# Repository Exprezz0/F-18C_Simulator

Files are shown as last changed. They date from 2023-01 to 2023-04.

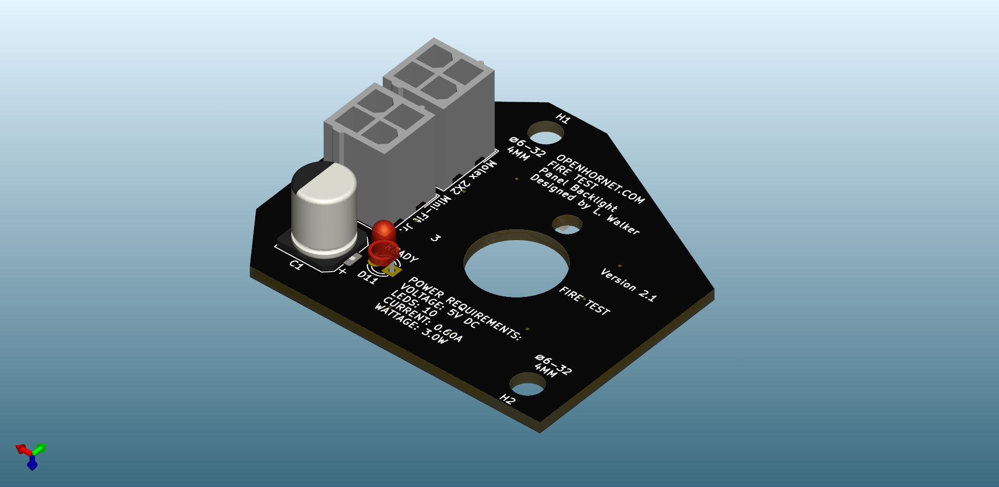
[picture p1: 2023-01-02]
ECAD/PCBs/Backlight PCBs/Backlighting_Type A/FIRE TEST PANEL/Assets/FIRE TEST PANEL_BOT-ISO.png

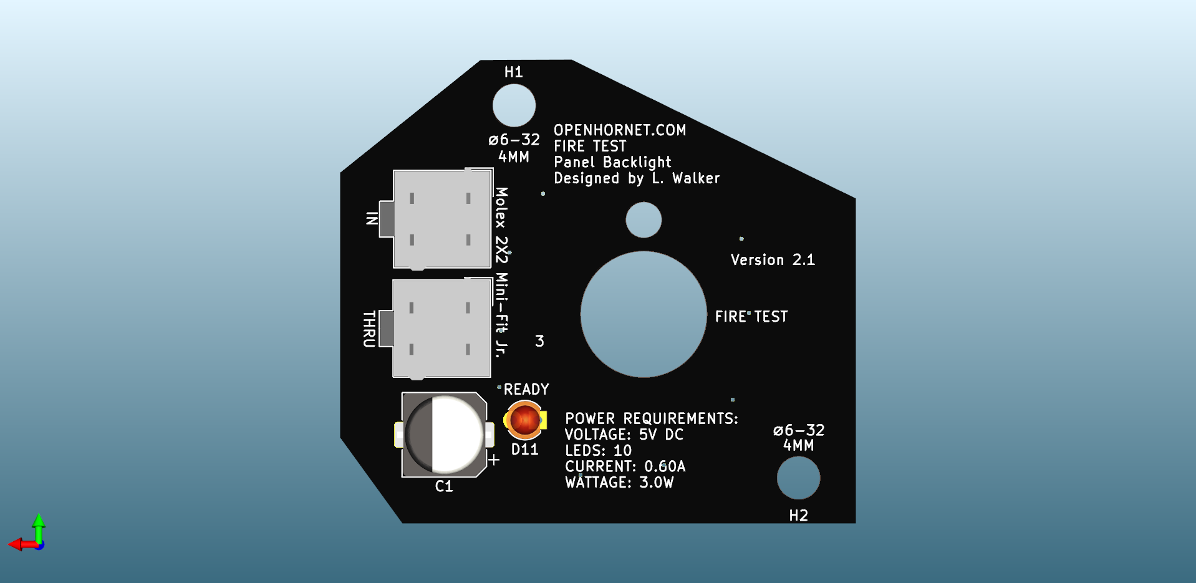
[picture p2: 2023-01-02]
ECAD/PCBs/Backlight PCBs/Backlighting_Type A/FIRE TEST PANEL/Assets/FIRE TEST PANEL_BOT.png

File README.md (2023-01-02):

# F/A-18C Simulator Cockpit
Based on OpenHornet design (https://www.OpenHornet.com) - Modified for Personal Use.  

# Disclaimer
The files located within this repository have been created from scratch or modified from existing OpenHornet files and were adapated to suit my personal needs based on available resources.   There may or may not be easier or more efficient ways to produce some of the systems/designs here, but for the purpose of learning and gaining knowledge and experience designing, engineering, manufacturing, resourcing, etc., I've decided to take the more difficult path.

1:  Any modification, usage, sharing, distribution, etc falls under the same licenses and legal definitions that apply to OpenHornet.

2:  It is not 100% complete.  I will add to it as I continue to progress my own pit.

3:  Use at your own risk.  The files within the repo may or may not be up to date with the current OH design.  I've already cut, printed, and engraved most of the project and have modified various files to fit my own personal needs and resources.

4:  I've done my best to keep it organized.  If you see something out of place (meaning: incorrect directory, not missing.  See #2), please PM me and I'll fix it.

5:  Most importantly, while the files are 94.271% OpenHornet, there are modifications in there.  Please do not reference any files taken from my repository in the OpenHornet Discord.  It's not the developers, contributors, or testers responsibility to answer questions or fix issues associated with 3rd party files.  I'll be more than happy to answer questions offline, and if it relates directly to OpenHornet, we can bring up the issue here.

# File Structure

**This repository has been organized in the following manner:**

The MCAD folder contains all .STL, .SVG, .DXF files types for all mechanical manufacturing.  Within the MCAD folder are the 5 Major Assesmbly Groups: 

```c
* MCAD
     * ASSY, UPPER INSTRUMENT PANEL
     * ASSY, LOWER INSTRUMENT PANEL
     * ASSY, CENTER TUB
     * ASSY, LEFT CONSOLE
     * ASSY, RIGHT CONSOLE
```

 Sub-assemblies for each major group will be broken down into their own individual folders.  Files organic to that sub-assembly will be located in one of several child folders based on the material they are comprised of.  (Resin, PETG, MDF, Acrylic).
    
Additionally, each major assembly will also have:
   1. "**ALL PANEL PLATES**" folder; includes the *Backlight Plate, Light Plate*, and *Legend Plate* folders associated with that major assembly

   2. "**ALL KNOBS**" folder; includes all knobs associated with that major assembly.

   3. "**RANDOM COTS PARTS**" folder; includes any COTS that could be resin printed or manufactured without having to order or purchase.  Examples include gears, bearings, spacers....

   4. "**OBSOLETE**" folder; contains files that are outdated or no longer belong to the OH project.

    * ASSY, RIGHT CONSOLE
        * ALL PANEL PLATES
        * ALL KNOBS
        * OBSOLETE
        * RANDOM COTS PARTS
        * OH5A2A2-1 - ASSY, WING FOLD HANDLE
        * OH5A2A1-1 - ASSY, HOOK LEVER & INDICATOR
        * OH5A1A1-1 - ASSY, RIGHT CONSOLE STRUCTURE
            * ACRYLIC
            * MDF
            * PETG
         
Lastly, each material folder will be broken down into size for reference.  If a part/object is suppose to be printed in PETG or ABS, and you can't find it, try looking in another material folder.  Sometimes I prefered resin printing or using acrylic to the defaulted PETG.

# ECAD Directory

The ECAD folder is set up similar to the MCAD directory (in this repository, and almost as identical to the official OpenHornet repository) and navigating it should be just as easy.  

As of right now, all of the backlit panels have been transitioned to KiCad 6, the libraries associated with the files are consolidated and reorganized, and new manufacturing files that includes TOP and BOTTOM Bill of Materials (BOM) have been created to facilitate easier ordering from JLCPCB.com.

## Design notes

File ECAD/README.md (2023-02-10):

OH logo
* [OpenHornet Website](https://www.openhornet.com)
* [OpenHornet Discord](https://discord.gg/G5PA5ju)
* [Donate to OpenHornet](https://www.openhornet.com/campaigns/donate/)

# **ECAD DIRECTORY INFORMATION**

The purpose of this guide is to help enable the end-user to successfully accomplish the following:  
*   1:  Facilitate navigation of the file structure.
*   2:  Provide clarification regarding the manufacturing process of PCB's related to OpenHornet using JLCPCB.com
*   2:  How to install KiCad 6 and set up libraries associated with OpenHornet. _(optional)__

 _Note:  Manufacturing files have been generated accordinging to JLCPCB.com guidelines.  If choosing a different PCB Manufacturer, make sure to research their formatting standards and modify the necessary manufacturing files accordingly. And if you choose to manufacture them yourself, best of luck!_

## **ECAD File Structure**

The ECAD Directory has been organized to facilitate the end user, regardless of skill or knowledge, in acquiring the necessary files needed to: 
* A: make adjustments to individual PCB's as needed using ECAD software (KiCad)
     * _and/or_
* B: submit an online order to have the PCB manufactured and assembled by a company.

**The structure of the ECAD Directory is summarized below:**
ECADDirectory

Example

1. Within each labeled PCB folder, there will be a folder called "JLCPCB" and inside of that folder will be two additional folders called "gerbers" and "production_files"
2. **_All files you need for manufacturing are located in the "production_files" folder.  The gerbers are already compressed in a .zip file labeled the same way as the PCB folder their located in._** 
3. Additionally, there will be 3 .csv files:  _**BOM_BOTTOM-'NAME OF PANEL'.csv**_,  _**BOM_TOP-'NAME OF PANEL'.csv**_, AND  _**CPL-'NAME OF PANEL'.csv**_ that will contain a Bill of Materials for both components located on both the top and bottom of the PCB, as well as the CPL used for placing the components.

***PLEASE READ:  YOU NEED TO DOWNLOAD ALL 4 FILES WITHIN THE PRODUCTION_FILES FOLDER.  NOT JUST THE .ZIP.***



## **PCB Manufacturing**

At the moment, all manufacturing files have been standardized to allow for fabrication using JLC @ (https://www.jlcpcb.com).  You may use another PCB manufacturer of your choosing; however, you will be responsible for ensuring the required files meet specifications and formatting. 

***For details on the JLCPCB manufacturing process, please see the "MANUFACTURING.MD" located in the ECAD folder or CLICK THE LINK BELOW***

  [JLCPCB MANUFACTURING PROCESS & FAQ](MANUFACTURING.MD)

## **Installation of KiCad and OpenHornet Libraries _(OPTIONAL)_**

*Installation of KiCad and OpenHornet Libraries is only required if you choose to contribute.  See [CONTRIBUTING.MD](https://github.com/jrsteensen/OpenHornet/blob/v1.0.0-beta1/CONTRIBUTING.md) for more details.*

Before we begin, it is assumed that you have:
*  1:  Downloaded the latest version of KiCad _(currently KiCad 6.0.9)_ and installed it on your computer.  
*  2:  Cloned the OpenHornet repository

#### STEP ONE:  Configure Paths & Create Environmental Variables
Open up a new or previous project in KiCad.  For this example, I'll be using the MASTER ARM PANEL.  In the Top Menu: Navigate to Preferences --> Configure Paths



Create 4 new variables with the following Names and paths:
*  1:  KICAD6_USER_OH_3DMODELS
*  2:  KICAD6_USER_OH_FOOTPRINTS
*  3:  KICAD6_USER_OH_SYMBOLS
*  4:  KICAD6_USER_OH_TEMPLATES

The paths can be anywhere so long as it points to your Open Hornet directory.  _Make sure the OH_FOOTPRINTS variable points to the \ECAD\lib folder and **NOT** \ECAD\lib\OH_FOOTPRINTS.PRETTY_.



#### STEP TWO:  Add OpenHornet Symbol and Footprint Libraries

With the project window open, navigate to Preferences --> Manage Symbol Libraries.



When the Symbol Libraries window opens, make sure you are in the **"Global Libraries"** tab and then check the bottom for a section called "Path Substitutions".  Ensure that the environmental variable that you just created is located in there.  _If you're using a previous version of KiCad or have older libraries still installed, click "Migrate Libraries" after selecting them to transition them to KiCad 6.  The library format will say "Legacy" if its outdated, and "KiCad" if it's compatible. If you have a fresh install, you can skip this step._

Next, click on the folder icon near the bottom left and navigate to  _\ECAD\lib\OH_Symbols_ and add the four kicad_sym files located in the folder.  This will automatically populate the fields with the information.  Alternatively, you click on the "+" icon to add a new row and manually enter the information for your libraries.  

Finally, check the Library Path to make sure your environmental variable was adopted.



Do the same thing for the footprint Libraries:



#### STEP THREE:  Add ***KiCAD JLCPCB tools*** Plugin (Optional)
Bouni @ https://github.com/bouni/kicad-jlcpcb-tools has developed a great plugin that allows you to search the JLCPCB parts database, assign LCSC article numbers to your parts, and generate production files for JLCPCB.

*  1: Click **"Plugin and Content Manager"**
*  2: When the dialog box opens, click on **"Manage"**
*  3: When the **"Manage Repositories"** dialog box opens, Click the "+" sign and add the following:
    *  Name:  Bouni's KiCad repository
    *  URL:  https://raw.githubusercontent.com/Bouni/bouni-kicad-repository/main/repository.json
*  4: Once downloaded and installed, hit "Apply Changes"



### Congratulations. That's all you have to do.  The 3D models that are associated with the footprints will automatically be linked as long as the OH_Footprints are used.

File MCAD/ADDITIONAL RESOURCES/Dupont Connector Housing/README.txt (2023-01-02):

Dupont Connector Holder 4 Pins by jonweb on Thingiverse: https://www.thingiverse.com/thing:5659645

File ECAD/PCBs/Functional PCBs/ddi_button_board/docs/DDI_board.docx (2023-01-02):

# DDI and AMPCD boards

This document contains information about the hardware design for DDI and AMPCD panels.

# Modular vs non modular

## Option A: Modular DDI

A modular approach allows for simpler hardware thanks to the reuse of parts, this approach requires a total of 8 DDI/4 PCBs + four AMPCD/4 + three (3) Nano shields made for this purpose.

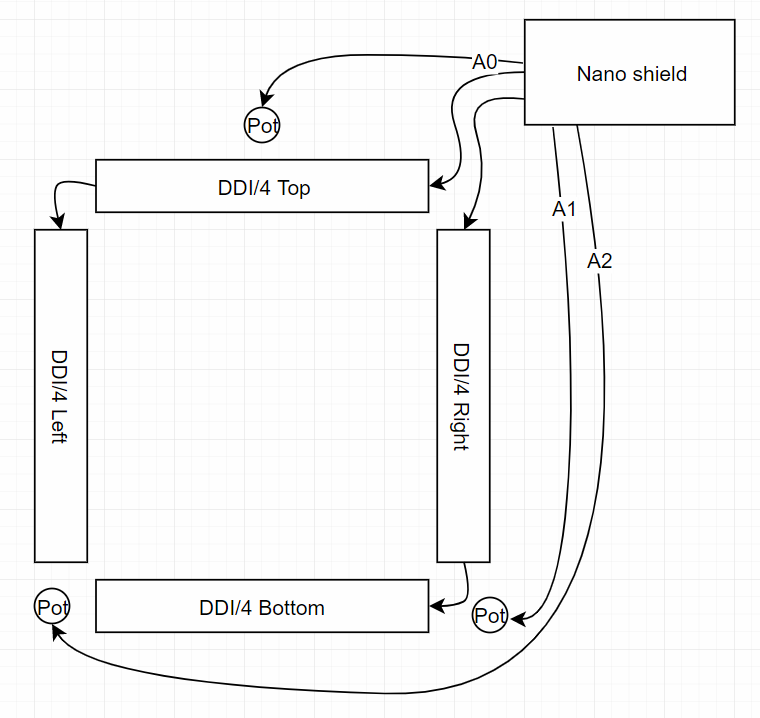
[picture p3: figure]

## Option B: Full board

This approach reuses 100% schematic from modular DDI but two different boards need to be created, one for LEFT/RIGHT DDI panels and one for AMPCD. One thing to consider is that this approach requires three boards of approximately 158mm (6.23in) x 167mm (6.59in) in size.

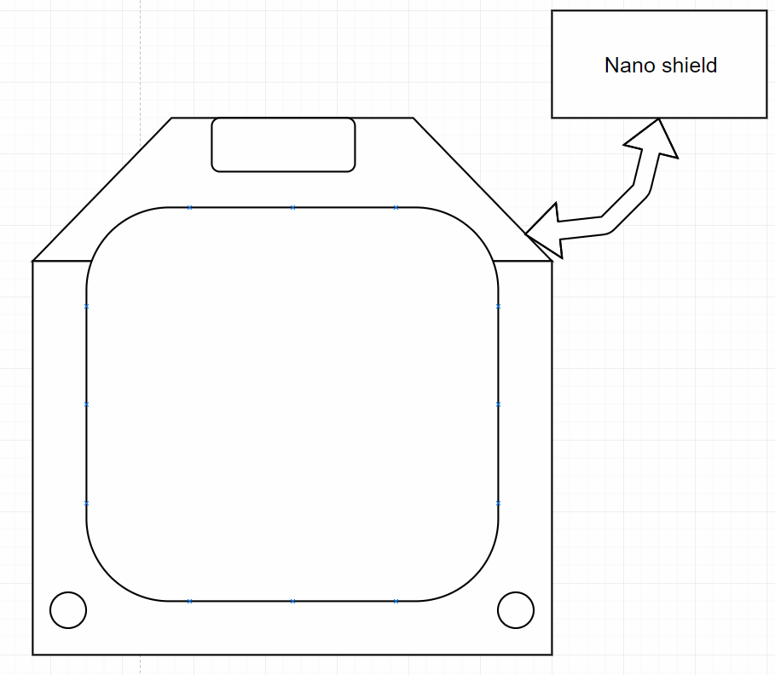
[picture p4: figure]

# Modular detailed

## Left and Right DDI panels

Left and right panels are identical, the only way to differentiate between these two panels is what option is installed on the Nano shield (see Nano shield options for more information)

## AMPCD panel

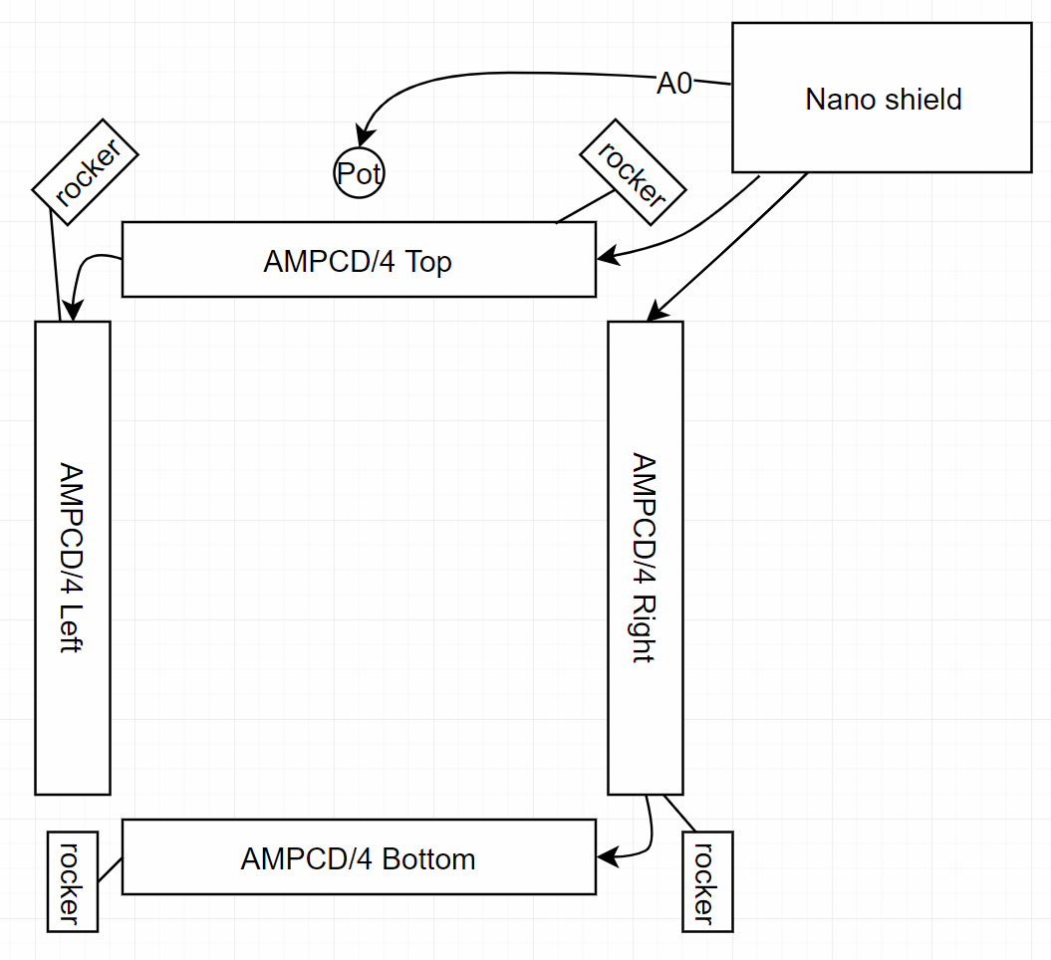
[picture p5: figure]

The AMPCD panel differentiates from the DDI panels thanks to the use of rocker switches, the rocker switches are handled the same way as the OSBs.

## Nano shield options

The Nano shield boards allow for software to recognize the position in the cockpit, this is done by configuring the pull-ups and pull-downs according to the following table.

Option | Requires
Left DDI | d1 Pull down, d0 Pull up
Right DDI | d1 Pull up, d0 Pull down
AMPCD | d1 pull up, d0 pull up

## DDI/4 and AMPCD/4 Addressing

Each one of the boards contains a TCA9534A IO expander, this device can be configured with up to 8 different I2C addresses, upon boot, and Software shall poll all 8 addresses in order to identify what modules are installed. The address assignation is done according to this table.

Location | I2C Address
DDI/4 Top | 0b0111000
DDI/4 Left | 0b0111001
DDI/4 Right | 0b0111010
DDI/4 bottom | 0b0111011

## Button press handling

Each DDI/4 board uses IO expander capable of generating an interrupt when any button is pressed, the PCB provides two button debouncing mechanisms in order to prevent fake interrupts or multiple interrupts in a short period of time.

The debouncing mechanism consists of:

- 6 hysteresis triggered inverted mechanism with <5ms detection delay. These circuits provide full debouncing capabilities and are intended to be used for the five OSBs + an extra button. These inputs filter most of the fake interrupts created by button bouncing by allowing only 0v or 5v outputs. One important distinction is that the values of the switch are inverted and software needs to take this into account.
- 2 non inverted switches with ~5ms detection delay intended for rockers (AMPCD only). These inputs provide medium debouncing capability by smoothing any glitches, fake interrupts may be triggered depending on the receiving IC specific thresholds.

Any change of any of these inputs will cause an interrupt to be fired and software can now read the status of all four DDI/4 blocks in order to determine which button was pushed. If necessary software might add extra debouncing time to compensate for flaky connections and bouncy switches.

The following pictures represent a simulation of the debouncing hardware please notice that the RC constant has been calculated for 10ms leading to a sub 5ms detection delay in most cases.

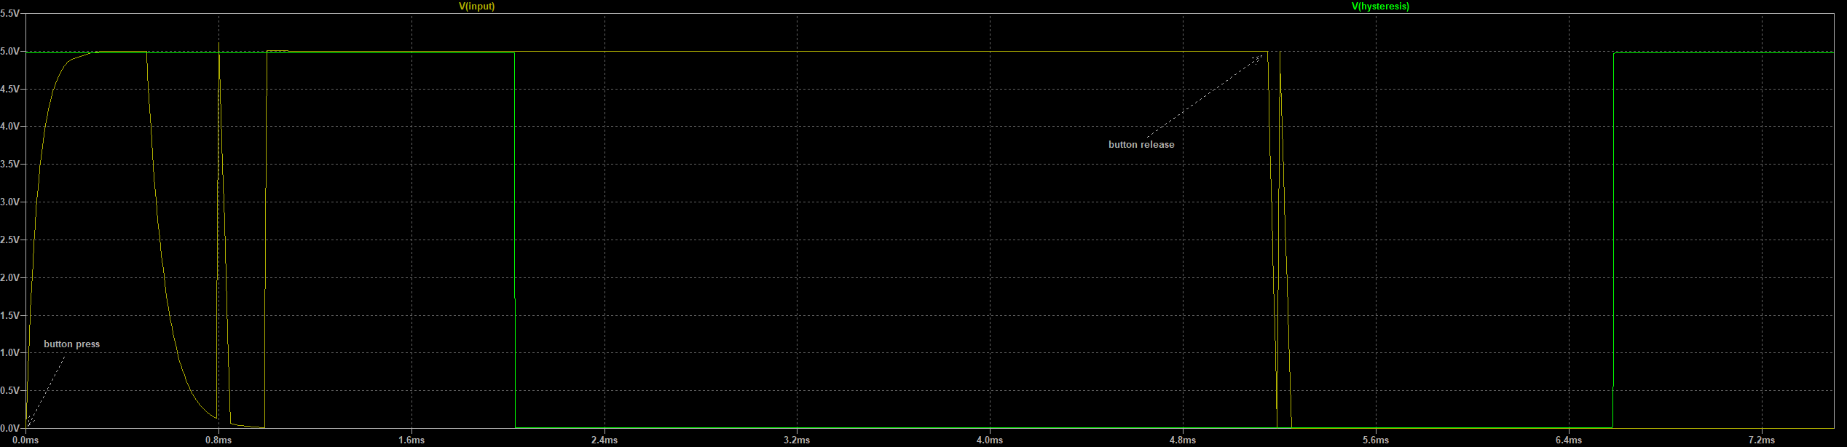
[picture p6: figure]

Figure 1 Button press detection with hysteresis

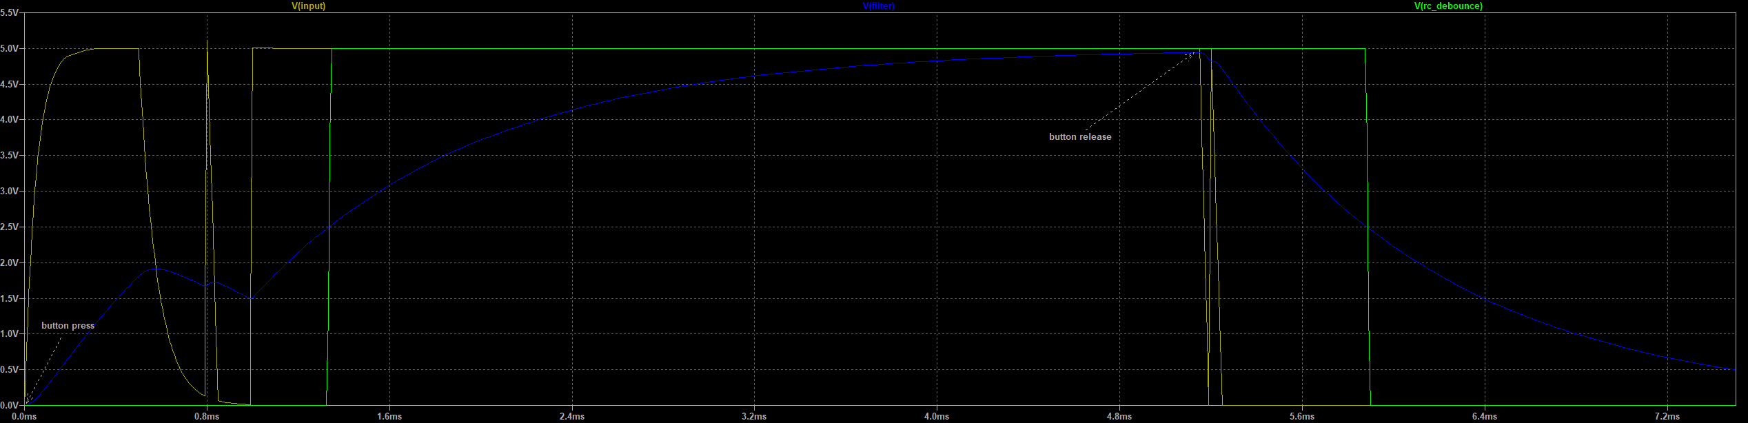
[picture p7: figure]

Figure 2 low pass detection using a 2.5v threshold example

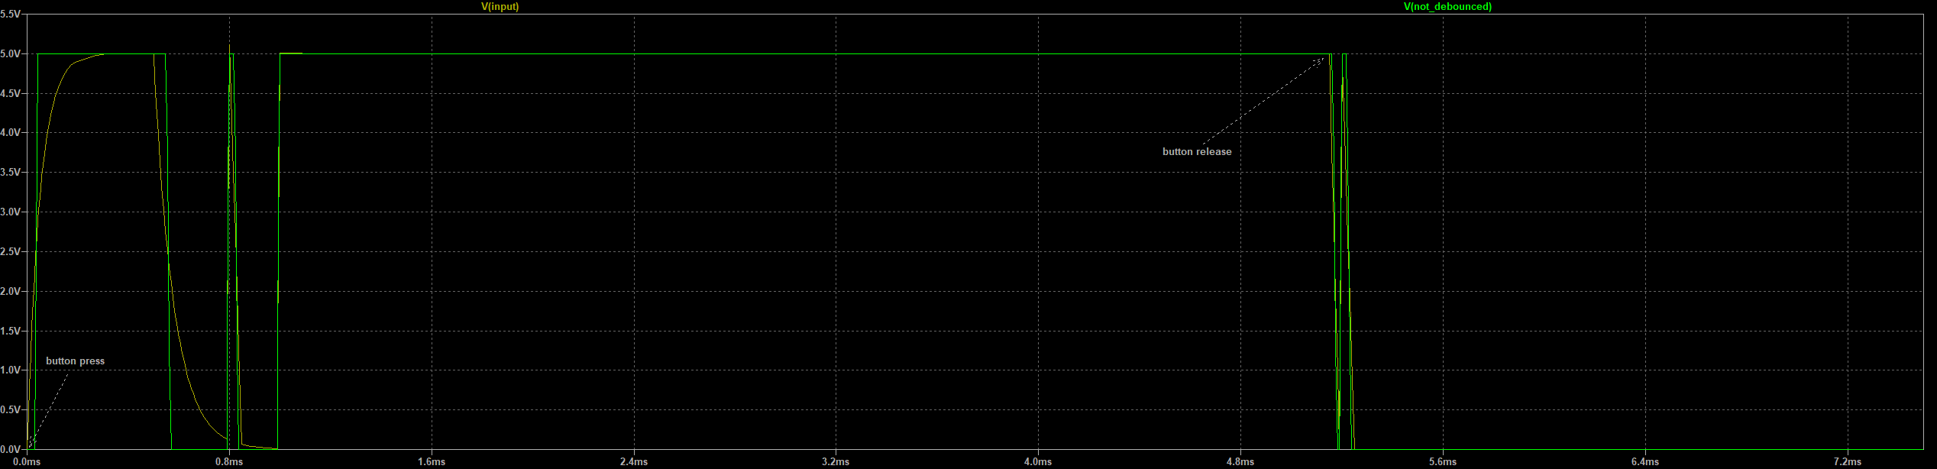
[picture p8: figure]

Figure 3 Raw signal detection (no debouncing)

## Potentiometer handling

The potentiometers installed in each DDI are read from A0-A2 pins from Arduino according to this table:

potentiometer | Pin
<<find names>> | A0
| A1
| A2

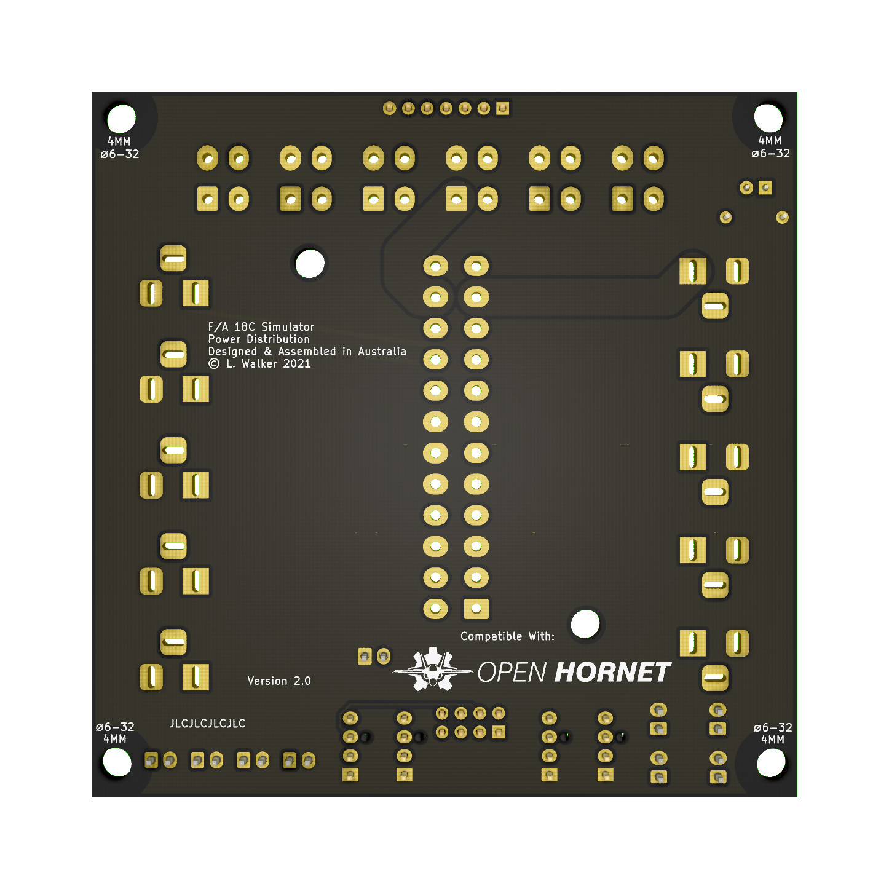
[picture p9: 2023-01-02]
ECAD/PCBs/OH_Specific/Backlighting_Type A/Power_Distro_PCB_V2/Power Distro PCB V2 Bottom.png

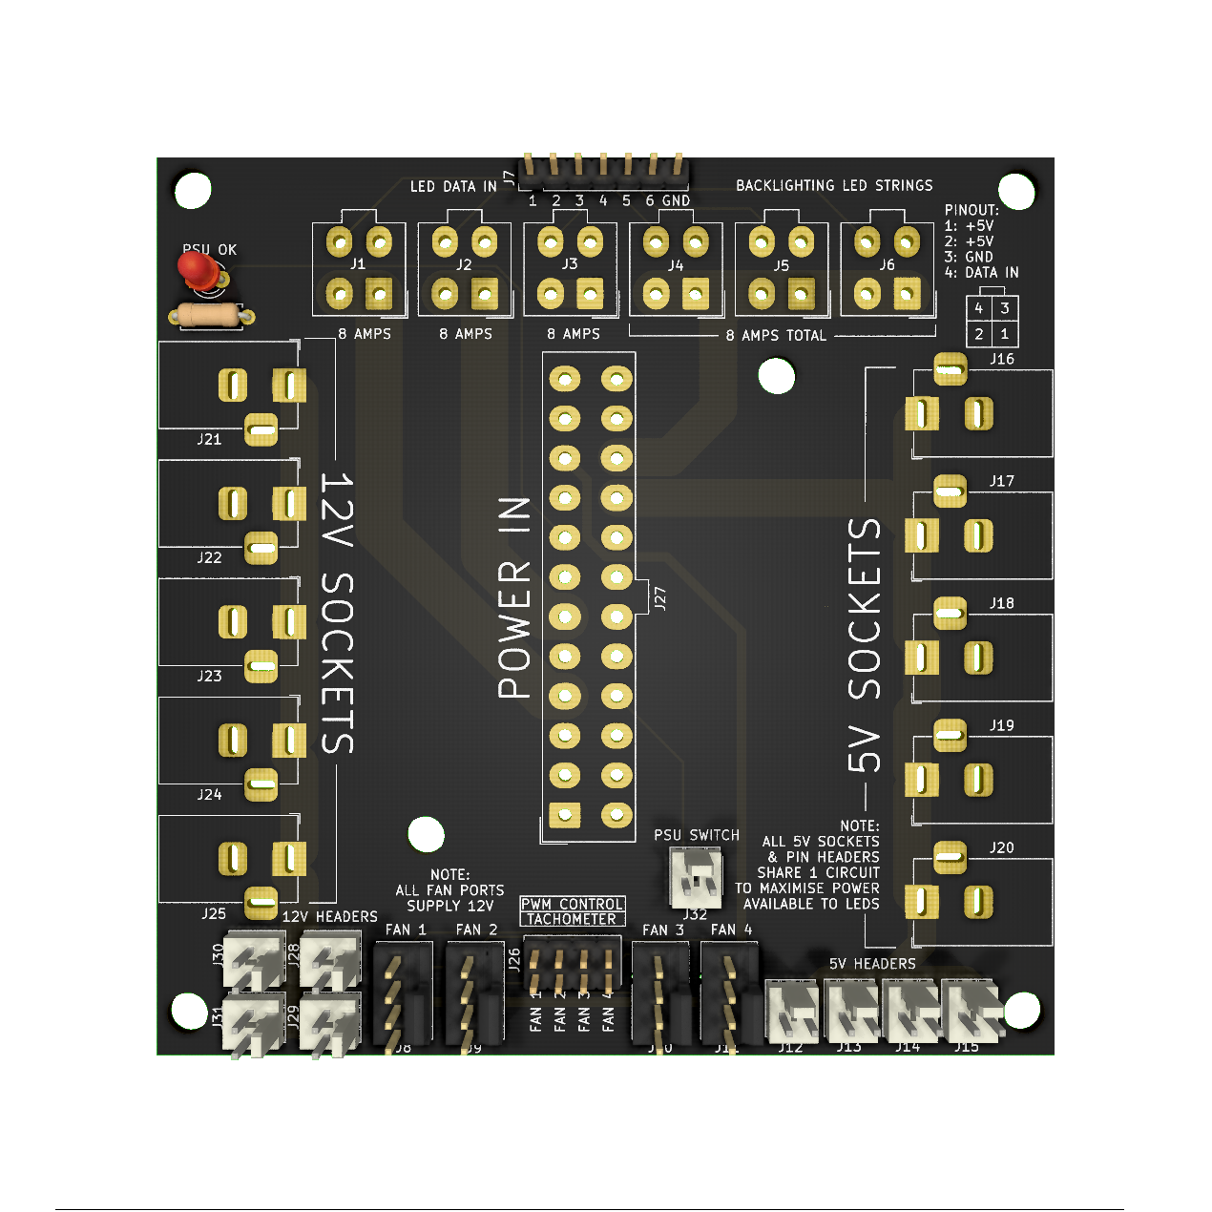
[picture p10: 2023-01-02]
ECAD/PCBs/OH_Specific/Backlighting_Type A/Power_Distro_PCB_V2/Power Distro PCB V2 Front.png

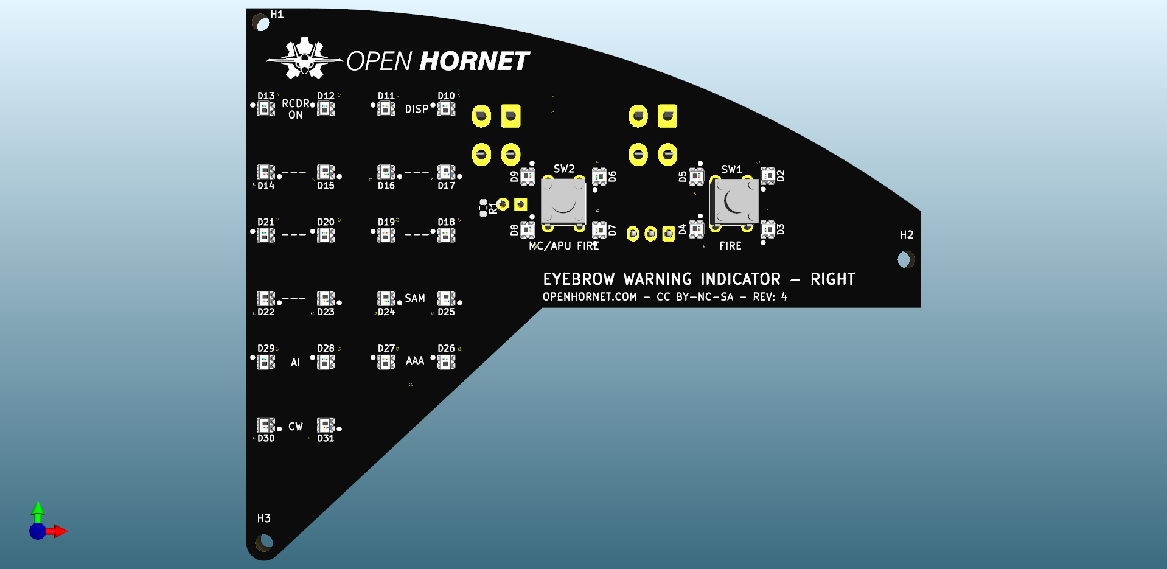
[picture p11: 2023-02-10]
ECAD/PCBs/Functional PCBs/EYEBROW WARNING INDICATOR_RIGHT/Assets/EYEBROW WARNING INDICATOR_RIGHT-TOP.png

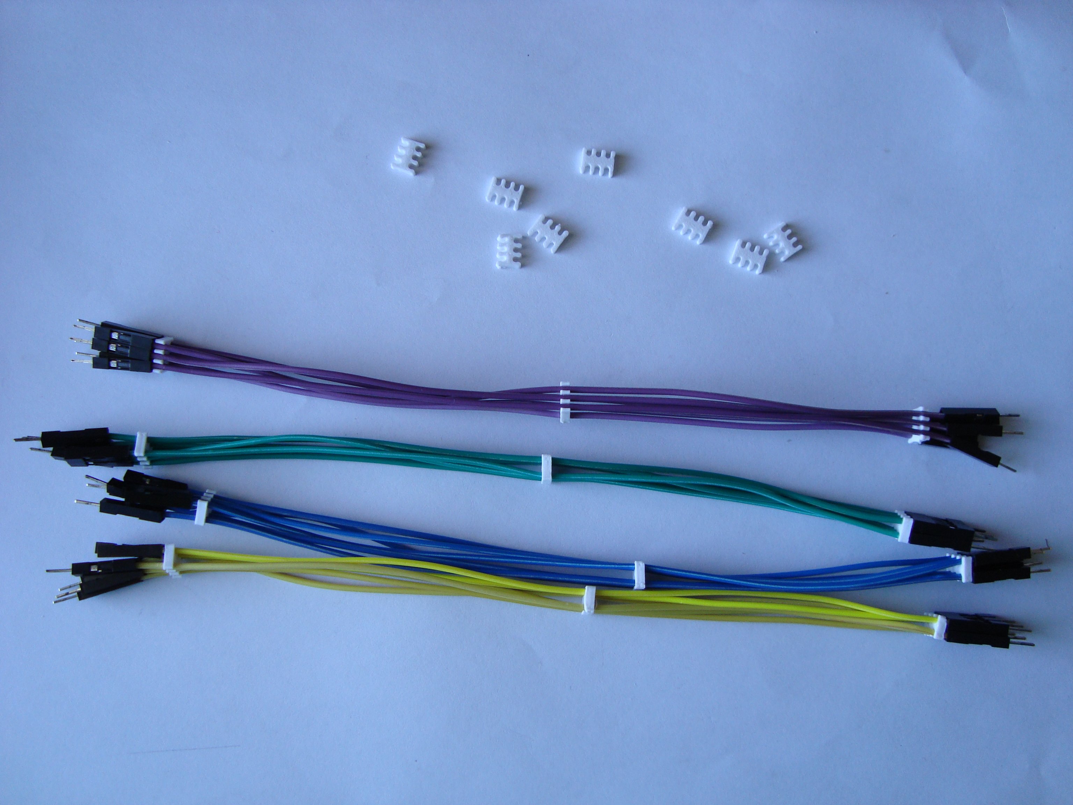
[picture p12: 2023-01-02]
MCAD/ADDITIONAL RESOURCES/images/dupon5.jpg

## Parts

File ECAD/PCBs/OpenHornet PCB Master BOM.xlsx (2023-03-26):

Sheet: MASTER
 | Value | Designator | Footprint | Quantity | Part Number
Arduino_1pin | MH | MK1, MK3, MK4 | Arduino_1pin | 3
Arduino_Mini_Pro_No_Programming_Header | ProMini_NoProgrammingHeader | U1 | Arduino_Mini_Pro_No_Programming_Header | 1
BR10K_Pot_11mm_x_11mm | VOL2 | POT2, POT3, POT1 | BR10K_Pot_11mm_x_11mm | 3
Bourns_3310Y | DMR | RV2, RV1 | Bourns_3310Y | 2
C116539 | MAX487EESA+T | U1, U1, U1, U1, U1, U1 | SOIC-8_3.9x4.9mm_P1.27mm | 6
C130026 | TCA9548APWR | U1 | TSSOP-24_4.4x7.8mm_P0.65mm | 1
C130723 | LED | D1, D10, D11, D12, D13, D14, D15, D16, D17, D18, D19, D2, D20, D21, D22, D23, D24, D3, D4, D5, D6, D7, D8, D9, D1, D10, D11, D12, D13, D14, D17, D18, D19, D2, D20, D21, D22, D23, D24, D25, D26, D27, D28, D29, D3, D30, D31, D32, D4, D5, D6, D7, D8, D9, D1, D10, D11, D12, D13, D14, D15, D16, D17, D18, D19, D2, D20, D21, D22, D23, D24, D25, D26, D27, D28, D29, D3, D30, D31, D32, D33, D34, D35, D36, D4, D5, D6, D7, D8, D9 | LED_0402_1005Metric | 90
C131334 | OUTB GRIP | J5 | JST_PH_B4B-PH-K_1x04_P2.00mm_Vertical | 1
C131337 | MAX DETENT | J10, J8, J9, CAGE1 | JST_PH_B2B-PH-K_1x02_P2.00mm_Vertical | 4
C131339 | IN SERVO | J11, J12, J6, J7, ANT1, CM1, SPDBRK1 | JST_PH_B3B-PH-K_1x03_P2.00mm_Vertical | 7
C131342 | COMS | COM1 | JST_PH_B6B-PH-K_1x06_P2.00mm_Vertical | 1
C13585 | 10uF | C2, C3, C1 | C_1206_3216Metric | 3
C14663 | 0.1uF | C1, C2, C3, C4, C5, C10, C11, C12, C13, C2, C3, C4, C5, C6, C7, C8, C9, C10, C11, C12, C13, C14, C15, C16, C17, C18, C19, C2, C20, C21, C22, C23, C24, C25, C3, C4, C5, C6, C7, C8, C9, C10, C100, C101, C102, C103, C104, C105, C106, C107, C108, C109, C11, C110, C12, C13, C14, C15, C16, C17, C18, C19, C2, C20, C21, C22, C23, C24, C25, C26, C27, C28, C29, C3, C30, C31, C32, C33, C34, C35, C36, C37, C38, C39, C4, C40, C41, C42, C43, C44, C46, C47, C48, C49, C5, C50, C51, C52, C53, C54, C55, C56, C57, C58, C59, C6, C60, C61, C62, C63, C64, C65, C66, C67, C68, C69, C7, C70, C71, C72, C73, C74, C75, C76, C77, C78, C79, C8, C80, C81, C82, C83, C84, C85, C86, C87, C88, C89, C9, C90, C91, C92, C93, C94, C95, C96, C97, C98, C99, C10, C11, C12, C13, C14, C15, C16, C17, C18, C19, C2, C20, C21, C22, C23, C24, C25, C26, C27, C28, C29, C3, C30, C31, C32, C33, C34, C35, C36, C37, C38, C39, C4, C40, C41, C42, C43, C44, C45, C46, C47, C48, C49, C5, C50, C51, C52, C53, C54, C55, C56, C57, C58, C59, C6, C60, C61, C62, C7, C8, C9, C10, C11, C12, C13, C14, C15, C16, C17, C18, C19, C2, C20, C21, C22, C23, C24, C25, C3, C4, C5, C6, C7, C8, C9, C10, C11, C12, C13, C14, C15, C16, C17, C18, C19, C2, C20, C21, C3, C4, C5, C6, C7, C8, C9, C10, C11, C12, C13, C14, C15, C16, C17, C2, C3, C4, C5, C6, C7, C8, C9, C3, C4, C5, C6, C7, C10, C11, C12, C13, C14, C15, C16, C2, C3, C4, C5, C6, C7, C8, C9, C1, C2, C3, C4, C5, C6, C7, C8, C9, C11, C12, C13, C14, C15, C2, C3, C4, C5, C6, C7, C8, C9, C10, C11, C12, C13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 | C_0603_1608Metric | 553
C157923 | TM GRIP | J4 | JST_PH_S5B-PH-K_1x05_P2.00mm_Horizontal | 1
C157993 | INB GRIP | J4, J2/OUTPUT | JST_PH_B5B-PH-K_1x05_P2.00mm_Vertical | 2
C17437 | 120 | R1, R1, R2 | R_0805_2012Metric_Pad1.15x1.40mm_HandSolder | 3
C2286 | Overtemp | D3 | LED_0603_1608Metric_Pad1.05x0.95mm_HandSolder | 1
C23138 | R | R1, R1, R1, R1 | R_0603_1608Metric | 4
C23162 | 4.7K | R2, R11, R12, R13, R14, R15, R19, R20, R21, R22, R23, R24, R25, R26, R27, R28, R29, R30, R31, R32, R33, R34, R35, R4, R42, R5, R6, R7, R8 | R_0603_1608Metric_Pad1.05x0.95mm_HandSolder | 29
C23179 | 2.2K | R1, R3, R1, R1, R1, R1, R1, R1, R1, R1, R1, R1, R1, R1, R1, R1, R1, R1, R1, R1, R1, R1, R1, R1, R1, R1, R1, R1 | R_0603_1608Metric_Pad1.05x0.95mm_HandSolder | 28
C234186 | 5V Accessory 1 | J12, J13, J14, J15, J16, J17, J18, J19, J20, J21, J22, J23, J24 | Molex_Mini-Fit_Jr_5566-02A_2x01_P4.20mm_Vertical | 13
C248788 | ESD5Z5V0 | D1 | D_SOD-523 | 1
C25082 | 150 | R11, R15, R16, R5, R7, R9, R10, R16, R17, R19, R20, R4, R6, R8 | R_0402_1005Metric | 14
C25099 | 270 | R14, R11, R15, R18, R21, R5, R7, R9 | R_0402_1005Metric | 8
C25105 | 33 | R10, R12, R13, R17, R18, R4, R6, R8, R2, R12, R13, R14, R16, R17, R18 | R_0402_1005Metric | 15
C25804 | 10K | R1, R2, R3, R4, R5, R6, R1, R2, R3, R1, R2, R3, R4, R5, R6, R7, R1, R1, R10, R11, R12, R13, R14, R15, R16, R17, R18, R2, R3, R4, R5, R6, R7, R8, R9, R1, R2, R3, R1, R2, R3, R1 | R_0603_1608Metric_Pad0.98x0.95mm_HandSolder | 42
C2593 | IRLML6402TRPBF | Q2, Q3, Q2, Q1, Q2, Q11, Q12, Q2, Q4, Q7, Q8 | SOT-23 | 11
C2642 | IRFB3206PBF | Q1, Q1, Q10, Q3, Q5, Q6, Q9 | TO-220-3_Vertical | 7
C265105 | X/ROLL | J1, J2, J3, J1, J2, J3 | JST_PH_S6B-PH-K_1x06_P2.00mm_Horizontal | 6
C27592 | 68 | R43, R44 | R_0603_1608Metric | 2
C2761795 | WS2812B | D1, D10, D11, D12, D13, D2, D3, D4, D5, D6, D7, D8, D9, D1, D10, D11, D12, D13, D14, D15, D16, D17, D18, D19, D2, D20, D3, D4, D5, D6, D7, D8, D9, D10, D11, D12, D13, D14, D2, D3, D4, D5, D6, D7, D8, D9, D1, D10, D11, D12, D13, D14, D15, D16, D17, D18, D19, D2, D20, D21, D22, D23, D24, D3, D4, D5, D6, D7, D8, D9, D1, D10, D100, D101, D102, D103, D104, D105, D106, D107, D108, D109, D11, D12, D13, D14, D15, D16, D17, D18, D19, D2, D20, D21, D22, D23, D24, D25, D26, D27, D28, D29, D3, D30, D31, D32, D33, D34, D35, D36, D37, D38, D39, D4, D40, D41, D42, D43, D44, D45, D46, D47, D48, D49, D5, D50, D51, D52, D53, D54, D55, D56, D57, D58, D59, D6, D60, D61, D62, D63, D64, D65, D66, D67, D68, D69, D7, D70, D71, D72, D73, D74, D75, D76, D77, D78, D79, D8, D80, D81, D82, D83, D84, D85, D86, D87, D88, D89, D9, D90, D91, D92, D93, D94, D95, D96, D97, D98, D99, D10, D11, D12, D13, D14, D15, D16, D17, D18, D19, D2, D20, D21, D22, D23, D24, D25, D26, D27, D28, D29, D3, D30, D31, D32, D33, D34, D35, D36, D37, D38, D39, D4, D40, D41, D42, D43, D44, D45, D46, D47, D48, D49, D5, D50, D51, D52, D53, D54, D55, D56, D57, D58, D59, D6, D60, D61, D62, D63, D64, D65, D66, D67, D68, D69, D7, D70, D71, D72, D73, D74, D75, D8, D9, D10, D11, D12, D13, D14, D15, D16, D17, D18, D19, D2, D20, D21, D22, D23, D24, D25, D26, D27, D28, D29, D3, D30, D31, D32, D33, D34, D35, D36, D37, D38, D39, D4, D40, D41, D42, D43, D44, D45, D46, D47, D48, D49, D5, D50, D51, D52, D53, D54, D55, D56, D57, D58, D59, D6, D60, 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 | LED_WS2812B_PLCC4_5.0x5.0mm_P3.2mm | 1075
C293502 | BL #9 | J10, J11, J2, J3, J4, J5, J6, J7, J8, J9 | Molex_Mini-Fit_Jr_5566-04A_2x02_P4.20mm_Vertical | 10
C29823 | 4.7uF | C1 | C_1206_3216Metric | 1
C318884 | RESET | SW1, SW1 | SMD-SW-4_5.1x5.1 | 2
C471416 | BRT/CRS | J4, J5, J8 | Molex_KK-254_AE-6410-03A_1x03_P2.54mm_Vertical | 3
C477924 | TCA9554PWR | U1, U2, U3, U4, U2, U1, U2, U3, U4 | TSSOP-16_4.4x5mm_P0.65mm | 9
C49678 | 0.1uF | C1, C1, C1, C1, C1, C1 | C_0805_2012Metric | 6
C504991 | Conn_01x04_Female | J12, J13, J6, J7 | Molex_KK-254_AE-6410-04A_1x04_P2.54mm_Vertical | 4
C504992 | DDI/AMPCD MAIN | J3 | Molex_KK-254_AE-6410-06A_1x06_P2.54mm_Vertical | 1
C505177 | BUS IN | J1, J2, J25, J26, J2, J1, J2, J1, J2 | Molex_Mini-Fit_Jr_5566-06A2_2x03_P4.20mm_Vertical | 9
C527089 | WS2812B-Mini | D1, D10, D11, D12, D13, D14, D15, D16, D17, D18, D19, D2, D20, D21, D22, D3, D4, D5, D6, D7, D8, D9, D25, D29, D30, D32, D33, D34, D35, D36, D37, D39, D40, D44, D45, D49, D51, D53 | LED_WS2812B-MINI_PLCC4_3.5x3.5mm_P1.75mm | 38
C585785 | Conn_01x05_Female | J14 | Molex_KK-254_AE-6410-05A_1x05_P2.54mm_Vertical | 1
C587470 | MEGA BUS 7 | J10, J11, J4, J5, J6, J7, J8, J9, J1 | Molex_Mini-Fit_Jr_5566-08A2_2x04_P4.20mm_Vertical | 9
C587474 | ABSIS BACKLIGHT | J3, J1 | Molex_Mini-Fit_Jr_5566-10A2_2x05_P4.20mm_Vertical | 2
C587483 | ATX-24 | J2 | Molex_Mini-Fit_Jr_5566-24A2_2x12_P4.20mm_Vertical | 1
C66690 | LED/ZERO | J2, J3 | PinHeader_2x02_P2.54mm_Vertical | 2
C72043 | 5V | D1, D2 | LED_0603_1608Metric_Pad1.05x0.95mm_HandSolder | 2
C72120 | ProMicro_5V/16Hz | XU1, U0, XU1, U0, U1, U1 | DIP-24_W15.24mm_Socket | 6
C7963 | LM75C | U1 | SOIC-8_3.9x4.9mm_P1.27mm | 1
C8545 | 2N7002 | Q3 | SOT-23 | 1
C879563 | MT6825GT | U1 | TSSOP-16_4.4x5mm_P0.65mm | 1
C96123 | 47uF | C1, C2, C3, C4, C1, C1, C2, C3, C4, C1 | C_1206_3216Metric | 10
C965555 | LED | D76, D77, D78, D79, D28, D29, D30, D31, D32, D4, D5, D6, D10, D11, D12, D13, D14, D15, D16, D17, D18, D19, D2, D20, D21, D22, D23, D24, D25, D26, D27, D28, D29, D3, D30, D31, D4, D5, D6, D7, D8, D9, D10, D11, D12, D13, D14, D15, D16, D17, D18, D19, D2, D20, D21, D22, D23, D24, D25, D26, D27, D28, D29, D3, D30, D31, D4, D5, D6, D7, D8, D9, D1, D10, D11, D12, D13, D14, D15, D16, D17, D18, D19, D2, D20, D21, D22, D23, D24, D25, D26, D27, D28, D29, D3, D30, D31, D32, D33, D34, D35, D36, D37, D38, D39, D4, D40, D41, D42, D5, D6, D7, D8, D9, D1, D10, D11, D12, D13, D14, D15, D16, D17, D18, D19, D2, D20, D21, D22, D23, D24, D25, D26, D27, D28, D29, D3, D30, D31, D32, D33, D34, D35, D36, D37, D38, D39, D4, D5, D6, D7, D8, D9, D10, D11, D12, D13, D14, D15, D16, D17, D18, D19, D2, D20, D21, D22, D23, D24, D25, D26, D27, D28, D29, D3, D30, D31, D32, D33, D4, D5, D6, D7, D8, D9, D10, D11, D12, D13, D14, D15, D16, D17, D18, D19, D2, D20, D21, D22, D23, D24, D25, D26, D27, D28, D29, D3, D30, D31, D32, D33, D34, D4, D5, D6, D7, D8, D9 | WS2812-2020 | 218
C98733 | EXTERNAL 5V IN | J28, J30 | AMASS_XT60-M_1x02_P7.20mm_Vertical | 2
C98734 | BUTTKICKER AMP | J29 | AMASS_XT60-F_1x02_P7.20mm_Vertical | 1
LED_D3.0mm | Green LED | D5, D2, D1, D3, D4 | LED_D3.0mm | 5
Molex_Mini-Fit_Jr_5569-06A1_2x03_P4.20mm_Horizontal | BUS OUT | J2, J1 | Molex_Mini-Fit_Jr_5569-06A1_2x03_P4.20mm_Horizontal | 2
OPB61x | OPB615 | U1 | OPB61x | 1
PinHeader_1x02_P2.54mm_Vertical | BUS ENABLE | JP1, J16, J14, J13, J10 | PinHeader_1x02_P2.54mm_Vertical | 5
PinHeader_1x03_P2.54mm_Horizontal | Conn_01x03_Male | J1 | PinHeader_1x03_P2.54mm_Horizontal | 1
PinHeader_1x03_P2.54mm_Vertical | Fan voltage selector | J16, J17, J15, J8, J2 | PinHeader_1x03_P2.54mm_Vertical | 5
PinHeader_1x04_P2.54mm_Vertical | I/O | J1 | PinHeader_1x04_P2.54mm_Vertical | 1
PinHeader_1x05_P2.54mm_Vertical | SARI_CAGE | J9 | PinHeader_1x05_P2.54mm_Vertical | 1
PinHeader_2x01_P2.54mm_Vertical | PWR | J1 | PinHeader_2x01_P2.54mm_Vertical | 1
PinHeader_2x02_P2.54mm_Vertical | ACC PWR | J7 | PinHeader_2x02_P2.54mm_Vertical | 1
PinHeader_2x05_P2.54mm_Vertical | STEPPER | J5, J7, J5 | PinHeader_2x05_P2.54mm_Vertical | 3
PinHeader_2x07_P2.54mm_Vertical | ALTIMETER | J6, J5, J1 | PinHeader_2x07_P2.54mm_Vertical | 3
PinHeader_2x10_P2.54mm_Vertical | DIGITAL #2 | J5, J6, J4 | PinHeader_2x10_P2.54mm_Vertical | 3
PinHeader_2x11_P2.54mm_Vertical | DIGITAL #1 | J3 | PinHeader_2x11_P2.54mm_Vertical | 1
PinSocket_1x06_P2.54mm_Vertical | GND | J2 | PinSocket_1x06_P2.54mm_Vertical | 1
PinSocket_2x16_P2.54mm_Vertical | THRU | J1 | PinSocket_2x16_P2.54mm_Vertical | 1
R_Axial_DIN0204_L3.6mm_D1.6mm_P5.08mm_Horizontal | 220 | R1 | R_Axial_DIN0204_L3.6mm_D1.6mm_P5.08mm_Horizontal | 1
R_Axial_DIN0207_L6.3mm_D2.5mm_P7.62mm_Horizontal | 150 | R1, R4, R5, R3, R2 | R_Axial_DIN0207_L6.3mm_D2.5mm_P7.62mm_Horizontal | 5
SCRATCHPADBACKLIGHT | UFCScratchPadBacklight | BL1 | SCRATCHPADBACKLIGHT | 1
SCRATCHPADLCD | UFCScratchpadLCD | DS1 | SCRATCHPADLCD | 1
SW_TH_Tactile_Omron_B3F-10xx | ECM JETT | SW1, SW1, SW2, SW3, SW2, SW1, SW2, SW1, SW6, SW5, SW4, SW3, SW2, SW1, SW5, SW4, SW3, SW2, SW1, SW5, SW4, SW3, SW2, SW1 | SW_TH_Tactile_Omron_B3F-10xx | 24
SolderJumper-2_P1.3mm_Open_RoundedPad1.0x1.5mm | RST | RST1 | SolderJumper-2_P1.3mm_Open_RoundedPad1.0x1.5mm | 1
TL1240GQ | TL1240GQ | SW1, SW2, SW3, SW4, SW5, SW6, SW7, SW8, SW9, SW10, SW11, SW12, SW13, SW14, SW16, SW17, SW18, SW19, SW20, SW21, SW22, SW23, SW24, SW25, SW26, SW27, SW28, SW15, SW1, SW2, SW3, SW4, SW5, SW6, SW7, SW8, SW9, SW10, SW11, SW12, SW13, SW14, SW15, SW16, SW17, SW18, SW19, SW20, SW1, SW2, SW3, SW4, SW5, SW6, SW7, SW1, SW2, SW3, SW4, SW5, SW6, SW7, SW8, SW9, SW10, SW11, SW12, SW13, SW14, SW15, SW16, SW17, SW18, SW19 | TL1240GQ | 74
UFCOptionDigit | UFCOptionDigit | DS6, DS5, DS4, DS3, DS2 | UFCOptionDigit | 5
UFCSingleDigit | UFCSingleDigit | DS8, DS7 | UFCSingleDigit | 2
VID29-02 | VID29-02 | M1, M1 | VID29-02 | 2
x40_8798 | X40_8798 | M1 | x40_8798 | 1
0 | I/O #1 | J3, J4 | PinHeader_2x06_P2.54mm_Vertical | 2 | C124388
1 | CH1 OUT | J3, J4 | JST_PH_B2B-PH-K_1x02_P2.00mm_Vertical | 2 | C131337
2 | C | C2, C3, C4, C5, C1, C10, C11, C12, C7, C8, C9 | C_0603_1608Metric | 11 | C14663
3 | AW9523BTQR | U1, U6, U7 | WQFN-24-1EP_4x4mm_P0.5mm_EP2.6x2.6mm | 3 | C148077
4 | 10uF | C1, C2, C3, C4 | C_0805_2012Metric | 4 | C15850
5 | 4.7K | RN1, RN2 | R_Array_Convex_4x0603 | 2 | C1980
6 | 1k | R1, R36, R38 | R_0603_1608Metric | 3 | C21190
7 | 2K | R3, R37, R39 | R_0603_1608Metric | 3 | C22975
8 | 4.7k | R10, R40, R41, R9 | R_0603_1608Metric | 4 | C23162
9 | R | R1 | R_0603_1608Metric | 1 | C23179
10 | 33 | R1 | R_0402_1005Metric | 1 | C25105
11 | 10K | R2 | R_0603_1608Metric | 1 | C25804
12 | IRFB3206PBF | Q1, Q4 | TO-220-3_Vertical | 2 | C2642
13 | IN | J1 | JST_PH_S6B-PH-K_1x06_P2.00mm_Horizontal | 1 | C265105
14 | ANALOGSTICK_CENTERPUSH | JOY1 | RKJXV12 | 1 | C2687349
15 | GN1640T | U2, U3, U4, U5 | SSOP-28_3.9x9.9mm_P0.635mm | 4 | C2758330
16 | WS2812B | D1, D10, D11, D12, D13, D2, D3, D4, D5, D6, D7, D8, D9 | LED_WS2812B_PLCC4_5.0x5.0mm_P3.2mm | 13 | C2761795
17 | ECM JETT | J3, J3 | Molex_KK-254_AE-6410-02A_1x02_P2.54mm_Vertical | 2 | C293316
18 | Conn_01x04_Female | J1, J2, J1, J2, J1, J2, J1, J2, J1, J2, J1, J2, J1, J2, J1, J2, J1, J2, J1, J2, J1, J2, J1, J2, J1, J2, J1, J2, J1, J2, J1, J2, J1, J2, J1, J1, J2, J1, J2, J1, J2, J1, J2, J1, J2, J1, J2, J1, J2, J1, J2, J1, J2, J1, J2, J1, J2, J3, J4, J3, J4, J1, J2, J1, J2, J1, J3, J1, J2, J1, J2, J1, J2 | Molex_Mini-Fit_Jr_5566-04A_2x02_P4.20mm_Vertical | 73 | C293502
19 | GND | J5 | PinHeader_1x06_P2.54mm_Vertical | 1 | C37208
20 | C_Polarized | C1, C1, C1, C1, C1, C1, C1, C1, C1, C1, C1, C1, C10, C1, C1, C1, C1, C1, C1, C1, C1, C1, C1, C1, C1, C1, C1, C1, C1, C1, C1 | CP_Elec_8x10 | 31 | C445083
21 | MASTER MODE | J4, J3, J3 | Molex_KK-254_AE-6410-03A_1x03_P2.54mm_Vertical | 3 | C471416
22 | Conn_01x06 | J1 | Molex_KK-254_AE-6410-06A_1x06_P2.54mm_Vertical | 1 | C504992
23 | BUS IN | J1, J2 | Molex_Mini-Fit_Jr_5566-06A2_2x03_P4.20mm_Vertical | 2 | C505177
24 | ACC PWR | J6 | PinHeader_2x02_P2.54mm_Vertical | 1 | C66690
25 | HT1621B | U1 | LQFP-48_7x7mm_P0.5mm | 1 | C7532
26 | 8WayHat_CenterPush | S1 | RKJXM10 | 1 | C97432
27 | LED | D21, D1, D25, D110, D30, D1, D1, D1, D45, D24, D11, D33, D10, D17, D25, D1, D1, D24, D1, D17, D82, D1, D36, D1, D1, D1, D1, D1, D1 | LED_D3.0mm | 29 | LED_D3.0mm
28 | 1938 | D2, D1, D2, D1 | LED_D5.0mm-4_RGB | 4 | LED_D5.0mm-4_RGB
29 | +5VIN | J1 | PinHeader_1x02_P2.54mm_Vertical | 1 | PinHeader_1x02_P2.54mm_Vertical
30 | CH1 PWR SEL | JP1, JP2, JP5, JP4, JP2, JP1, JP2, JP1, J4, J3, J9, J8, J4, J3 | PinHeader_1x03_P2.54mm_Vertical | 14 | PinHeader_1x03_P2.54mm_Vertical
31 | TO UFC | J1, J7, J6, J5, J2 | PinHeader_1x04_P2.54mm_Vertical | 5 | PinHeader_1x04_P2.54mm_Vertical
32 | Conn_01x06 | J1 | PinHeader_1x06_P2.54mm_Horizontal | 1 | PinHeader_1x06_P2.54mm_Horizontal
33 | Power | P2, P3, P4, P6, P7, P2, P3, P4, P6, P7, P7, P2, P3, P4 | PinHeader_1x08_P2.54mm_Vertical | 14 | PinHeader_1x08_P2.54mm_Vertical
34 | PWM | P5, P5, P5 | PinHeader_1x10_P2.54mm_Vertical | 3 | PinHeader_1x10_P2.54mm_Vertical
35 | INPUTS | J3 | PinHeader_2x03_P2.54mm_Vertical | 1 | PinHeader_2x03_P2.54mm_Vertical
36 | DATA | J2, J3 | PinHeader_2x04_P2.54mm_Vertical | 2 | PinHeader_2x04_P2.54mm_Vertical
37 | INPUTS | J3 | PinHeader_2x05_P2.54mm_Vertical | 1 | PinHeader_2x05_P2.54mm_Vertical
38 | Digital | P1, P1, P1 | PinHeader_2x18_P2.54mm_Vertical | 3 | PinHeader_2x18_P2.54mm_Vertical
39 | PRESS_DISP | DS2, DS1 | PinSocket_1x04_P2.54mm_Vertical | 2 | PinSocket_1x04_P2.54mm_Vertical
40 | S2_MINI | MC1 | S2_MINI | 1 | S2_MINI
41 | TXS0108EPW | U9, U8 | TSSOP-20_4.4x6.5mm_P0.65mm | 2 | TSSOP-20_4.4x6.5mm_P0.65mm
42 | SDA | TP4, TP3, TP1, TP2 | TestPoint_THTPad_D1.5mm_Drill0.7mm | 4 | TestPoint_THTPad_D1.5mm_Drill0.7mm

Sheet: Top Components
Part Number | Value | Designator | Footprint | Quantity
Arduino_1pin | MH | MK1, MK3, MK4 | Arduino_1pin | 3
Arduino_Mini_Pro_No_Programming_Header | ProMini_NoProgrammingHeader | U1 | Arduino_Mini_Pro_No_Programming_Header | 1
BR10K_Pot_11mm_x_11mm | VOL2 | POT2, POT3, POT1 | BR10K_Pot_11mm_x_11mm | 3
Bourns_3310Y | DMR | RV2, RV1 | Bourns_3310Y | 2
C116539 | MAX487EESA+T | U1, U1, U1, U1, U1, U1 | SOIC-8_3.9x4.9mm_P1.27mm | 6
C130026 | TCA9548APWR | U1 | TSSOP-24_4.4x7.8mm_P0.65mm | 1
C130723 | LED | D1, D10, D11, D12, D13, D14, D15, D16, D17, D18, D19, D2, D20, D21, D22, D23, D24, D3, D4, D5, D6, D7, D8, D9, D1, D10, D11, D12, D13, D14, D17, D18, D19, D2, D20, D21, D22, D23, D24, D25, D26, D27, D28, D29, D3, D30, D31, D32, D4, D5, D6, D7, D8, D9, D1, D10, D11, D12, D13, D14, D15, D16, D17, D18, D19, D2, D20, D21, D22, D23, D24, D25, D26, D27, D28, D29, D3, D30, D31, D32, D33, D34, D35, D36, D4, D5, D6, D7, D8, D9 | LED_0402_1005Metric | 90
C131334 | OUTB GRIP | J5 | JST_PH_B4B-PH-K_1x04_P2.00mm_Vertical | 1
C131337 | MAX DETENT | J10, J8, J9, CAGE1 | JST_PH_B2B-PH-K_1x02_P2.00mm_Vertical | 4
C131339 | IN SERVO | J11, J12, J6, J7, ANT1, CM1, SPDBRK1 | JST_PH_B3B-PH-K_1x03_P2.00mm_Vertical | 7
C131342 | COMS | COM1 | JST_PH_B6B-PH-K_1x06_P2.00mm_Vertical | 1
C13585 | 10uF | C2, C3, C1 | C_1206_3216Metric | 3
C14663 | 0.1uF | C1, C2, C3, C4, C5, C10, C11, C12, C13, C2, C3, C4, C5, C6, C7, C8, C9, C10, C11, C12, C13, C14, C15, C16, C17, C18, C19, C2, C20, C21, C22, C23, C24, C25, C3, C4, C5, C6, C7, C8, C9, C10, C100, C101, C102, C103, C104, C105, C106, C107, C108, C109, C11, C110, C12, C13, C14, C15, C16, C17, C18, C19, C2, C20, C21, C22, C23, C24, C25, C26, C27, C28, C29, C3, C30, C31, C32, C33, C34, C35, C36, C37, C38, C39, C4, C40, C41, C42, C43, C44, C46, C47, C48, C49, C5, C50, C51, C52, C53, C54, C55, C56, C57, C58, C59, C6, C60, C61, C62, C63, C64, C65, C66, C67, C68, C69, C7, C70, C71, C72, C73, C74, C75, C76, C77, C78, C79, C8, C80, C81, C82, C83, C84, C85, C86, C87, C88, C89, C9, C90, C91, C92, C93, C94, C95, C96, C97, C98, C99, C10, C11, C12, C13, C14, C15, C16, C17, C18, C19, C2, C20, C21, C22, C23, C24, C25, C26, C27, C28, C29, C3, C30, C31, C32, C33, C34, C35, C36, C37, C38, C39, C4, C40, C41, C42, C43, C44, C45, C46, C47, C48, C49, C5, C50, C51, C52, C53, C54, C55, C56, C57, C58, C59, C6, C60, C61, C62, C7, C8, C9, C10, C11, C12, C13, C14, C15, C16, C17, C18, C19, C2, C20, C21, C22, C23, C24, C25, C3, C4, C5, C6, C7, C8, C9, C10, C11, C12, C13, C14, C15, C16, C17, C18, C19, C2, C20, C21, C3, C4, C5, C6, C7, C8, C9, C10, C11, C12, C13, C14, C15, C16, C17, C2, C3, C4, C5, C6, C7, C8, C9, C3, C4, C5, C6, C7, C10, C11, C12, C13, C14, C15, C16, C2, C3, C4, C5, C6, C7, C8, C9, C1, C2, C3, C4, C5, C6, C7, C8, C9, C11, C12, C13, C14, C15, C2, C3, C4, C5, C6, C7, C8, C9, C10, C11, C12, C13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 | C_0603_1608Metric | 553
C157923 | TM GRIP | J4 | JST_PH_S5B-PH-K_1x05_P2.00mm_Horizontal | 1
C157993 | INB GRIP | J4, J2/OUTPUT | JST_PH_B5B-PH-K_1x05_P2.00mm_Vertical | 2
C17437 | 120 | R1, R1, R2 | R_0805_2012Metric_Pad1.15x1.40mm_HandSolder | 3
C2286 | Overtemp | D3 | LED_0603_1608Metric_Pad1.05x0.95mm_HandSolder | 1
C23138 | R | R1, R1, R1, R1 | R_0603_1608Metric | 4
C23162 | 4.7K | R2, R11, R12, R13, R14, R15, R19, R20, R21, R22, R23, R24, R25, R26, R27, R28, R29, R30, R31, R32, R33, R34, R35, R4, R42, R5, R6, R7, R8 | R_0603_1608Metric_Pad1.05x0.95mm_HandSolder | 29
C23179 | 2.2K | R1, R3, R1, R1, R1, R1, R1, R1, R1, R1, R1, R1, R1, R1, R1, R1, R1, R1, R1, R1, R1, R1, R1, R1, R1, R1, R1, R1 | R_0603_1608Metric_Pad1.05x0.95mm_HandSolder | 28
C234186 | 5V Accessory 1 | J12, J13, J14, J15, J16, J17, J18, J19, J20, J21, J22, J23, J24 | Molex_Mini-Fit_Jr_5566-02A_2x01_P4.20mm_Vertical | 13
C248788 | ESD5Z5V0 | D1 | D_SOD-523 | 1
C25082 | 150 | R11, R15, R16, R5, R7, R9, R10, R16, R17, R19, R20, R4, R6, R8 | R_0402_1005Metric | 14
C25099 | 270 | R14, R11, R15, R18, R21, R5, R7, R9 | R_0402_1005Metric | 8
C25105 | 33 | R10, R12, R13, R17, R18, R4, R6, R8, R2, R12, R13, R14, R16, R17, R18 | R_0402_1005Metric | 15
C25804 | 10K | R1, R2, R3, R4, R5, R6, R1, R2, R3, R1, R2, R3, R4, R5, R6, R7, R1, R1, R10, R11, R12, R13, R14, R15, R16, R17, R18, R2, R3, R4, R5, R6, R7, R8, R9, R1, R2, R3, R1, R2, R3, R1 | R_0603_1608Metric_Pad0.98x0.95mm_HandSolder | 42
C2593 | IRLML6402TRPBF | Q2, Q3, Q2, Q1, Q2, Q11, Q12, Q2, Q4, Q7, Q8 | SOT-23 | 11
C2642 | IRFB3206PBF | Q1, Q1, Q10, Q3, Q5, Q6, Q9 | TO-220-3_Vertical | 7
C265105 | X/ROLL | J1, J2, J3, J1, J2, J3 | JST_PH_S6B-PH-K_1x06_P2.00mm_Horizontal | 6
C27592 | 68 | R43, R44 | R_0603_1608Metric | 2
C2761795 | WS2812B | D1, D10, D11, D12, D13, D2, D3, D4, D5, D6, D7, D8, D9, D1, D10, D11, D12, D13, D14, D15, D16, D17, D18, D19, D2, D20, D3, D4, D5, D6, D7, D8, D9, D10, D11, D12, D13, D14, D2, D3, D4, D5, D6, D7, D8, D9, D1, D10, D11, D12, D13, D14, D15, D16, D17, D18, D19, D2, D20, D21, D22, D23, D24, D3, D4, D5, D6, D7, D8, D9, D1, D10, D100, D101, D102, D103, D104, D105, D106, D107, D108, D109, D11, D12, D13, D14, D15, D16, D17, D18, D19, D2, D20, D21, D22, D23, D24, D25, D26, D27, D28, D29, D3, D30, D31, D32, D33, D34, D35, D36, D37, D38, D39, D4, D40, D41, D42, D43, D44, D45, D46, D47, D48, D49, D5, D50, D51, D52, D53, D54, D55, D56, D57, D58, D59, D6, D60, D61, D62, D63, D64, D65, D66, D67, D68, D69, D7, D70, D71, D72, D73, D74, D75, D76, D77, D78, D79, D8, D80, D81, D82, D83, D84, D85, D86, D87, D88, D89, D9, D90, D91, D92, D93, D94, D95, D96, D97, D98, D99, D10, D11, D12, D13, D14, D15, D16, D17, D18, D19, D2, D20, D21, D22, D23, D24, D25, D26, D27, D28, D29, D3, D30, D31, D32, D33, D34, D35, D36, D37, D38, D39, D4, D40, D41, D42, D43, D44, D45, D46, D47, D48, D49, D5, D50, D51, D52, D53, D54, D55, D56, D57, D58, D59, D6, D60, D61, D62, D63, D64, D65, D66, D67, D68, D69, D7, D70, D71, D72, D73, D74, D75, D8, D9, D10, D11, D12, D13, D14, D15, D16, D17, D18, D19, D2, D20, D21, D22, D23, D24, D25, D26, D27, D28, D29, D3, D30, D31, D32, D33, D34, D35, D36, D37, D38, D39, D4, D40, D41, D42, D43, D44, D45, D46, D47, D48, D49, D5, D50, D51, D52, D53, D54, D55, D56, D57, D58, D59, D6, D60, 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 | LED_WS2812B_PLCC4_5.0x5.0mm_P3.2mm | 1075
C293502 | BL #9 | J10, J11, J2, J3, J4, J5, J6, J7, J8, J9 | Molex_Mini-Fit_Jr_5566-04A_2x02_P4.20mm_Vertical | 10
C29823 | 4.7uF | C1 | C_1206_3216Metric | 1
C318884 | RESET | SW1, SW1 | SMD-SW-4_5.1x5.1 | 2
C471416 | BRT/CRS | J4, J5, J8 | Molex_KK-254_AE-6410-03A_1x03_P2.54mm_Vertical | 3
C477924 | TCA9554PWR | U1, U2, U3, U4, U2, U1, U2, U3, U4 | TSSOP-16_4.4x5mm_P0.65mm | 9
C49678 | 0.1uF | C1, C1, C1, C1, C1, C1 | C_0805_2012Metric | 6
C504991 | Conn_01x04_Female | J12, J13, J6, J7 | Molex_KK-254_AE-6410-04A_1x04_P2.54mm_Vertical | 4
C504992 | DDI/AMPCD MAIN | J3 | Molex_KK-254_AE-6410-06A_1x06_P2.54mm_Vertical | 1
C505177 | BUS IN | J1, J2, J25, J26, J2, J1, J2, J1, J2 | Molex_Mini-Fit_Jr_5566-06A2_2x03_P4.20mm_Vertical | 9
C527089 | WS2812B-Mini | D1, D10, D11, D12, D13, D14, D15, D16, D17, D18, D19, D2, D20, D21, D22, D3, D4, D5, D6, D7, D8, D9, D25, D29, D30, D32, D33, D34, D35, D36, D37, D39, D40, D44, D45, D49, D51, D53 | LED_WS2812B-MINI_PLCC4_3.5x3.5mm_P1.75mm | 38
C585785 | Conn_01x05_Female | J14 | Molex_KK-254_AE-6410-05A_1x05_P2.54mm_Vertical | 1
C587470 | MEGA BUS 7 | J10, J11, J4, J5, J6, J7, J8, J9, J1 | Molex_Mini-Fit_Jr_5566-08A2_2x04_P4.20mm_Vertical | 9
C587474 | ABSIS BACKLIGHT | J3, J1 | Molex_Mini-Fit_Jr_5566-10A2_2x05_P4.20mm_Vertical | 2
C587483 | ATX-24 | J2 | Molex_Mini-Fit_Jr_5566-24A2_2x12_P4.20mm_Vertical | 1
C66690 | LED/ZERO | J2, J3 | PinHeader_2x02_P2.54mm_Vertical | 2
C72043 | 5V | D1, D2 | LED_0603_1608Metric_Pad1.05x0.95mm_HandSolder | 2
C72120 | ProMicro_5V/16Hz | XU1, U0, XU1, U0, U1, U1 | DIP-24_W15.24mm_Socket | 6
C7963 | LM75C | U1 | SOIC-8_3.9x4.9mm_P1.27mm | 1
C8545 | 2N7002 | Q3 | SOT-23 | 1
C879563 | MT6825GT | U1 | TSSOP-16_4.4x5mm_P0.65mm | 1
C96123 | 47uF | C1, C2, C3, C4, C1, C1, C2, C3, C4, C1 | C_1206_3216Metric | 10
C965555 | LED | D76, D77, D78, D79, D28, D29, D30, D31, D32, D4, D5, D6, D10, D11, D12, D13, D14, D15, D16, D17, D18, D19, D2, D20, D21, D22, D23, D24, D25, D26, D27, D28, D29, D3, D30, D31, D4, D5, D6, D7, D8, D9, D10, D11, D12, D13, D14, D15, D16, D17, D18, D19, D2, D20, D21, D22, D23, D24, D25, D26, D27, D28, D29, D3, D30, D31, D4, D5, D6, D7, D8, D9, D1, D10, D11, D12, D13, D14, D15, D16, D17, D18, D19, D2, D20, D21, D22, D23, D24, D25, D26, D27, D28, D29, D3, D30, D31, D32, D33, D34, D35, D36, D37, D38, D39, D4, D40, D41, D42, D5, D6, D7, D8, D9, D1, D10, D11, D12, D13, D14, D15, D16, D17, D18, D19, D2, D20, D21, D22, D23, D24, D25, D26, D27, D28, D29, D3, D30, D31, D32, D33, D34, D35, D36, D37, D38, D39, D4, D5, D6, D7, D8, D9, D10, D11, D12, D13, D14, D15, D16, D17, D18, D19, D2, D20, D21, D22, D23, D24, D25, D26, D27, D28, D29, D3, D30, D31, D32, D33, D4, D5, D6, D7, D8, D9, D10, D11, D12, D13, D14, D15, D16, D17, D18, D19, D2, D20, D21, D22, D23, D24, D25, D26, D27, D28, D29, D3, D30, D31, D32, D33, D34, D4, D5, D6, D7, D8, D9 | WS2812-2020 | 218
C98733 | EXTERNAL 5V IN | J28, J30 | AMASS_XT60-M_1x02_P7.20mm_Vertical | 2
C98734 | BUTTKICKER AMP | J29 | AMASS_XT60-F_1x02_P7.20mm_Vertical | 1
LED_D3.0mm | Green LED | D5, D2, D1, D3, D4 | LED_D3.0mm | 5
Molex_Mini-Fit_Jr_5569-06A1_2x03_P4.20mm_Horizontal | BUS OUT | J2, J1 | Molex_Mini-Fit_Jr_5569-06A1_2x03_P4.20mm_Horizontal | 2
OPB61x | OPB615 | U1 | OPB61x | 1
PinHeader_1x02_P2.54mm_Vertical | BUS ENABLE | JP1, J16, J14, J13, J10 | PinHeader_1x02_P2.54mm_Vertical | 5
PinHeader_1x03_P2.54mm_Horizontal | Conn_01x03_Male | J1 | PinHeader_1x03_P2.54mm_Horizontal | 1
PinHeader_1x03_P2.54mm_Vertical | Fan voltage selector | J16, J17, J15, J8, J2 | PinHeader_1x03_P2.54mm_Vertical | 5
PinHeader_1x04_P2.54mm_Vertical | I/O | J1 | PinHeader_1x04_P2.54mm_Vertical | 1
PinHeader_1x05_P2.54mm_Vertical | SARI_CAGE | J9 | PinHeader_1x05_P2.54mm_Vertical | 1
PinHeader_2x01_P2.54mm_Vertical | PWR | J1 | PinHeader_2x01_P2.54mm_Vertical | 1
PinHeader_2x02_P2.54mm_Vertical | ACC PWR | J7 | PinHeader_2x02_P2.54mm_Vertical | 1
PinHeader_2x05_P2.54mm_Vertical | STEPPER | J5, J7, J5 | PinHeader_2x05_P2.54mm_Vertical | 3
PinHeader_2x07_P2.54mm_Vertical | ALTIMETER | J6, J5, J1 | PinHeader_2x07_P2.54mm_Vertical | 3
PinHeader_2x10_P2.54mm_Vertical | DIGITAL #2 | J5, J6, J4 | PinHeader_2x10_P2.54mm_Vertical | 3
PinHeader_2x11_P2.54mm_Vertical | DIGITAL #1 | J3 | PinHeader_2x11_P2.54mm_Vertical | 1
PinSocket_1x06_P2.54mm_Vertical | GND | J2 | PinSocket_1x06_P2.54mm_Vertical | 1
PinSocket_2x16_P2.54mm_Vertical | THRU | J1 | PinSocket_2x16_P2.54mm_Vertical | 1
R_Axial_DIN0204_L3.6mm_D1.6mm_P5.08mm_Horizontal | 220 | R1 | R_Axial_DIN0204_L3.6mm_D1.6mm_P5.08mm_Horizontal | 1
R_Axial_DIN0207_L6.3mm_D2.5mm_P7.62mm_Horizontal | 150 | R1, R4, R5, R3, R2 | R_Axial_DIN0207_L6.3mm_D2.5mm_P7.62mm_Horizontal | 5
SCRATCHPADBACKLIGHT | UFCScratchPadBacklight | BL1 | SCRATCHPADBACKLIGHT | 1
SCRATCHPADLCD | UFCScratchpadLCD | DS1 | SCRATCHPADLCD | 1
SW_TH_Tactile_Omron_B3F-10xx | ECM JETT | SW1, SW1, SW2, SW3, SW2, SW1, SW2, SW1, SW6, SW5, SW4, SW3, SW2, SW1, SW5, SW4, SW3, SW2, SW1, SW5, SW4, SW3, SW2, SW1 | SW_TH_Tactile_Omron_B3F-10xx | 24
SolderJumper-2_P1.3mm_Open_RoundedPad1.0x1.5mm | RST | RST1 | SolderJumper-2_P1.3mm_Open_RoundedPad1.0x1.5mm | 1
TL1240GQ | TL1240GQ | SW1, SW2, SW3, SW4, SW5, SW6, SW7, SW8, SW9, SW10, SW11, SW12, SW13, SW14, SW16, SW17, SW18, SW19, SW20, SW21, SW22, SW23, SW24, SW25, SW26, SW27, SW28, SW15, SW1, SW2, SW3, SW4, SW5, SW6, SW7, SW8, SW9, SW10, SW11, SW12, SW13, SW14, SW15, SW16, SW17, SW18, SW19, SW20, SW1, SW2, SW3, SW4, SW5, SW6, SW7, SW1, SW2, SW3, SW4, SW5, SW6, SW7, SW8, SW9, SW10, SW11, SW12, SW13, SW14, SW15, SW16, SW17, SW18, SW19 | TL1240GQ | 74
UFCOptionDigit | UFCOptionDigit | DS6, DS5, DS4, DS3, DS2 | UFCOptionDigit | 5
UFCSingleDigit | UFCSingleDigit | DS8, DS7 | UFCSingleDigit | 2
VID29-02 | VID29-02 | M1, M1 | VID29-02 | 2
x40_8798 | X40_8798 | M1 | x40_8798 | 1
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

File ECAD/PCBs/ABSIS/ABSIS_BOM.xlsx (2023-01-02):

ABSIS ALE
REF | VALUE | Footprint | Datasheet | LCSC/JLCPCB | PN | QTY/PCB | Source | Price/EA | Price/EXT/PCB | # OF PCBS | QTY/Ext | Price/Ext
J1, J2 | BUS IN, BUS OUT | Connector_Molex:Molex_Mini-Fit_Jr_5566-06A2_2x03_P4.20mm_Vertical | https://www.molex.com/pdm_docs/sd/039299067_sd.pdf | N/A | 39299067 | 2 | https://www.digikey.com/en/products/detail/0039299067/900-0039299067-ND/2002683 | 1.27 | 2.54 | 20 | 40 | 50.8
J3, J4 | I/O #1, I/O #2 | Connector_PinHeader_2.54mm:PinHeader_2x06_P2.54mm_Vertical | https://datasheet.lcsc.com/lcsc/1810241611_Ckmtw-Shenzhen-Cankemeng-B-2100S12P-B110_C124388.pdf | C124388 | PH2-224/100-121 | 2 |  |  |  |  | 40 | 0
J5 | GND | Connector_PinHeader_2.54mm:PinHeader_1x06_P2.54mm_Vertical | https://datasheet.lcsc.com/lcsc/1810312320_BOOMELE-Boom-Precision-Elec-C37208_C37208.pdf | C37208 | C37208 | 1 |  |  |  |  | 20 | 0
J6 | ACC PWR | Connector_PinHeader_2.54mm:PinHeader_2x02_P2.54mm_Vertical | https://jlcpcb.com/partdetail/boomele_boom_Precision_elec-C66690/C66690 | C66690 | C66690 | 1 |  |  |  |  | 20 | 0
XU1 | ProMicro_5V/16Hz | Package_DIP:DIP-24_W15.24mm_Socket | https://datasheet.lcsc.com/lcsc/1810271810_CONNFLY-Elec-DS1009-24AT1WX-0A2_C72120.pdf | C72120 | ICS-624-T | 1 | https://www.digikey.com/en/products/detail/adam-tech/ICS-624-T/9832867 | 0.27 | 0.27 |  | 20 | 5.4
ABSIS ALE RELAY MODULE
REF | VALUE | Footprint | Datasheet | LCSC/JLCPCB | PN | QTY | Source | Price/EA | Price/EXT/PCB | # OF PCBS |  | Price/Ext
J1 | THRU | Connector_PinSocket_2.54mm:PinSocket_2x16_P2.54mm_Vertical | https://www.mouser.com/datasheet/2/527/ssq_th-1370157.pdf | N/A | SSQ-116-03-T-D | 1 | https://www.digikey.com/en/products/detail/samtec-inc/SSQ-116-03-T-D/1111844 | 3.16 | 3.16 | 20 | 20 | 63.2
J2 | GND | Connector_PinSocket_2.54mm:PinSocket_1x06_P2.54mm_Vertical | https://www.mouser.com/datasheet/2/527/ssq_th-1370157.pdf | N/A | SSQ-106-03-L-S | 1 |  |  | 0 |  | 20 | 0
J3, J4 | ... | Connector_JST:JST_PH_B2B-PH-K_1x02_P2.00mm_Vertical | https://www.jst-mfg.com/product/pdf/eng/ePH.pdf | N/A | B2B-PH-K-S(LF)(SN) | 2 |  |  | 0 |  | 40 | 0
JP1, JP2, JP4, JP5 | ... | Connector_PinHeader_2.54mm:PinHeader_1x03_P2.54mm_Vertical | https://app.adam-tech.com/products/download/data_sheet/201605/ph1-xx-ua-data-sheet.pdf | N/A | PH1-03-UA | 4 |  |  | 0 |  | 80 | 0
Q1, Q4 | IRFB3206PBF | Package_TO_SOT_THT:TO-220-3_Vertical | https://datasheet.lcsc.com/szlcsc/1806111728_Infineon-Technologies-IRFB3206PBF_C2642.pdf | C2642 | IRFB3206PBF | 2 |  |  | 0 |  | 40 | 0

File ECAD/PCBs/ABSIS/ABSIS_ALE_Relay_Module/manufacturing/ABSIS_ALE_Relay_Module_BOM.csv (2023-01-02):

Comment | Designator | Footprint | LCSC
MH | H1,H2,H3,H4 | MountingHole:MountingHole_3.2mm_M3_DIN965
THRU | J1 | Connector_PinSocket_2.54mm:PinSocket_2x16_P2.54mm_Vertical
GND | J2 | Connector_PinSocket_2.54mm:PinSocket_1x06_P2.54mm_Vertical
CH1 OUT | J3 | Connector_JST:JST_PH_B2B-PH-K_1x02_P2.00mm_Vertical
CH2 OUT | J4 | Connector_JST:JST_PH_B2B-PH-K_1x02_P2.00mm_Vertical
CH1 PWR SEL | JP1 | Connector_PinHeader_2.54mm:PinHeader_1x03_P2.54mm_Vertical
CH1 SEL A | JP2 | Connector_PinHeader_2.54mm:PinHeader_1x03_P2.54mm_Vertical
CH2 PWR SEL | JP4 | Connector_PinHeader_2.54mm:PinHeader_1x03_P2.54mm_Vertical
CH2 SEL A | JP5 | Connector_PinHeader_2.54mm:PinHeader_1x03_P2.54mm_Vertical
OpenHornetLogoSmall | LOGO1 | KiCAD Libraries:OH_LOGO_ONLY_11x6mm
IRLML6402TRPBF | Q2,Q3 | Package_TO_SOT_SMD:SOT-23 | C2593
IRFB3206PBF | Q1,Q4 | Package_TO_SOT_THT:TO-220-3_Vertical | C2642
10K | R1,R2,R3,R4,R5,R6 | Resistor_SMD:R_0603_1608Metric_Pad0.98x0.95mm_HandSolder | C25804

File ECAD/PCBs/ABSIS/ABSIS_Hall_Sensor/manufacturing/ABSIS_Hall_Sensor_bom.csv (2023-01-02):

Comment | Designator | Footprint | LCSC
0.1uF | C1 | Capacitor_SMD:C_0603_1608Metric | C14663
ESD5Z5V0 | D1 | Diode_SMD:D_SOD-523 | C248788
MountingHole | H1,H2,H3,H4 | MountingHole:MountingHole_2.5mm
IN | J1 | Connector_JST:JST_PH_S6B-PH-K_1x06_P2.00mm_Horizontal | C265105
MT6825GT | U1 | Package_SO:TSSOP-16_4.4x5mm_P0.65mm | C879563

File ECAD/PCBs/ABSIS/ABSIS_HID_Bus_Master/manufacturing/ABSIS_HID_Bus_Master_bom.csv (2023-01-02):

Comment | Designator | Footprint | LCSC
0.1uF | C1 | Capacitor_SMD:C_0805_2012Metric_Pad1.15x1.40mm_HandSolder | C49678
PWR IN | J1 | Connector_Molex:Molex_Mini-Fit_Jr_5566-08A2_2x04_P4.20mm_Vertical
BUS #1 | J2 | Connector_Molex:Molex_Mini-Fit_Jr_5566-06A2_2x03_P4.20mm_Vertical
OpenHornetLogoSmall | LOGO1 | KiCAD Libraries:OH_LOGO_37.7mm_5.9mm
OpenHornetLogoSmall | LOGO3 | KiCAD Libraries:CC-BY-NC-SA-Small
OpenHornetLogoSmall | LOGO4 | KiCAD Libraries:OH_LOGO_LARGE
MH | MK1,MK3,MK4,MK6 | Socket_Arduino_Mega:Arduino_1pin
120 | R1 | Resistor_SMD:R_0805_2012Metric_Pad1.15x1.40mm_HandSolder | C17437
TP-12 | TP1 | TestPoint:TestPoint_THTPad_D1.5mm_Drill0.7mm
TP-5V | TP2 | TestPoint:TestPoint_THTPad_D1.5mm_Drill0.7mm
TP-3.3V | TP3 | TestPoint:TestPoint_THTPad_D1.5mm_Drill0.7mm
TP-GND | TP4 | TestPoint:TestPoint_THTPad_D1.5mm_Drill0.7mm
TP-B1B | TP5 | TestPoint:TestPoint_THTPad_D1.5mm_Drill0.7mm
TP-B1A | TP6 | TestPoint:TestPoint_THTPad_D1.5mm_Drill0.7mm
ProMicro | U0 | Package_DIP:DIP-24_W15.24mm_Socket | C72120
MAX487EESA+T | U1 | Package_SO:SOIC-8_3.9x4.9mm_P1.27mm | C116539

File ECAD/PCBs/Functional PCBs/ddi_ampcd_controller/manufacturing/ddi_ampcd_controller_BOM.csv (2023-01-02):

Comment | Designator | Footprint | LCSC
0.1uF | C1 | Capacitor_SMD:C_0805_2012Metric | C49678
MountingHole | H1,H2,H3,H4 | MountingHole:MountingHole_3.2mm_M3
BUS IN | J1 | Connector_Molex:Molex_Mini-Fit_Jr_5566-06A2_2x03_P4.20mm_Vertical | N/A
BUS OUT | J2 | Connector_Molex:Molex_Mini-Fit_Jr_5566-06A2_2x03_P4.20mm_Vertical | N/A
Conn_01x06 | J3 | Connector_Molex:Molex_KK-254_AE-6410-06A_1x06_P2.54mm_Vertical
BRT/CRS | J4 | Connector_Molex:Molex_KK-254_AE-6410-03A_1x03_P2.54mm_Vertical
CONT/HDG | J5 | Connector_Molex:Molex_KK-254_AE-6410-03A_1x03_P2.54mm_Vertical
DDI ROT | J6 | Connector_Molex:Molex_KK-254_AE-6410-04A_1x04_P2.54mm_Vertical
AMPCD ROT | J7 | Connector_Molex:Molex_KK-254_AE-6410-04A_1x04_P2.54mm_Vertical
EWI SW | J8 | Connector_Molex:Molex_KK-254_AE-6410-03A_1x03_P2.54mm_Vertical
OpenHornetLogoSmall | LOGO1,LOGO2 | KiCAD Libraries:OH_LOGO_ONLY_11x6mm | N/A
IRFB3206PBF | Q1 | Package_TO_SOT_THT:TO-220-3_Vertical | C2642
IRLML6402TRPBF | Q2 | Package_TO_SOT_SMD:SOT-23 | C2593
10K | R1,R2,R3,R4,R5,R6,R7 | Resistor_SMD:R_0603_1608Metric_Pad0.98x0.95mm_HandSolder | C25804
RST | RST1 | Jumper:SolderJumper-2_P1.3mm_Open_RoundedPad1.0x1.5mm
MAX487EESA+T | U1 | Package_SO:SOIC-8_3.9x4.9mm_P1.27mm | C116539
ProMicro_5V/16Hz | XU1 | Package_DIP:DIP-24_W15.24mm_Socket | C72120

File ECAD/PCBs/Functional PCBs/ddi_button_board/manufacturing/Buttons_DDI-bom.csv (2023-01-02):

Comment | Designator | Footprint | LCSC
47uF | C1,C2,C3,C4 | Capacitor_SMD:C_1206_3216Metric | C96123
LED | D1,D2,D3,D4,D5,D6,D7,D8,D9,D10,D11,D12,D13,D14,D17,D18,D19,D20,D21,D22,D23,D24,D25,D26,D27,D28,D29,D30,D31,D32 | LED_SMD:LED_0402_1005Metric | C130723
Conn_01x06 | J1 | Connector_Molex:Molex_KK-254_AE-6410-06A_1x06_P2.54mm_Vertical
MH | MK1,MK2,MK3,MK4 | MountingHole:MountingHole_4.3mm_M4
10K | R1,R2,R3 | Resistor_SMD:R_0603_1608Metric | C25804
33 | R12,R13,R14 | Resistor_SMD:R_0402_1005Metric | C25105
150 | R4,R6,R8,R10,R16,R17,R19,R20 | Resistor_SMD:R_0402_1005Metric | C25082
270 | R5,R7,R9,R11,R15,R18,R21 | Resistor_SMD:R_0402_1005Metric | C25099
TL1240GQ | SW1,SW2,SW3,SW4,SW5,SW6,SW7,SW8,SW9,SW10,SW11,SW12,SW13,SW14,SW15,SW16,SW17,SW18,SW19,SW20 | KiCAD Libraries:TL1240GQ
TCA9554PWR | U1,U2,U3,U4 | Package_SO:TSSOP-16_4.4x5mm_P0.65mm | C477924

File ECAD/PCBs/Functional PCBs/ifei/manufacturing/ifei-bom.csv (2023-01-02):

Comment | Designator | Footprint | LCSC
LED | D1,D2,D3,D4,D5,D6,D7,D8,D9,D10,D11,D12,D13,D14,D15,D16,D17,D18,D19,D20,D21,D22,D23,D24,D25,D26,D27,D28,D29,D30,D31,D32,D33,D34,D35,D36,D37,D38,D39 | KiCAD Libraries:WS2812-2020 | C965555
MountingHole | H1,H2,H3,H4 | MountingHole:MountingHole_4.5mm
MountingHole | H5,H6,H7,H8 | MountingHole:MountingHole_2.2mm_M2_DIN965
BL IN | J1 | Connector_Molex:Molex_Mini-Fit_Jr_5566-04A_2x02_P4.20mm_Vertical
BL OUT | J2 | Connector_Molex:Molex_Mini-Fit_Jr_5566-04A_2x02_P4.20mm_Vertical
INPUTS | J3 | Connector_PinHeader_2.54mm:PinHeader_2x04_P2.54mm_Vertical
OpenHornetLogoSmall | LOGO1 | KiCAD Libraries:OH_LOGO_ONLY_11x6mm
MODE | SW1 | Button_Switch_THT:SW_TH_Tactile_Omron_B3F-10xx
QTY | SW2 | Button_Switch_THT:SW_TH_Tactile_Omron_B3F-10xx
UP | SW3 | Button_Switch_THT:SW_TH_Tactile_Omron_B3F-10xx
DOWN | SW4 | Button_Switch_THT:SW_TH_Tactile_Omron_B3F-10xx
ZONE | SW5 | Button_Switch_THT:SW_TH_Tactile_Omron_B3F-10xx
ET | SW6 | Button_Switch_THT:SW_TH_Tactile_Omron_B3F-10xx

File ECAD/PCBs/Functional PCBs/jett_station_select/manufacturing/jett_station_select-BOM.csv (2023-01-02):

Comment | Designator | Footprint | LCSC
1000 nF | C1 | Capacitor_SMD:CP_Elec_8x10
READY | D1 | LED_THT:LED_D3.0mm
LED | D2,D3,D4,D5,D6,D7,D8,D9,D10,D11,D12,D13,D14,D15,D16,D17,D18,D19,D20,D21,D22,D23,D24,D25,D26,D27,D28,D29,D30,D31,D32,D33 | KiCAD Libraries:WS2812-2020 | C965555
MountingHole | H1,H2,H3 | MountingHole:MountingHole_2.5mm
BL IN | J1 | Connector_Molex:Molex_Mini-Fit_Jr_5566-04A_2x02_P4.20mm_Vertical
BL OUT | J2 | Connector_Molex:Molex_Mini-Fit_Jr_5566-04A_2x02_P4.20mm_Vertical
INPUTS | J3 | Connector_PinHeader_2.54mm:PinHeader_2x03_P2.54mm_Vertical
OpenHornetLogoSmall | LOGO1 | KiCAD Libraries:OH_LOGO_ONLY_11x6mm
R | R1 | Resistor_SMD:R_0603_1608Metric | C23138
CTR | SW1 | Button_Switch_THT:SW_TH_Tactile_Omron_B3F-10xx
LI | SW2 | Button_Switch_THT:SW_TH_Tactile_Omron_B3F-10xx
RI | SW3 | Button_Switch_THT:SW_TH_Tactile_Omron_B3F-10xx
LO | SW4 | Button_Switch_THT:SW_TH_Tactile_Omron_B3F-10xx
RO | SW5 | Button_Switch_THT:SW_TH_Tactile_Omron_B3F-10xx

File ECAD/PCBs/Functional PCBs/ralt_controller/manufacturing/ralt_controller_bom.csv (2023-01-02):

Comment | Designator | Footprint | LCSC
0.1uF | C1 | Capacitor_SMD:C_0805_2012Metric | C49678
BUS IN | J1 | Connector_Molex:Molex_Mini-Fit_Jr_5566-06A2_2x03_P4.20mm_Vertical
GRN_LED | J13 | Connector_PinHeader_2.54mm:PinHeader_1x02_P2.54mm_Vertical
RED_LED | J14 | Connector_PinHeader_2.54mm:PinHeader_1x02_P2.54mm_Vertical
OFF_SERVO | J15 | Connector_PinHeader_2.54mm:PinHeader_1x03_P2.54mm_Vertical
PUSH | J16 | Connector_PinHeader_2.54mm:PinHeader_1x02_P2.54mm_Vertical
POT | J17 | Connector_PinHeader_2.54mm:PinHeader_1x03_P2.54mm_Vertical
BUS OUT | J2 | Connector_Molex:Molex_Mini-Fit_Jr_5566-06A2_2x03_P4.20mm_Vertical
BL IN | J3 | Connector_Molex:Molex_Mini-Fit_Jr_5566-04A_2x02_P4.20mm_Vertical
BL OUT | J4 | Connector_Molex:Molex_Mini-Fit_Jr_5566-04A_2x02_P4.20mm_Vertical
STEPPER | J5 | Connector_PinHeader_2.54mm:PinHeader_2x05_P2.54mm_Vertical
BL_DIN_SEL | JP1 | Connector_PinHeader_2.54mm:PinHeader_1x03_P2.54mm_Vertical
BL_DOUT_SEL | JP2 | Connector_PinHeader_2.54mm:PinHeader_1x03_P2.54mm_Vertical
MH | MK1,MK2,MK3 | MountingHole:MountingHole_2.5mm
120 | R1,R2 | Resistor_SMD:R_0805_2012Metric | C17437
ProMicro | U0 | Package_DIP:DIP-24_W15.24mm_Socket | C72120
MAX487EESA+T | U1 | Package_SO:SOIC-8_3.9x4.9mm_P1.27mm | C116539

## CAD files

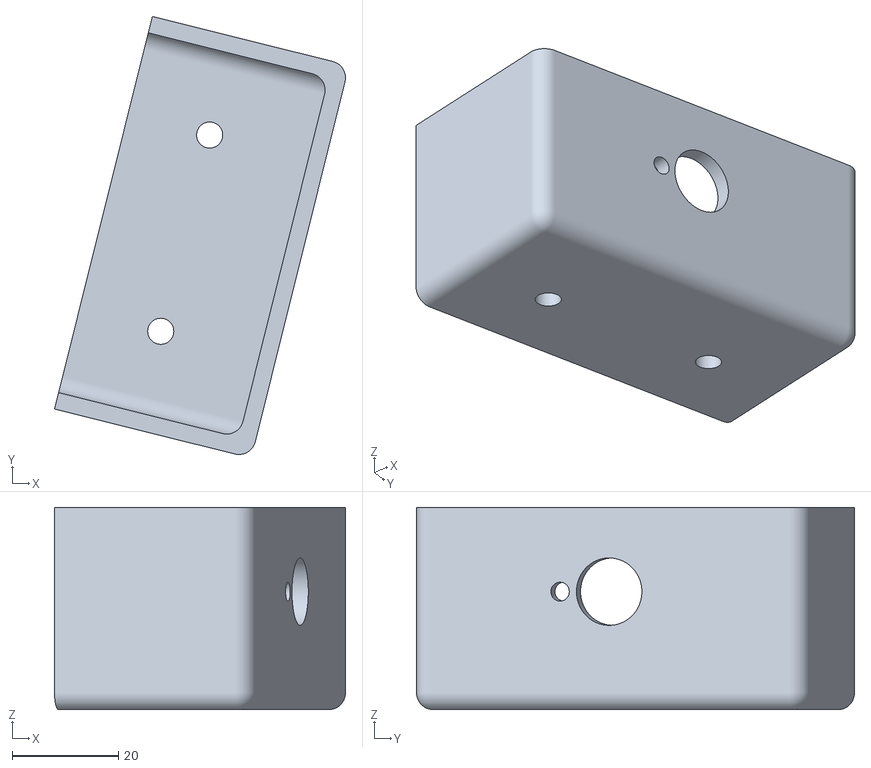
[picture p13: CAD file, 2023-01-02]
MCAD/ASSY, LEFT CONSOLE/OH4A8A3-1 - ASSY, NUC WEAP SWITCH/PETG/OH4A8A3-1 - ASSY, NUC WEAP SWITCH.stl
54.8 x 82.5 x 38.1

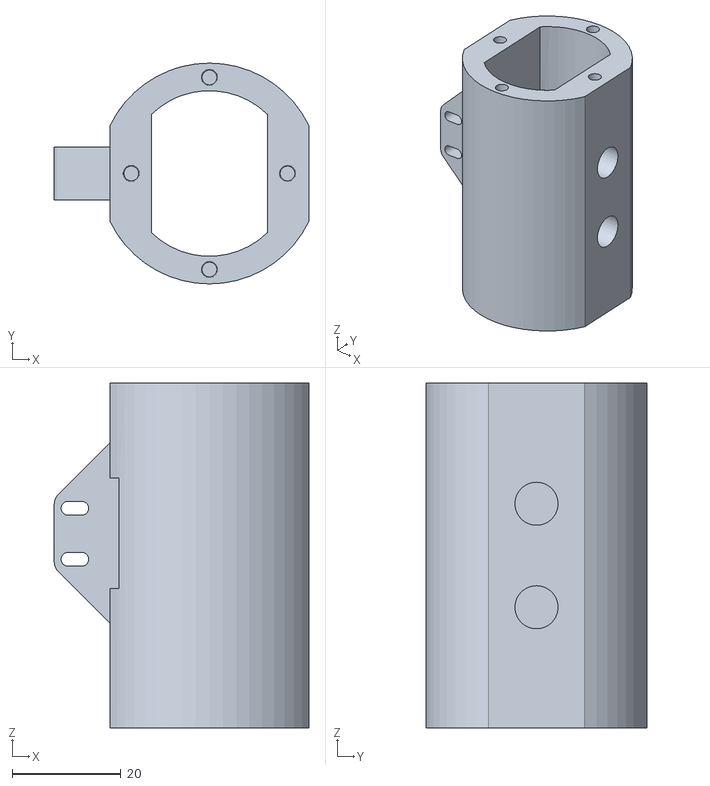
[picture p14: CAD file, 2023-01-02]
MCAD/ASSY, RIGHT CONSOLE/OH5A2A2-1 - ASSY, WING FOLD HANDLE/Wing Fold Mechanism Main Body.STL
46.9 x 40.6 x 63.5

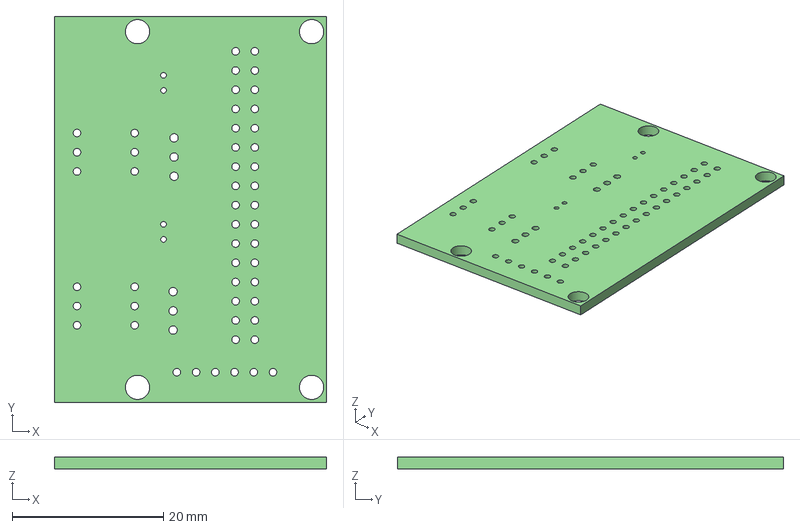
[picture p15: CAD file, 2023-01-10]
ECAD/PCBs/ABSIS/ABSIS_ALE Relay Module/MCAD/ABSIS_ALE Relay Module.step
36.0 x 51.0 x 1.60 mm

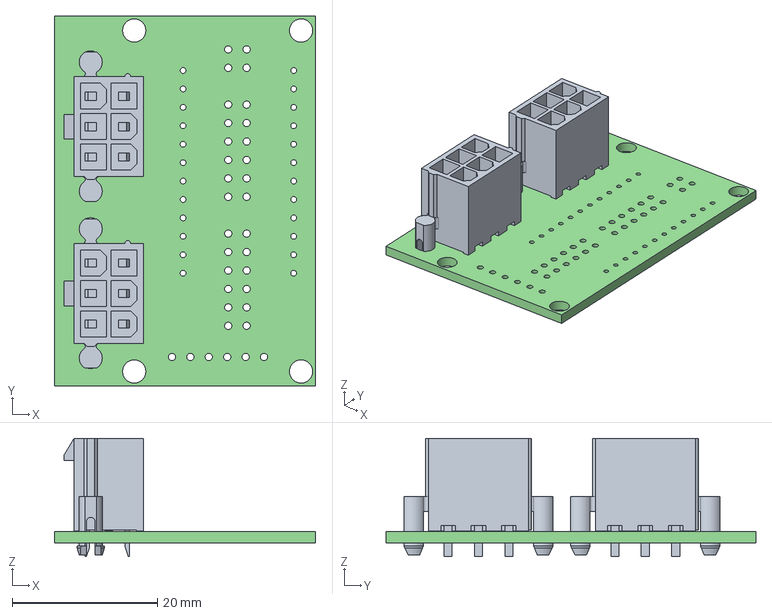
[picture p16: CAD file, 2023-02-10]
ECAD/PCBs/ABSIS/ABSIS_ALE/MCAD/ABSIS_ALE.step
36.0 x 51.0 x 16.3 mm
ABSIS_ALE PCB

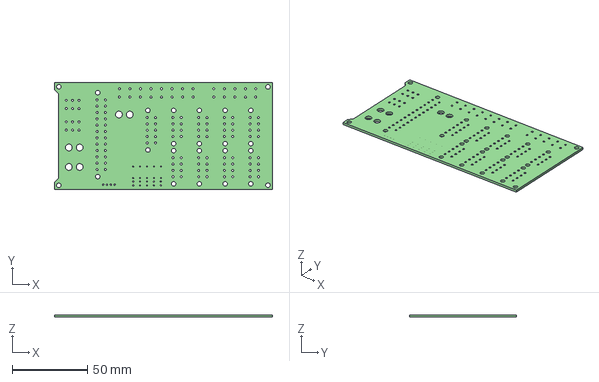
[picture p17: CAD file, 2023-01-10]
ECAD/PCBs/ABSIS/ABSIS_ATX Power Supply Unit/MCAD/ABSIS_ATX Power Supply Unit.step
144.4 x 71.1 x 1.60 mm

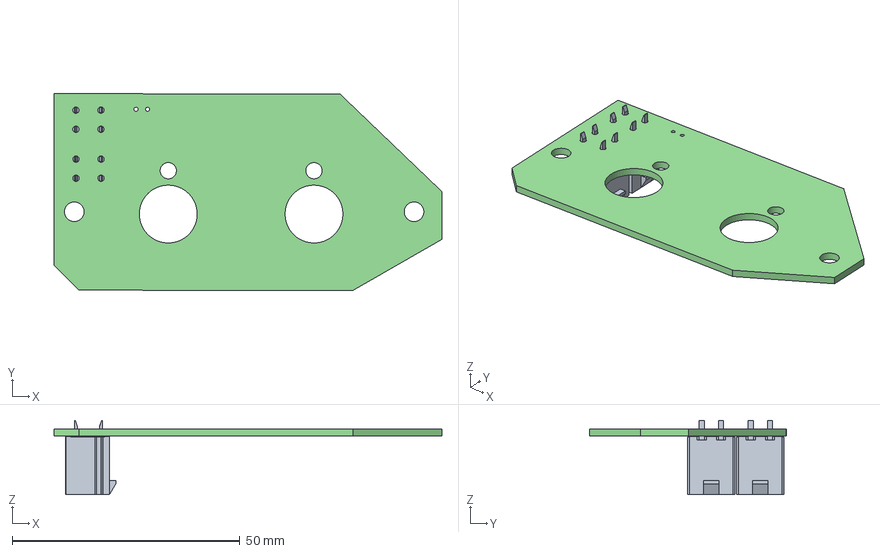
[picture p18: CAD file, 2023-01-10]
ECAD/PCBs/Backlight PCBs/Backlighting_Type A/ANT SEL PANEL/MCAD/ANT SEL PANEL.step
85.2 x 43.2 x 16.3 mm
ANT SEL PANEL PCB

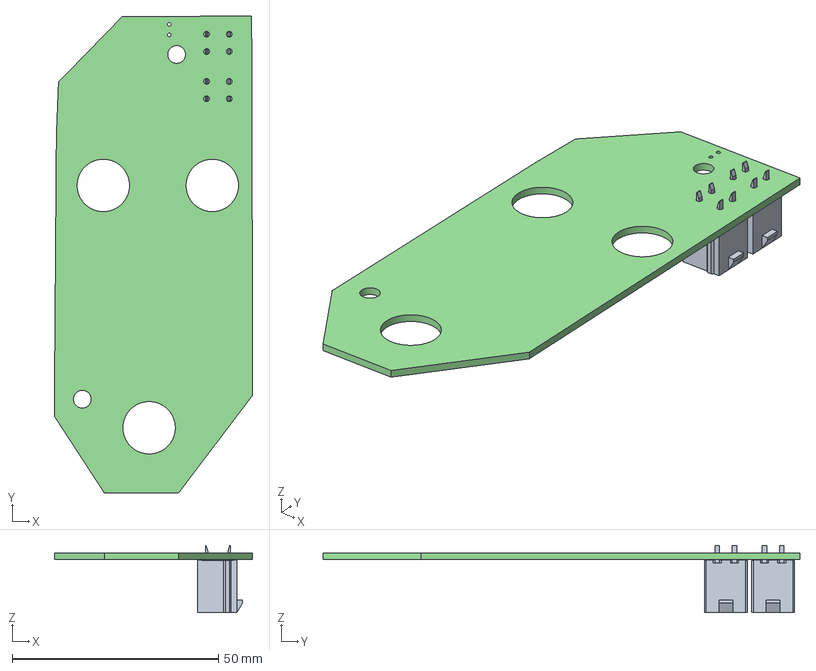
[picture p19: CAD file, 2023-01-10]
ECAD/PCBs/Backlight PCBs/Backlighting_Type A/APU PANEL/MCAD/APU PANEL.step
48.1 x 115.6 x 16.3 mm
APU PANEL PCB

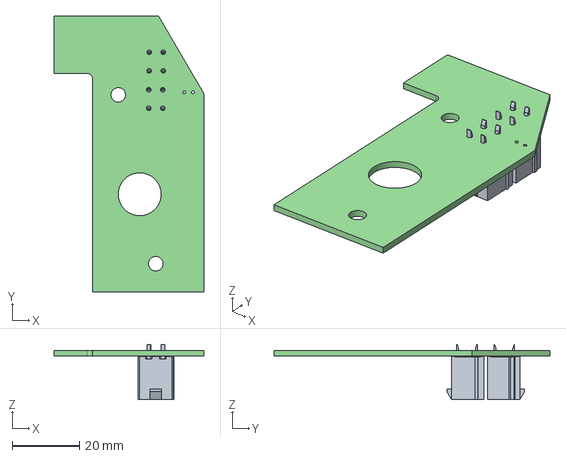
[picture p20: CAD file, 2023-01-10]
ECAD/PCBs/Backlight PCBs/Backlighting_Type A/AV COOL PANEL/MCAD/AV COOL PANEL.step
44.5 x 81.8 x 16.3 mm
AV COOL PANEL PCB

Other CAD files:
MCAD/ADDITIONAL RESOURCES/DuPont_Shell_Full_Custom.scad
ECAD/PCBs/ABSIS/ABSIS_Hall Sensor/MCAD/ABSIS_Hall Sensor.step
ECAD/PCBs/ABSIS/ABSIS_Pit Management System/MCAD/ABSIS_Pit Management System.step
ECAD/PCBs/Backlight PCBs/Backlighting_Type A/APU PANEL/Legacy/APU PANEL.SLDPRT
ECAD/PCBs/Backlight PCBs/Backlighting_Type A/CAUTION LIGHTS PANEL/Legacy/CAUTION_LIGHTS_PANEL_PCB_DEFINITION.SLDDRW
ECAD/PCBs/Backlight PCBs/Backlighting_Type A/CAUTION LIGHTS PANEL/MCAD/CAUTION LIGHTS PANEL.step
ECAD/PCBs/Backlight PCBs/Backlighting_Type A/COMM PANEL/MCAD/COMM PANEL.step
ECAD/PCBs/Backlight PCBs/Backlighting_Type A/DEFOG PANEL/MCAD/DEFOG PANEL.step
ECAD/PCBs/Backlight PCBs/Backlighting_Type A/ECM DISP PANEL/MCAD/ECM DISP PANEL.step
ECAD/PCBs/Backlight PCBs/Backlighting_Type A/ECS PANEL/MCAD/ECS PANEL.step
ECAD/PCBs/Backlight PCBs/Backlighting_Type A/ELEC PANEL/MCAD/ELEC PANEL.step
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

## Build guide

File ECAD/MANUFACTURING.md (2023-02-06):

OH logo
* [OpenHornet Website](https://www.openhornet.com)
* [OpenHornet Discord](https://discord.gg/G5PA5ju)
* [Donate to OpenHornet](https://www.openhornet.com/campaigns/donate/)

# Ordering PCBs from JLCPCB
JLCPCB is a popular online platform for ordering printed circuit boards (PCBs) and has been chosen as the recommended supplier of OpenHornet PCBs. This guide will walk you through the steps to order your own PCBs from JLCPCB.

## Step 1: Sign Up
Before you can start ordering PCBs, you need to create an account on JLCPCB. To do so, go to jlcpcb.com and click on the "Sign Up" button. Fill in your email address and password to create your account.

## Step 2: Upload the PCB Design
On the main page, click on the icon that says "Add gerber file."  OpenHornet has already generated the files you need to upload in order to create your PCBs.  When the browser window opens, navigate to the _\PCB_You_Want\JLCPCB\production_files\_ folder, and look for _**"GERBER - PCB_NAME.zip"**__   For this example, I will be assembling the **COMM PANEL.**



## Step 3: Select PCB Parameters
After uploading your design, you'll be taken to the order page where you can select the parameters for your PCBs. You'll need to select the following parameters:

#### JLCPCB should detect how many layers it needs based on the gerber files you've uploaded.  However, the safest course of action is to double check the "production_files" folder and look for a text document called "IMPORTANT MANUFACTURING INSTRUCTIONS.TXT" which will provide any specific adjustments you need to make to the parameters.  If there isn't one located in the folder, then the standard settings will apply.

### PCB Layer: 
The majority of Openhornet PCB's require only 2 Layers. Reference the note above if there are any questions.

### PCB Dimensions: 
Automatically detected.  If the PCB size doesn't meet the minimum 100x100mm dimensions, you will be asked to allow JLC to make modifications to continue processing.  Click yes.

### PCB Quantity: 
The number of PCBs you want to order.  The minimum is 5.  Most PCBs only require 1, so it's best to find a group buy to split the costs.  However, there are a few PCBs where more than 1 are required.  Make sure you confirm the quantity you need!

### PCB Thickness:
1.6mm

### PCB Color:
Choose whatever color you prefer.  Note: Depending on other PCB attributes (2oz Copper, 4 Layers, etc.) you'll be limited on the color you can choose.

### Confirm Production File:
YES!  It's a few cents more and having the extra check is absolutely worth it.  JLC currently has errors with the way their website analyzes files, so it's highly possible for pieces to be rotated incorrectly.

### The rest of the settings can be default.  See the example before if you have any questions.



## Step 4: Choose Components and Assembly Services (Optional)
If you want JLCPCB to assemble the components onto your PCBs, you can choose from their component and assembly services. You'll need to upload a BOM (Bill of Materials) file and CPL positioning file that tells JLC the exact location that the components need to be placed.  Again, Openhornet provides these documents in the same production_files folder for you to use.

#### It is possible that JLC doesn't have an item in stock.  You have a few options: choose a similar piece that meets the specifications, provide your own components by using the Parts Manager located on their website, or ignore the missing parts and continue production with what they have available.  The majority of OpenHornet PCBs require only TOP level SMD (surface mounted device) Assembly.  The Bottom Level is typically THT (Thru-hole technology) which can be soldered at home.  Due to cost effectiveness and feasibility, it is recommended to assemble layers that have SMD components.

### PCBA Type:
The “Economic” option is the cheapest, but if you assemble both sides, you'll have to choose the “Standard” option.  Some components require Standard to be selected and JLC will prompt you to change if needed.

### Assembly Side: 
Top Side.  9/10 PCBs require Top Level assembly.  If the parts are available and cost is of no concern, you can opt to have both sides assembled.

### Confirm Parts Placement: 
YES!!!!!!! 



## Step 5: Upload BOM and CPL files.
*  1:  Click on the "Add BOM File" and "Add CPL File" icons and upload the required files accordingly.
*  2:  In the drop down box below, select **"Research\Education\DIY\Entertainment ==> Video\TV Game Player HS Code 950450"**



## Step 6:  Selecting Parts
By default, JLC will load the parts selected based on the BOM provided as long as the LCSC Part Numbers are correct.  If for any reason, it doesn't recognize a part number, please contact us.  We've worked diligently to ensure everything is correct, but mistakes happen.  If there is an inventory shortage, you can change the part by clicking on it and searching for similar components.



#### Referencing Step 4:  If this happens, just hit accept if you wish to continue with assembly or choose "Do not place this part." 



## Step 7:  Review and Submit Order

Review your order and if everything looks correct, fill out your financial and shipping information as required.  After making payment, you'll receive an order confirmation email. You can track the status of your order by logging into your JLCPCB account. That's it! You've successfully ordered PCBs from JLCPCB. The process is straightforward and simple, making it easy to get the PCBs you need for your project.

_Note: The details mentioned in this guide are subject to change, kindly check the JLCPCB website for the latest information._

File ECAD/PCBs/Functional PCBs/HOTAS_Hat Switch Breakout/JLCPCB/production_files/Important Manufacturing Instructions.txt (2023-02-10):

1:  This PCB only has one Bottom Layer thru-hole component and will only have a "BOM_BOTTOM-HOTAS_Hat Switch Breakout.csv"

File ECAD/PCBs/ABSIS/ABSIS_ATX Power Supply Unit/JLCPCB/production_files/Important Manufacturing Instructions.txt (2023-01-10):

1:  This is a 4 layer PCB.  Make sure you check and select the approriate settings when having this board manufactured by a 3rd party.
2:  Each layer requires a 2oz Copper Pour.
3:  This PCB only has Top Layer components and will only have a "BOM_TOP-ABSIS_ATX Power Supply Unit.csv"

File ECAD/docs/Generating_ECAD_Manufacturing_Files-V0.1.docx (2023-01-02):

# Generating ECAD Manufacturing Files

# Requirements:

KiCAD 5.1.0 or above

# Prerequisite:

Make sure that the PCB you intend to create manufacturing files for is finished and reviewed. Every time there are changes on the PCB, the manufacturing files have to be re-generated.

# Manufacturing Files:

## Gerber Files

Gerber File | Purpose | Description
xyz.F_CU.grb | Front side copper | Copper pads
xyz.B_CU.grb | Back side copper | Copper pads
xyz.F_Mask.grb | Front side mask | Solder mask. A thin lacquer layer.
xyz.B_Mask.grb | Back side mask | Solder mask. A thin lacquer layer.
xyz.F_Paste.grb | Front side soldering paste | The solder paste for the components (only needed for machine PCB manufacturing)
xyz.B_Paste.grb | Back side soldering paste | The solder paste for the components (only needed for automated SMD production)
xyz.F_SilkS.grb | Front side Silk Screen | All the markings, including text.
xyz.B_SilkS.grb | Back side Silk Screen | All the markings, including text.
xyz.Edge_Cuts.grb | Edge Cuts | The outline of the PCB. For CNC cutting.
xyz.PTH.grb | Plated through holes | Holes in the PCB who are plated. Like vias or THT component holes for example.
xyz.NPTH.grb | Non plated through holes | Holes without plating. Like mounting holes for screws.

Table 1

## Pick and Place data.

Normally *.csv files. One for the front and one for the back. Those files include all the SMD components and their exact location and rotation. Only needed for automated SMD production.

## Bill of Material (BOM)

Bill of Material with all the needed components.

# Process:

## Gerber Files:

- Open the PCB you want to create the Manufacturing Files for, in KiCAD’s Pcbnew.
- Select “Plot” from the “File” menu.
- In the included Layers you need: F.Cu, B.Cu, F.Paste, B.Paste, F.SilkS, B.SilkS, F.Mask, B.Mask and Edge.Cuts.
- Set the Output directory to where you want the files to be created.
- Set the rest of the options as followed:

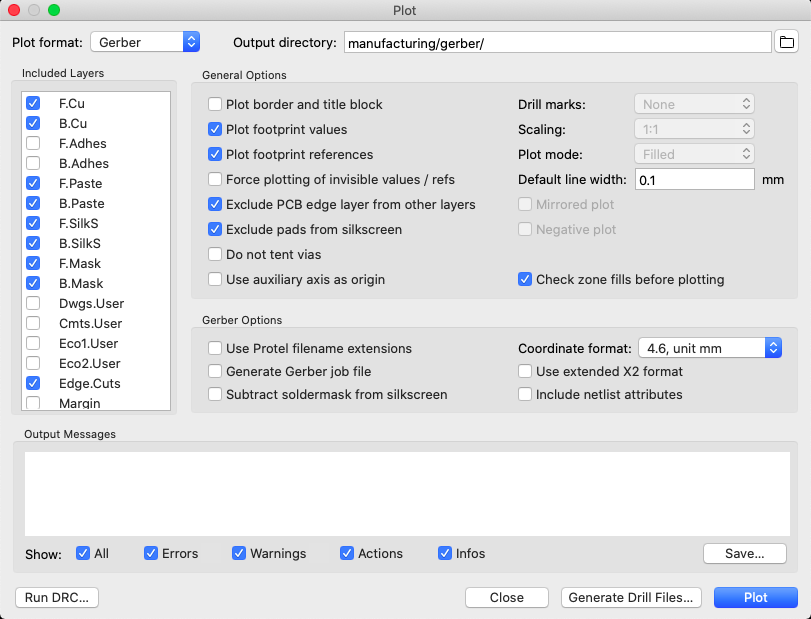
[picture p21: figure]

Figure 1

- Press “Plot”
- If you get asked to refill the zone-fills, because they are out of date, do so.
- KiCAD now generates all the gerber files and stores them in the above specified path.
- Now press “Generate Drill Files”
- Set the Output directory to where you want the files to be created.
- Set the rest of the options as followed:
- (Change Drill unit to Inches, if you need imperial measurements).

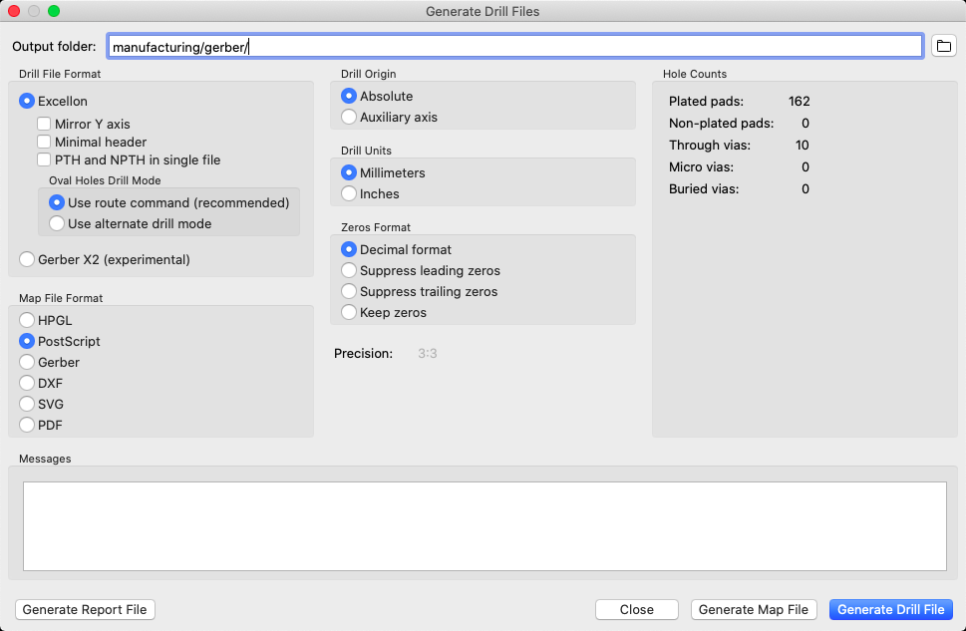
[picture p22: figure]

Figure 2

- KiCAD now generates the PTH and NPTH files and stores them in the above specified path.
- You should now have a full set of Gerber files, ready to send to a PCB manufacturer.

## Pick and Place Files

- To generate the pick and place data, select “File” -> “Fabrication Outputs” -> “Footprint Position (.pos) File”
- Set the Output directory to where you want the files to be created.
- Set the options as follows:
- (Change Units to Inches if you need imperial measurements).

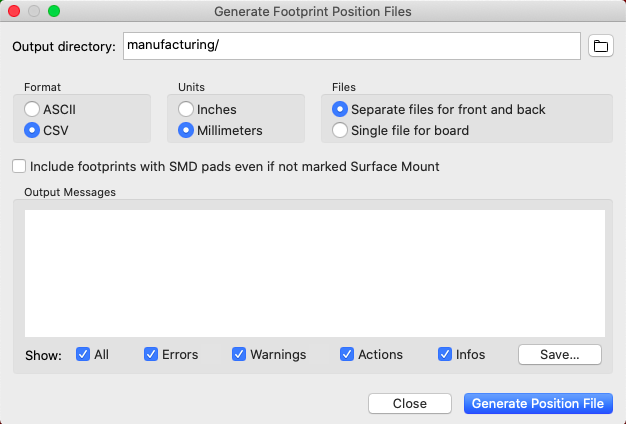
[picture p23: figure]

Figure 3

- Press “Generate Position Files”
- KiCAD now generates the Pick and Place files and stores them in the above specified path.

## BOM File

- Finally, to generate the BOM, select “File” -> “Fabrication Output” -> “BOM File”
- Select a location to save your BOM file and hit “Save”

# Addendum

- Depending on the manufacturer, you may have to change some titles in the Pick and Place files. For example, jlcpcb.com requires the titles to be “Designator”, “Mid X”, “Mid Y”, “Layer” and “Rotation”. You can open the *.csv files in every text editor. Or even better, in MS Excel. There you can change the tiles and save the file. The same may apply to the BOM.

- 2 of 4 – Document: Generating ECAD Manufacturing Files Version: 0.1 Author: Balz Reber Last Update: 06.11.2019

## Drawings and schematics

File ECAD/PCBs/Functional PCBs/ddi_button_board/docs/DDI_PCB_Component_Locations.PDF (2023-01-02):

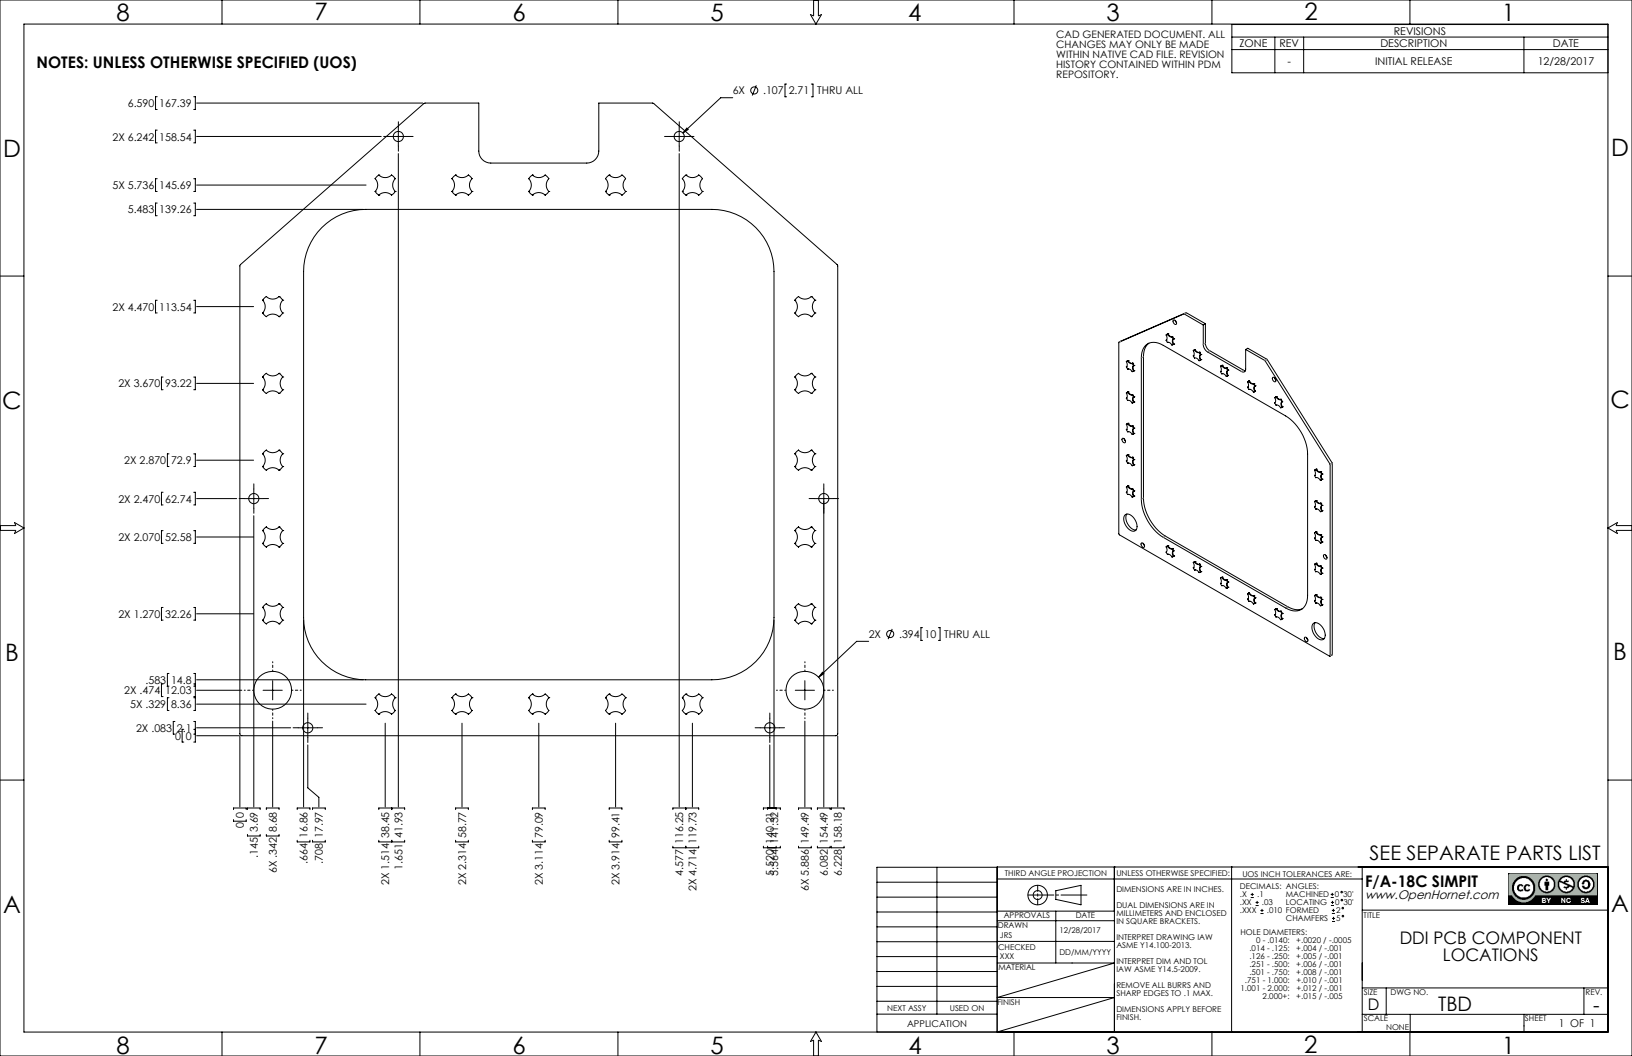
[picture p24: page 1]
.107 2.71 THRU ALL; .394 10 THRU ALL; NEXT ASSY; USED ON; DWG NO.; MACHINED; LOCATING; HOLE DIAMETERS: 0 - .0140: +.0020 / -.0005 .014 - .125: +.004 / -.001 .126 - .250: +.005 / -.001 .251 - .500: +.006 / -.001 .501 - .750: +.008 / -.001 .751 - 1.000: +.010 / -.001 1.001 - 2.000: +.012 / -.001 2.000+: +.015 / -.005 FINISH

CAD GENERATED DOCUMENT. ALL
CHANGES MAY ONLY BE MADE
WITHIN NATIVE CAD FILE. REVISION
HISTORY CONTAINED WITHIN PDM
REPOSITORY.

ZONE | REV | DESCRIPTION | DATE

NOTES: UNLESS OTHERWISE SPECIFIED (UOS)

- | INITIAL RELEASE | 12/28/2017

SEE SEPARATE PARTS LIST
F/A-18C SIMPIT
www.OpenHornet.com
DDI PCB COMPONENT
LOCATIONS
TBD

THIRD ANGLE PROJECTION

UNLESS OTHERWISE SPECIFIED:
DIMENSIONS ARE IN INCHES.
DUAL DIMENSIONS ARE IN
MILLIMETERS AND ENCLOSED
IN SQUARE BRACKETS.
INTERPRET DRAWING IAW
ASME Y14.100-2013.
INTERPRET DIM AND TOL
IAW ASME Y14.5-2009.
REMOVE ALL BURRS AND
SHARP EDGES TO .1 MAX.
DIMENSIONS APPLY BEFORE
FINISH.

UOS INCH TOLERANCES ARE:
DECIMALS:

DD/MM/YYYY

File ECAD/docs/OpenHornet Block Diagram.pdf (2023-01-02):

## LEFT CONSOLE BLOCK DIAGRAM RIGHT CONSOLE BLOCK DIAGRAM

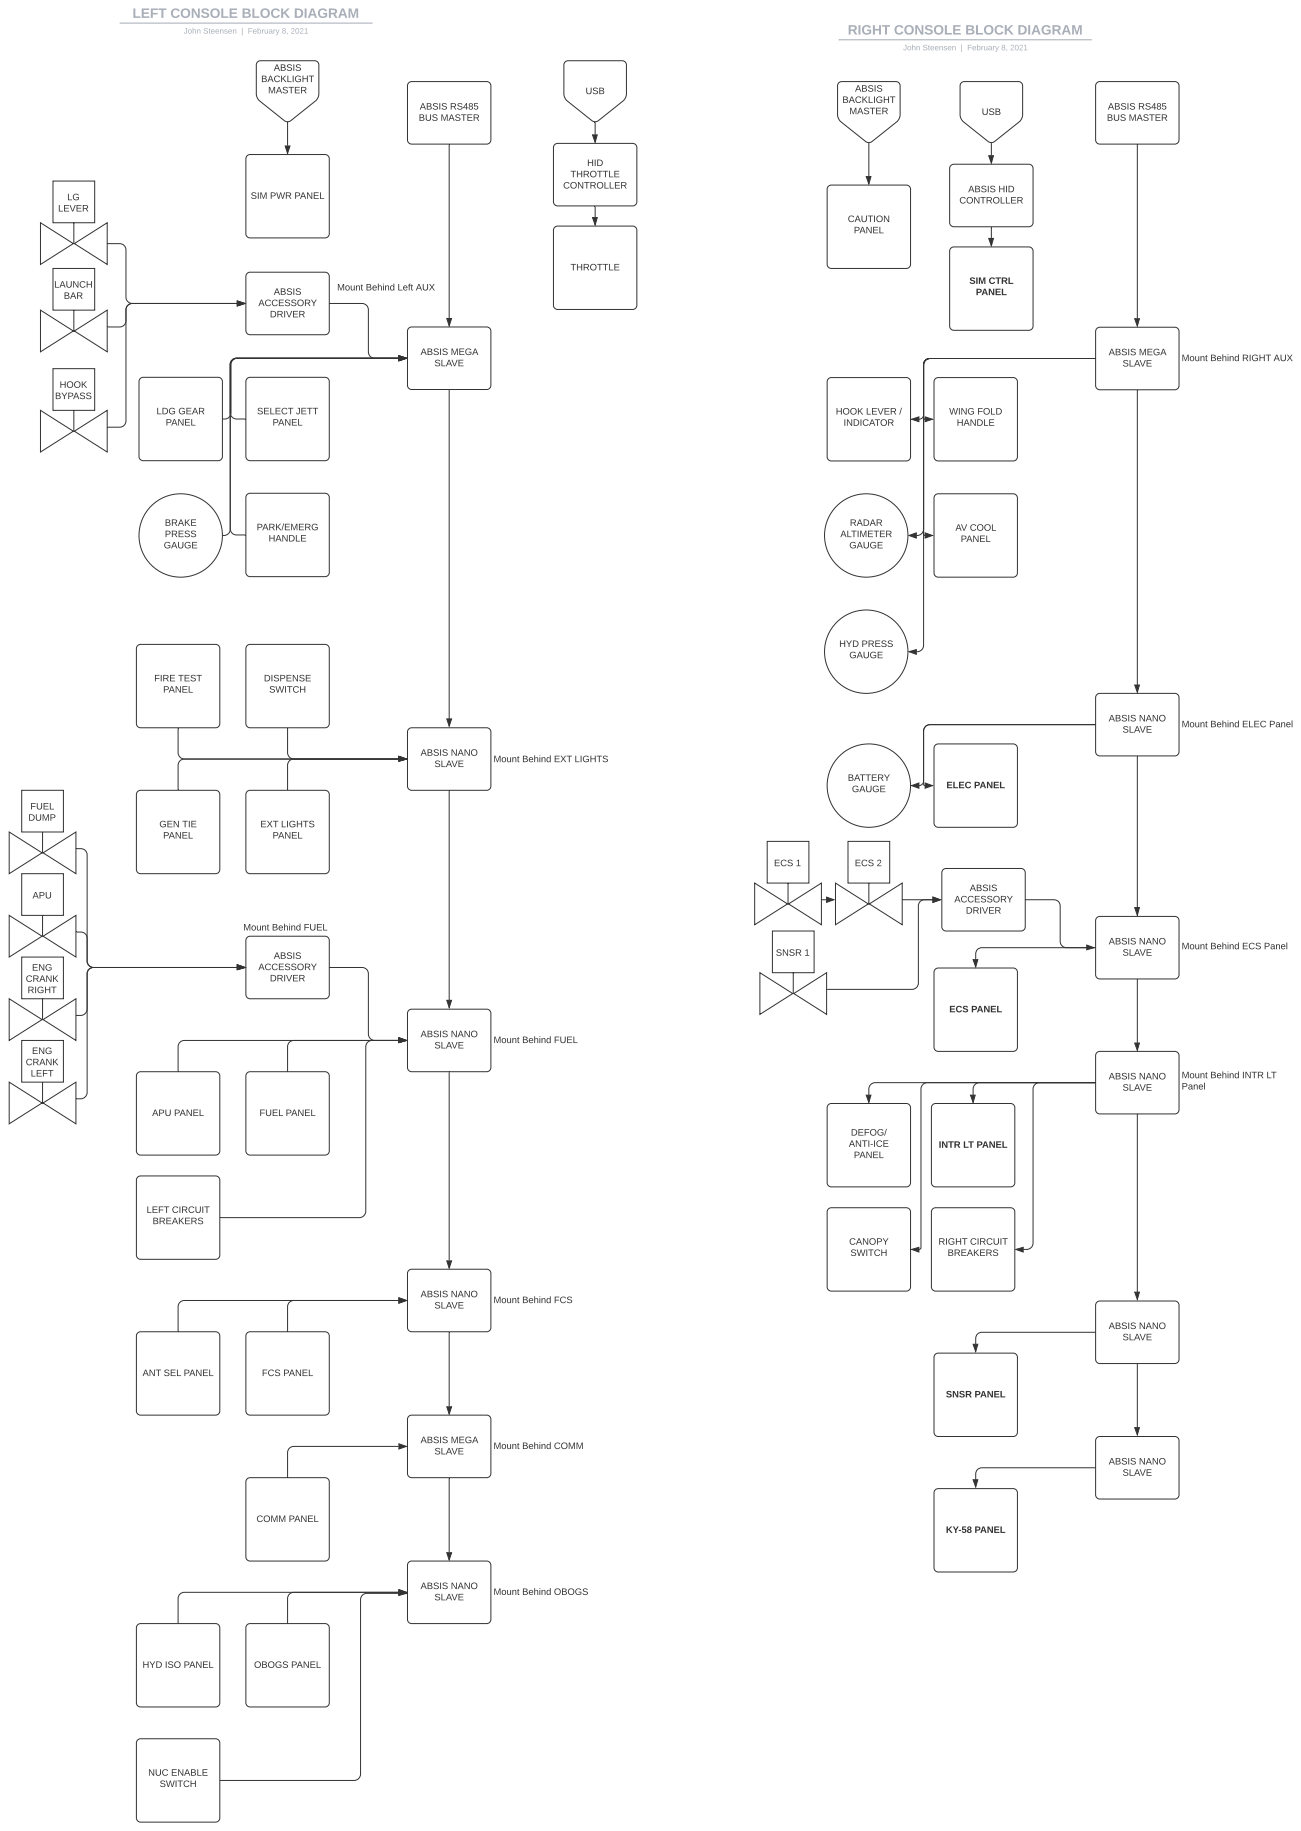
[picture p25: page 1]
ABSIS RS485 BUS MASTER; ABSIS MEGA SLAVE; ABSIS ACCESSORY DRIVER; LG LEVER; LAUNCH BAR; HOOK BYPASS; LDG GEAR PANEL; SELECT JETT PANEL; PARK/EMERG HANDLE; BRAKE PRESS GAUGE; ABSIS NANO SLAVE; EXT LIGHTS PANEL; GEN TIE PANEL; APU PANEL; FUEL PANEL; ANT SEL PANEL; FCS PANEL; COMM PANEL; ENG CRANK RIGHT; APU; ENG CRANK LEFT; FUEL DUMP; NUC ENABLE SWITCH; LEFT CIRCUIT BREAKERS; DISPENSE SWITCH; HYD ISO PANEL; OBOGS PANEL; ABSIS BACKLIGHT MASTER; HOOK LEVER / INDICATOR; WING FOLD HANDLE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

John Steensen | February 8, 2021

SIM PWR PANEL

Mount Behind Left AUX

Mount Behind RIGHT AUX

Mount Behind ELEC Panel

Mount Behind EXT LIGHTS

Mount Behind FUEL

Mount Behind ECS Panel

Mount Behind INTR LT
Panel

INTR LT PANEL

Mount Behind FCS

Mount Behind COMM

Mount Behind OBOGS

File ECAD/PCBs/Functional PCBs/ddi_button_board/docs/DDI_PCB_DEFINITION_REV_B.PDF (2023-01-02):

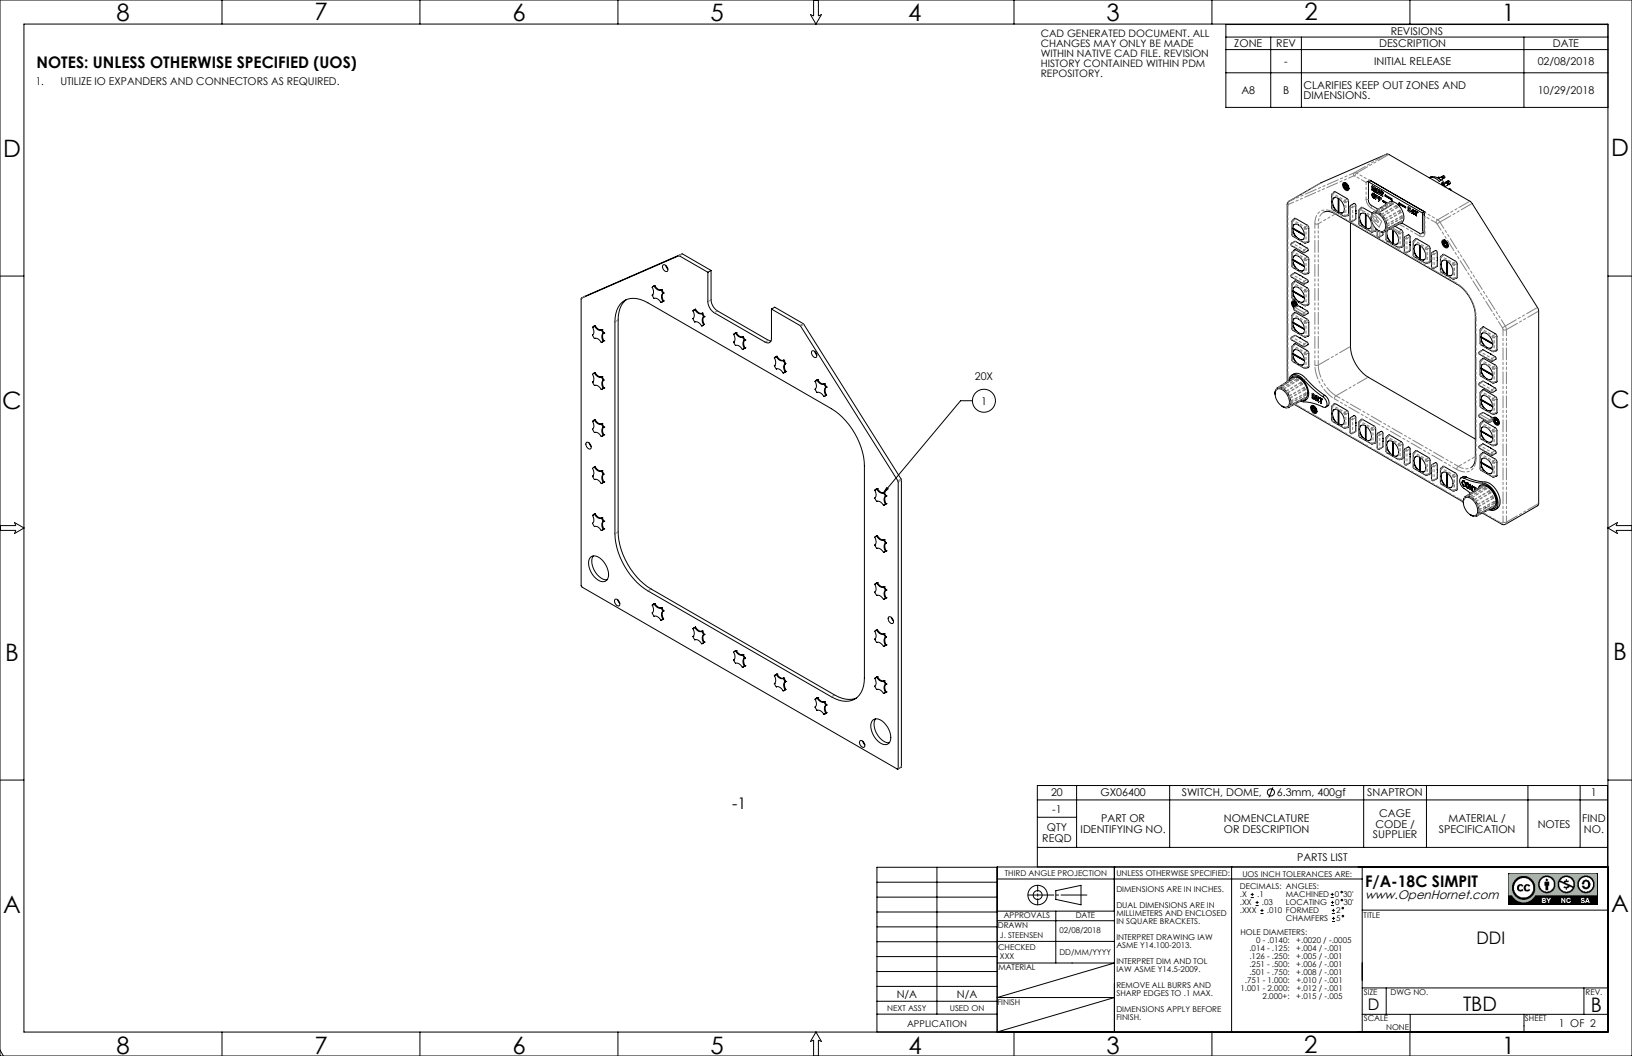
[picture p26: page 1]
SWITCH, DOME, 6.3mm, 400gf; SNAPTRON; PART OR IDENTIFYING NO.; OR DESCRIPTION; CODE /; MATERIAL /; PARTS LIST; F/A-18C SIMPIT; DWG NO.; J. STEENSEN; MACHINED; LOCATING; HOLE DIAMETERS: 0 - .0140: +.0020 / -.0005 .014 - .125: +.004 / -.001 .126 - .250: +.005 / -.001 .251 - .500: +.006 / -.001 .501 - .750: +.008 / -.001 .751 - 1.000: +.010 / -.001 1.001 - 2.000: +.012 / -.001 2.000+: +.015 / -.005 FINISH

CAD GENERATED DOCUMENT. ALL
CHANGES MAY ONLY BE MADE
WITHIN NATIVE CAD FILE. REVISION
HISTORY CONTAINED WITHIN PDM
REPOSITORY.

ZONE | REV | DESCRIPTION | DATE

NOTES: UNLESS OTHERWISE SPECIFIED (UOS)
1. UTILIZE IO EXPANDERS AND CONNECTORS AS REQUIRED.

- | INITIAL RELEASE | 02/08/2018
A8 | B | CLARIFIES KEEP OUT ZONES AND DIMENSIONS. | 10/29/2018

THIRD ANGLE PROJECTION

UNLESS OTHERWISE SPECIFIED:
DIMENSIONS ARE IN INCHES.
DUAL DIMENSIONS ARE IN
MILLIMETERS AND ENCLOSED
IN SQUARE BRACKETS.
INTERPRET DRAWING IAW
ASME Y14.100-2013.
INTERPRET DIM AND TOL
IAW ASME Y14.5-2009.
REMOVE ALL BURRS AND
SHARP EDGES TO .1 MAX.
DIMENSIONS APPLY BEFORE
FINISH.

UOS INCH TOLERANCES ARE:
DECIMALS:

DD/MM/YYYY

N/A | N/A
NEXT ASSY | USED ON

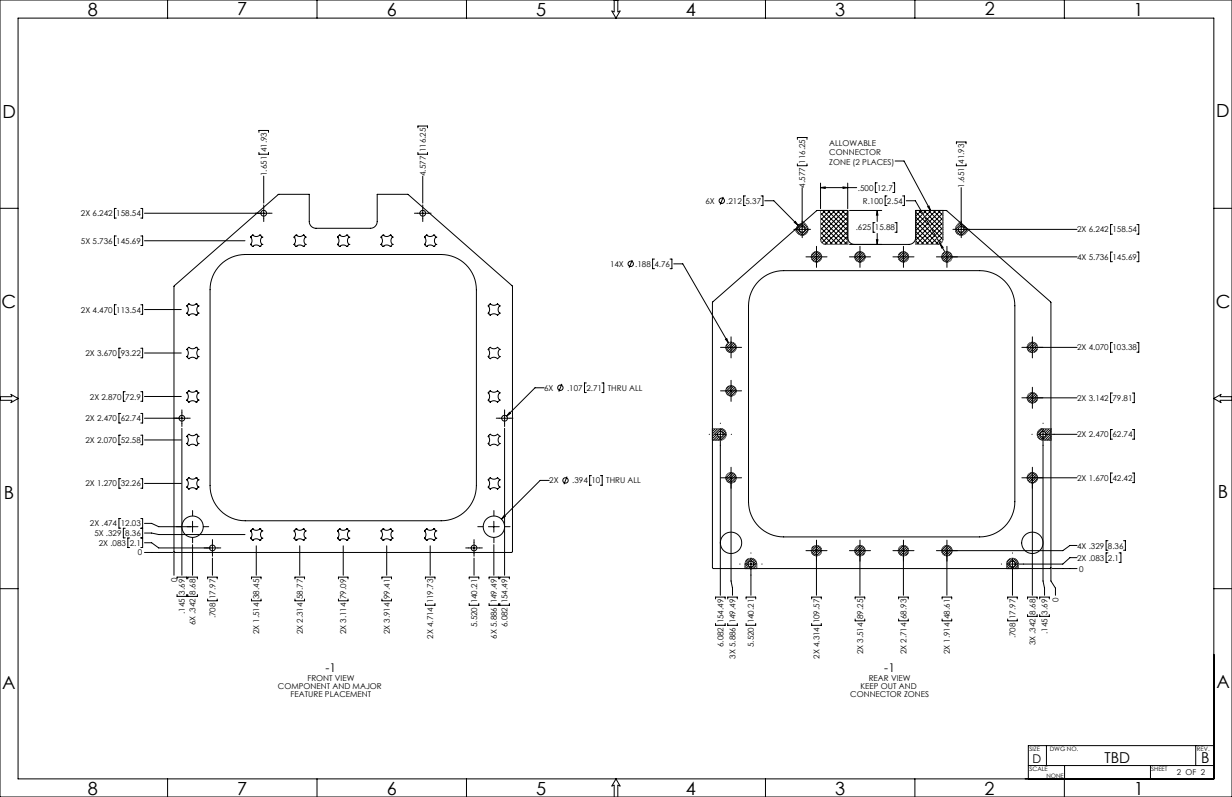
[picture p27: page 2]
.107 2.71 THRU ALL; .394 10 THRU ALL; ZONE (2 PLACES); SIZE DWG NO.; REV.

FRONT VIEW
COMPONENT AND MAJOR
FEATURE PLACEMENT

REAR VIEW
KEEP OUT AND
CONNECTOR ZONES

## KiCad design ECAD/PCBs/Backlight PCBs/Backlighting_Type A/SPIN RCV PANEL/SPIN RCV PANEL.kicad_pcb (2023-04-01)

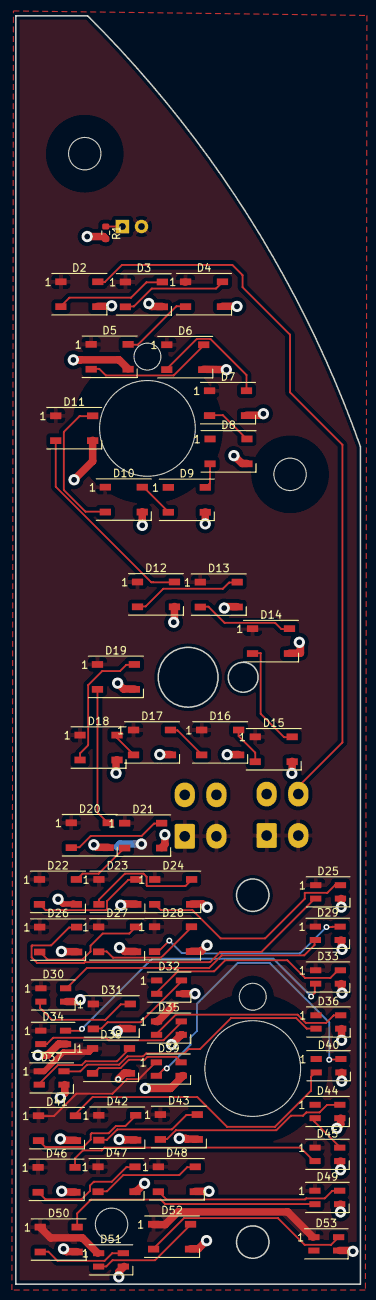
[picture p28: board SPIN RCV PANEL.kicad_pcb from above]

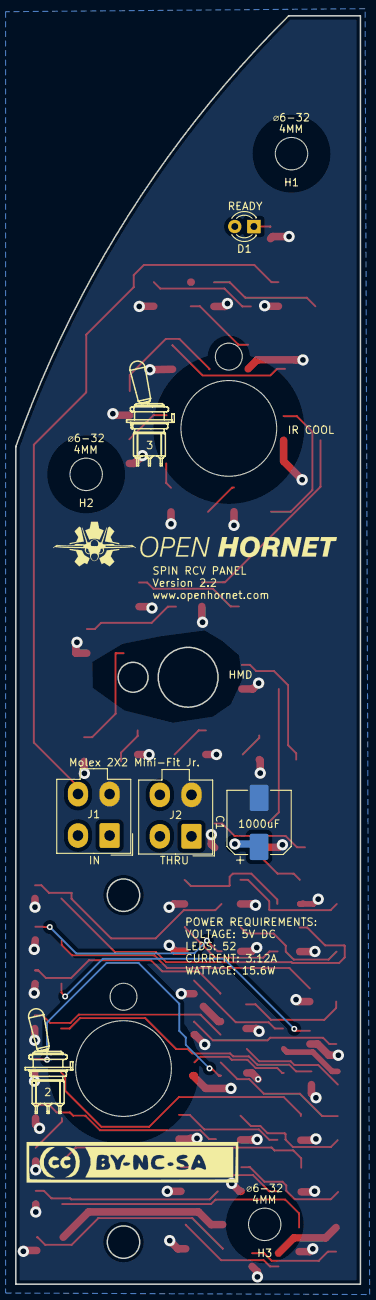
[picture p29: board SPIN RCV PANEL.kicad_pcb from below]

Board: 2 copper layers, 45.7 x 168.3 mm, 58 parts (4 on the bottom side), 55 nets.

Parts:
C1: C_Polarized; CP_Elec_8x10
D1: LED; LED_D3.0mm
D2, D3, D4, D5, D6, D7, D8, D9, D10, D11, D12, D13, D14, D15, D16, D17, D18, D19, D20, D21, D22, D23, D24, D26, D27, D28, D31, D38, D41, D42, D43, D46, D47, D48, D50, D52: WS2812B; LED_WS2812B_PLCC4_5.0x5.0mm_P3.2mm
D25, D29, D30, D32, D33, D34, D35, D36, D37, D39, D40, D44, D45, D49, D51, D53: WS2812B; LED_WS2812B-MINI_PLCC4_3.5x3.5mm_P1.75mm
G1: LOGO; 100SpxToggle
J1, J2: Conn_01x04_Female; Molex_Mini-Fit_Jr_5566-04A_2x02_P4.20mm_Vertical
R1: R; R_0603_1608Metric

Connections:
/DATAIN: D2.4, J1.4
/LED+5V: C1.1, D1.2, D2.1, D3.1, D4.1, D5.1, D6.1, D7.1, D8.1, D9.1, D10.1, D11.1, D12.1, D13.1, D14.1, D15.1, D16.1, D17.1, D18.1, D19.1, D20.1, D21.1, D22.1, D23.1, D24.1, D25.1, D26.1, D27.1, D28.1, D29.1, D30.1, D31.1, D32.1, D33.1, D34.1, D35.1, D36.1, D37.1, D38.1, D39.1, D40.1, D41.1, D42.1, D43.1, D44.1, D45.1, D46.1, D47.1, D48.1, D49.1, D50.1, D51.1, D52.1, D53.1, J1.1, J1.2, J2.1, J2.2
/LEDGND: C1.2, D2.3, D3.3, D4.3, D5.3, D6.3, D7.3, D8.3, D9.3, D10.3, D11.3, D12.3, D13.3, D14.3, D15.3, D16.3, D17.3, D18.3, D19.3, D20.3, D21.3, D22.3, D23.3, D24.3, D25.3, D26.3, D27.3, D28.3, D29.3, D30.3, D31.3, D32.3, D33.3, D34.3, D35.3, D36.3, D37.3, D38.3, D39.3, D40.3, D41.3, D42.3, D43.3, D44.3, D45.3, D46.3, D47.3, D48.3, D49.3, D50.3, D51.3, D52.3, D53.3, J1.3, J2.3, R1.2
unnamed: D1.1, R1.1
unnamed: D2.2, D3.4
unnamed: D3.2, D4.4
unnamed: D4.2, D5.4
unnamed: D5.2, D6.4
unnamed: D6.2, D7.4
unnamed: D7.2, D8.4
unnamed: D8.2, D9.4
unnamed: D10.2, D11.4
unnamed: D9.2, D10.4
unnamed: D11.2, D12.4
unnamed: D12.2, D13.4
unnamed: D13.2, D14.4
unnamed: D14.2, D15.4
unnamed: D15.2, D16.4
unnamed: D16.2, D17.4
unnamed: D17.2, D18.4
unnamed: D18.2, D19.4
unnamed: D19.2, D20.4
unnamed: D20.2, D21.4
unnamed: D21.2, D22.4
unnamed: D22.2, D23.4
unnamed: D23.2, D24.4
unnamed: D24.2, D25.4
unnamed: D25.2, D26.4
unnamed: D26.2, D27.4
unnamed: D27.2, D28.4
unnamed: D28.2, D29.4
unnamed: D29.2, D30.4
unnamed: D30.2, D31.4
unnamed: D31.2, D32.4
unnamed: D32.2, D33.4
unnamed: D33.2, D34.4
unnamed: D34.2, D35.4
unnamed: D35.2, D36.4
unnamed: D36.2, D37.4
unnamed: D37.2, D38.4
unnamed: D38.2, D39.4
unnamed: D39.2, D40.4
unnamed: D40.2, D41.4
unnamed: D41.2, D42.4
unnamed: D42.2, D43.4
unnamed: D43.2, D44.4
unnamed: D44.2, D45.4
unnamed: D45.2, D46.4
unnamed: D46.2, D47.4
unnamed: D47.2, D48.4
unnamed: D48.2, D49.4
unnamed: D49.2, D50.4
unnamed: D50.2, D51.4
unnamed: D51.2, D52.4
unnamed: D52.2, D53.4

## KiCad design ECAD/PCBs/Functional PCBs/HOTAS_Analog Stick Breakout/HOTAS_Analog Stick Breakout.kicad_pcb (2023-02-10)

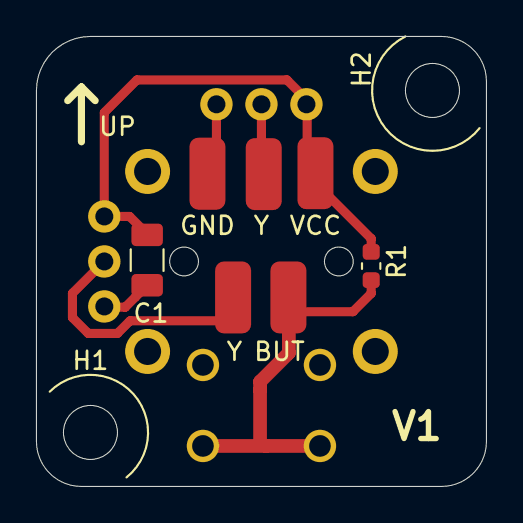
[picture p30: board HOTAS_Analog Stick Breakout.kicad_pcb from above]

Board: 2 copper layers, 25.0 x 25.0 mm, 10 parts (1 on the bottom side), 5 nets.

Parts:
C1: 4.7uF; C_1206_3216Metric
H1, H2: MountingHole; MountingHole_3mm
J2, J3, J4, J5, J6: Conn_01x01; SolderWirePad_1x01_SMD_2x4mm
JOY1: ANALOGSTICK_CENTERPUSH; RKJXV12
R1: 10k; R_0603_1608Metric

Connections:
GND: C1.2, J6.1, JOY1.1, JOY1.4, JOY1.a, JOY1.c
unnamed: J3.1, JOY1.5
unnamed: J4.1, JOY1.2
unnamed: J5.1, JOY1.b, JOY1.d, R1.2
VCC: C1.1, J2.1, JOY1.3, JOY1.6, R1.1

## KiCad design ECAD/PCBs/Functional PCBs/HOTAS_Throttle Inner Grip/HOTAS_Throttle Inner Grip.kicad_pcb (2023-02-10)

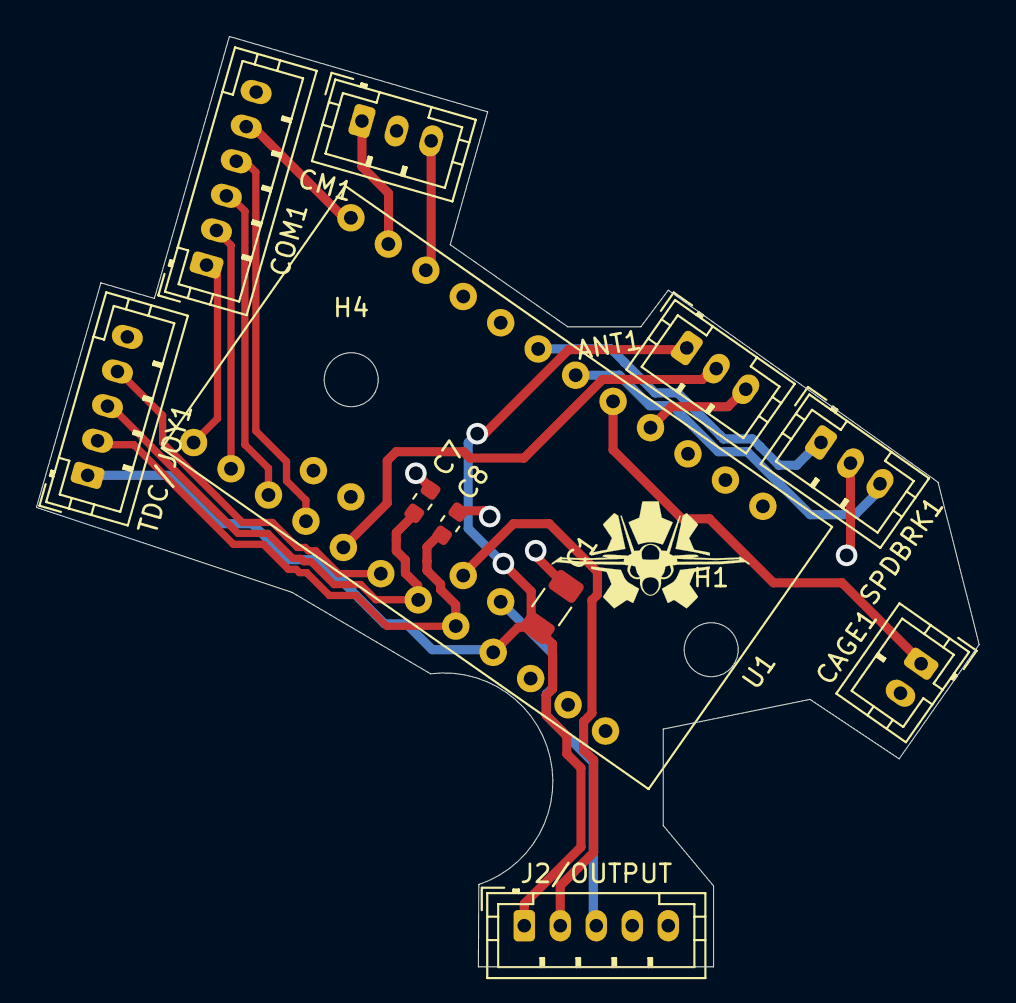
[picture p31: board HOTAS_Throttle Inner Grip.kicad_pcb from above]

Board: 2 copper layers, 52.4 x 51.7 mm, 13 parts (0 on the bottom side), 18 nets.

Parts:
ANT1: Conn_01x03; JST_PH_B3B-PH-K_1x03_P2.00mm_Vertical
C1: 10uF; C_1206_3216Metric
C7, C8: 0.1uF; C_0603_1608Metric
CAGE1: Conn_01x02; JST_PH_B2B-PH-K_1x02_P2.00mm_Vertical
CM1: Conn_01x03; JST_PH_B3B-PH-K_1x03_P2.00mm_Vertical
COM1: COMS; JST_PH_B6B-PH-K_1x06_P2.00mm_Vertical
H1, H4: MountingHole; MountingHole_3mm
J2/OUTPUT: BASE; JST_PH_B5B-PH-K_1x05_P2.00mm_Vertical
SPDBRK1: Conn_01x03; JST_PH_B3B-PH-K_1x03_P2.00mm_Vertical
TDC/JOY1: JOYSTICK; JST_PH_B5B-PH-K_1x05_P2.00mm_Vertical
U1: ProMini_NoProgrammingHeader; Arduino_Mini_Pro_No_Programming_Header

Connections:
/A: COM1.1, U1.13
/ANTENNA_ELEVATION: ANT1.2, U1.17
/B: COM1.2, U1.14
/C: COM1.3, U1.15
/CAGE-UNCAGE: CAGE1.1, U1.5
/COUNTERMEASURES_AFT: CM1.3, U1.10
/COUNTERMEASURES_FWD: CM1.1, U1.11
/D: COM1.4, U1.16
/I2C_DATA: J2/OUTPUT.2, U1.33
/I2C_SCK: J2/OUTPUT.3, U1.34
/JOY_SW: TDC/JOY1.4, U1.18
/JOY_X: C8.1, TDC/JOY1.2, U1.20
/JOY_Y: C7.1, TDC/JOY1.3, U1.19
/PUSH: COM1.5, U1.12
/SPEEDBREAK_EXTEND: SPDBRK1.1, U1.7
/SPEEDBREAK_RETRACT: SPDBRK1.3, U1.6
GND: ANT1.3, C1.2, C7.2, C8.2, CAGE1.2, CM1.2, COM1.6, J2/OUTPUT.5, SPDBRK1.2, TDC/JOY1.5, U1.4, U1.23
VCC: ANT1.1, C1.1, J2/OUTPUT.1, TDC/JOY1.1, U1.21

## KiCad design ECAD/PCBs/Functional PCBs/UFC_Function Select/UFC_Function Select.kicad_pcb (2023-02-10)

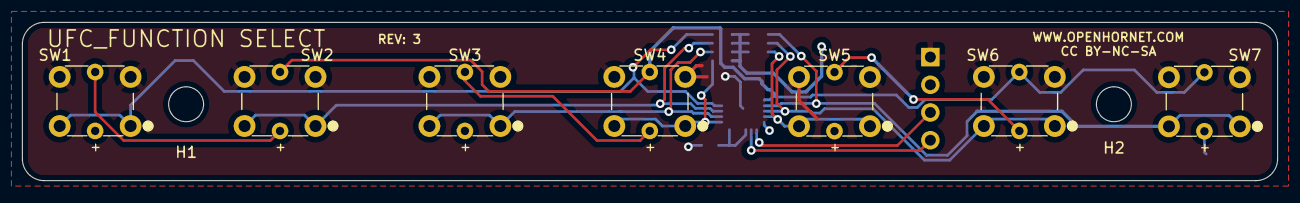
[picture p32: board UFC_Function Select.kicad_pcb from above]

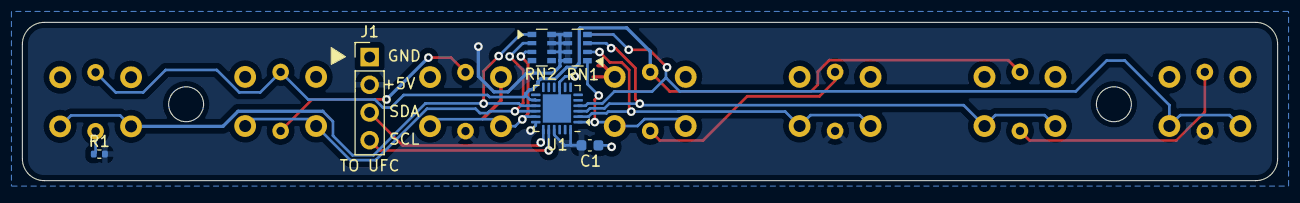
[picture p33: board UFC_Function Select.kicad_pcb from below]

Board: 2 copper layers, 115.0 x 14.5 mm, 15 parts (6 on the bottom side), 16 nets.

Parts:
C1: .1uF; C_0603_1608Metric
H1, H2: MountingHole_3.2mm_M3_DIN965
J1: TO UFC; PinHeader_1x04_P2.54mm_Vertical
R1: 33; R_0402_1005Metric
RN1, RN2: 4.7K; R_Array_Convex_4x0603
SW1, SW2, SW3, SW4, SW5, SW6, SW7: TL1240GQ
U1: AW9523BTQR; WQFN-24-1EP_4x4mm_P0.5mm_EP2.6x2.6mm

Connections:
+5V: C1.1, J1.2, R1.2, RN1.5, RN1.6, RN1.7, RN1.8, RN2.6, RN2.7, RN2.8, SW1.5, SW3.5, SW5.5, U1.18, U1.21, U1.24
/AP-: SW1.6, SW2.5
/AP_SW: RN1.4, SW1.1, U1.4
/BCN+: SW5.6, SW6.5
/BCN-: SW2.6, SW4.6, SW6.6, SW7.6, U1.14
/BCN_SW: RN2.2, SW6.1, U1.16
/DL_SW: RN2.3, SW5.1, U1.17
/IFF_SW: RN1.3, SW2.1, U1.3
/ILS+: SW3.6, SW4.5
/ILS_SW: RN1.1, SW4.1, U1.1
/ON+: R1.1, SW7.5
/ON_SW: RN2.1, SW7.1, U1.15
/TCN_SW: RN1.2, SW3.1, U1.2
GND: C1.2, J1.1, SW1.2, SW2.2, SW3.2, SW4.2, SW5.2, SW6.2, SW7.2, U1.9, U1.25
SCL: J1.4, U1.20
SDA: J1.3, U1.19

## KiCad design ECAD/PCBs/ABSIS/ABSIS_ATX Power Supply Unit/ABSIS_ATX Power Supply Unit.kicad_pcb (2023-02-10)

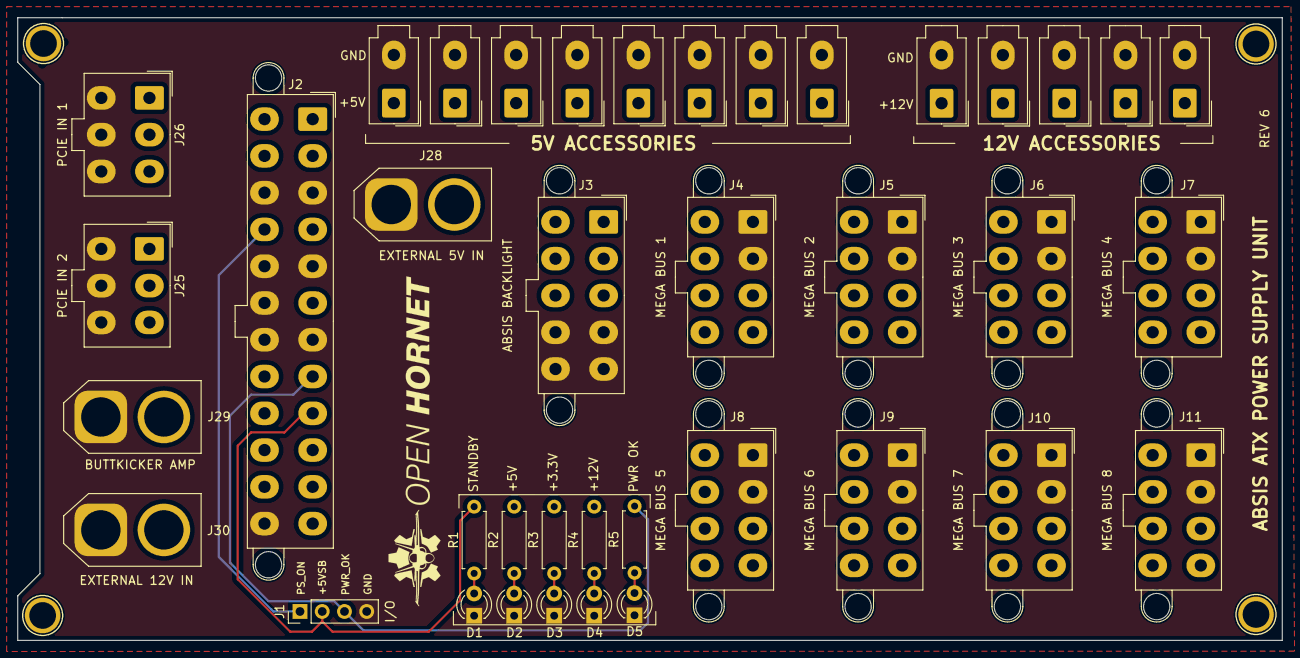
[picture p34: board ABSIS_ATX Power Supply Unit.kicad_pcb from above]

Board: 4 copper layers, 144.4 x 71.1 mm, 43 parts (0 on the bottom side), 12 nets.

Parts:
D1: Blue LED; LED_D3.0mm
D2, D3, D4, D5: Green LED; LED_D3.0mm
H1, H2, H3, H4: MountingHole; Arduino_1pin
J1: I/O; PinHeader_1x04_P2.54mm_Vertical
J2: ATX-24; Molex_Mini-Fit_Jr_5566-24A2_2x12_P4.20mm_Vertical
J3: ABSIS BACKLIGHT; Molex_Mini-Fit_Jr_5566-10A2_2x05_P4.20mm_Vertical
J4: MEGA BUS 1; Molex_Mini-Fit_Jr_5566-08A2_2x04_P4.20mm_Vertical
J5: MEGA BUS 2; Molex_Mini-Fit_Jr_5566-08A2_2x04_P4.20mm_Vertical
J6: MEGA BUS 3; Molex_Mini-Fit_Jr_5566-08A2_2x04_P4.20mm_Vertical
J7: MEGA BUS 4; Molex_Mini-Fit_Jr_5566-08A2_2x04_P4.20mm_Vertical
J8: MEGA BUS 5; Molex_Mini-Fit_Jr_5566-08A2_2x04_P4.20mm_Vertical
J9: MEGA BUS 6; Molex_Mini-Fit_Jr_5566-08A2_2x04_P4.20mm_Vertical
J10: MEGA BUS 7; Molex_Mini-Fit_Jr_5566-08A2_2x04_P4.20mm_Vertical
J11: MEGA BUS 8; Molex_Mini-Fit_Jr_5566-08A2_2x04_P4.20mm_Vertical
J12: 5V Accessory 1; Molex_Mini-Fit_Jr_5566-02A_2x01_P4.20mm_Vertical
J13: 5V Accessory 2; Molex_Mini-Fit_Jr_5566-02A_2x01_P4.20mm_Vertical
J14: 5V Accessory 3; Molex_Mini-Fit_Jr_5566-02A_2x01_P4.20mm_Vertical
J15: 5V Accessory 4; Molex_Mini-Fit_Jr_5566-02A_2x01_P4.20mm_Vertical
J16: 5V Accessory 5; Molex_Mini-Fit_Jr_5566-02A_2x01_P4.20mm_Vertical
J17: 5V Accessory 6; Molex_Mini-Fit_Jr_5566-02A_2x01_P4.20mm_Vertical
J18: 5V Accessory 7; Molex_Mini-Fit_Jr_5566-02A_2x01_P4.20mm_Vertical
J19: 5V Accessory 8; Molex_Mini-Fit_Jr_5566-02A_2x01_P4.20mm_Vertical
J20: 12V Accessory 1; Molex_Mini-Fit_Jr_5566-02A_2x01_P4.20mm_Vertical
J21: 12V Accessory 2; Molex_Mini-Fit_Jr_5566-02A_2x01_P4.20mm_Vertical
J22: 12V Accessory 3; Molex_Mini-Fit_Jr_5566-02A_2x01_P4.20mm_Vertical
J23: 12V Accessory 4; Molex_Mini-Fit_Jr_5566-02A_2x01_P4.20mm_Vertical
J24: 12V Accessory 5; Molex_Mini-Fit_Jr_5566-02A_2x01_P4.20mm_Vertical
J25: PCIE IN 2; Molex_Mini-Fit_Jr_5566-06A_2x03_P4.20mm_Vertical
J26: PCIE IN 1; Molex_Mini-Fit_Jr_5566-06A_2x03_P4.20mm_Vertical
J28: EXTERNAL 5V IN; AMASS_XT60-M_1x02_P7.20mm_Vertical
J29: BUTTKICKER AMP; AMASS_XT60-F_1x02_P7.20mm_Vertical
J30: EXTERNAL 12V IN; AMASS_XT60-M_1x02_P7.20mm_Vertical
R1, R2, R5: 150; R_Axial_DIN0207_L6.3mm_D2.5mm_P7.62mm_Horizontal
R3: 56; R_Axial_DIN0207_L6.3mm_D2.5mm_P7.62mm_Horizontal
R4: 560; R_Axial_DIN0207_L6.3mm_D2.5mm_P7.62mm_Horizontal

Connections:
/+3.3V_SUPPLY: J2.1, J2.2, J2.12, J2.13, J4.5, J5.5, J6.5, J7.5, J8.5, J9.5, J10.5, J11.5, R3.2
/+5VSB_SUPPLY: J1.2, J2.9, R1.2
/+5V_SUPPLY: J2.4, J2.6, J2.21, J2.22, J2.23, J3.1, J3.2, J3.3, J3.6, J3.7, J4.6, J4.7, J5.6, J5.7, J6.6, J6.7, J7.6, J7.7, J8.6, J8.7, J9.6, J9.7, J10.6, J10.7, J11.6, J11.7, J12.1, J13.1, J14.1, J15.1, J16.1, J17.1, J18.1, J19.1, J28.2, R2.2
/+12V_SUPPLY: J2.10, J2.11, J3.8, J4.3, J4.4, J4.8, J5.3, J5.4, J5.8, J6.3, J6.4, J6.8, J7.3, J7.4, J7.8, J8.3, J8.4, J8.8, J9.3, J9.4, J9.8, J10.3, J10.4, J10.8, J11.3, J11.4, J11.8, J20.1, J21.1, J22.1, J23.1, J24.1, J25.1, J25.2, J25.3, J26.1, J26.2, J26.3, J29.2, J30.2, R4.2
/PS_ON: J1.1, J2.16
/PWR_OK: J1.3, J2.8, R5.2
GND: D1.1, D2.1, D3.1, D4.1, D5.1, J1.4, J2.3, J2.5, J2.7, J2.15, J2.17, J2.18, J2.19, J2.24, J3.4, J3.5, J3.9, J3.10, J4.1, J4.2, J5.1, J5.2, J6.1, J6.2, J7.1, J7.2, J8.1, J8.2, J9.1, J9.2, J10.1, J10.2, J11.1, J11.2, J12.2, J13.2, J14.2, J15.2, J16.2, J17.2, J18.2, J19.2, J20.2, J21.2, J22.2, J23.2, J24.2, J25.4, J25.5, J25.6, J26.4, J26.5, J26.6, J28.1, J29.1, J30.1
unnamed: D1.2, R1.1
unnamed: D2.2, R2.1
unnamed: D3.2, R3.1
unnamed: D4.2, R4.1
unnamed: D5.2, R5.1

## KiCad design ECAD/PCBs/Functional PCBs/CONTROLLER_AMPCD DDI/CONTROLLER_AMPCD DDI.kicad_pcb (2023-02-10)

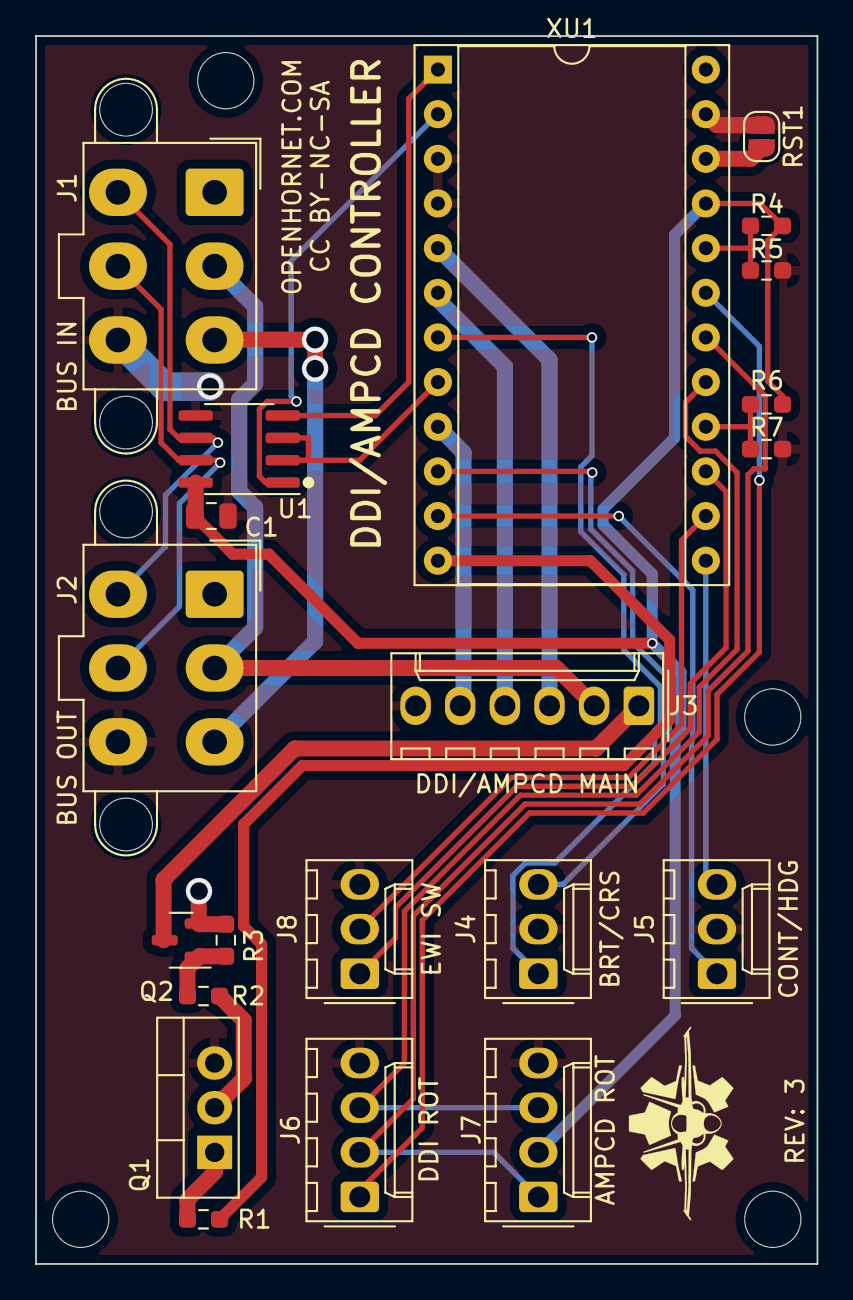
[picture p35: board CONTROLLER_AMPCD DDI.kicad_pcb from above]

Board: 2 copper layers, 44.5 x 69.8 mm, 25 parts (0 on the bottom side), 30 nets.

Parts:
C1: 0.1uF; C_0805_2012Metric
H1, H2, H3, H4: MountingHole; MountingHole_3.2mm_M3
J1: BUS IN; Molex_Mini-Fit_Jr_5566-06A2_2x03_P4.20mm_Vertical
J2: BUS OUT; Molex_Mini-Fit_Jr_5566-06A2_2x03_P4.20mm_Vertical
J3: DDI/AMPCD MAIN; Molex_KK-254_AE-6410-06A_1x06_P2.54mm_Vertical
J4: BRT/CRS; Molex_KK-254_AE-6410-03A_1x03_P2.54mm_Vertical
J5: CONT/HDG; Molex_KK-254_AE-6410-03A_1x03_P2.54mm_Vertical
J6: DDI ROT; Molex_KK-254_AE-6410-04A_1x04_P2.54mm_Vertical
J7: AMPCD ROT; Molex_KK-254_AE-6410-04A_1x04_P2.54mm_Vertical
J8: EWI SW; Molex_KK-254_AE-6410-03A_1x03_P2.54mm_Vertical
Q1: IRFB3206PBF; TO-220-3_Vertical
Q2: IRLML6402TRPBF; SOT-23
R1, R2, R3, R4, R5, R6, R7: 10K; R_0603_1608Metric_Pad0.98x0.95mm_HandSolder
RST1: RST; SolderJumper-2_P1.3mm_Open_RoundedPad1.0x1.5mm
U1: MAX487EESA+T; SOIC-8_3.9x4.9mm_P1.27mm
XU1: ProMicro_5V/16Hz; DIP-24_W15.24mm_Socket

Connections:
+5V: C1.1, J7.2, R4.2, R6.2, U1.8, XU1.21
/+3.3V_SUPPLY: J1.3, J2.3
/+5V_SUPPLY: J1.2, J2.2, J3.2
/+12V_PWM: J3.1, Q2.3
/+12V_SUPPLY: J1.1, J2.1, Q2.2, R3.2, XU1.24
/A0: J6.3, J7.3, XU1.17
/A1: J6.2, J7.1, XU1.18
/A2: J6.1, XU1.19
/A3: R4.1, R5.2, XU1.20
/BUS-A: J1.4, J2.4, U1.6
/BUS-B: J1.5, J2.5, U1.7
/D4_A6: J4.1, XU1.7
/D7: J4.3, XU1.10
/D8_A8: J5.1, XU1.11
/D14_MISO: J8.1, XU1.15
/D15_SCK: R6.1, R7.2, XU1.16
/D16_MOSI: J8.2, XU1.14
/RST: RST1.2, XU1.22
/RX1_D0: U1.1, XU1.2
/SDA_D2: J3.3, XU1.5
/TX0_D1: U1.4, XU1.1
/~D5: U1.2, U1.3, XU1.8
/~D6_A7: J3.5, XU1.9
/~D9_A9: R1.1, XU1.12
/~D10_A10: J5.3, XU1.13
/~SCL_D3: J3.4, XU1.6
GND: C1.2, J1.6, J2.6, J3.6, J4.2, J5.2, J6.4, J7.4, J8.3, Q1.3, R5.1, R7.1, RST1.1, U1.5, XU1.3, XU1.4, XU1.23
unnamed: Q1.1, R1.2
unnamed: Q1.2, R2.2
unnamed: Q2.1, R2.1, R3.1

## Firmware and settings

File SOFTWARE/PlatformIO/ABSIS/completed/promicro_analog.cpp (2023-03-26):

#include <Joystick.h>

Joystick_ Joystick(JOYSTICK_DEFAULT_REPORT_ID, JOYSTICK_TYPE_GAMEPAD,
                   11, 4,
                   false, false, false,
                   false, false, false,
                   false, false,
                   false, false, false);

/*----PIN OUT GUIDE----15 DIGITAL PINS AVAILABLE--------|
|--------ARDUINO--------|---IN GAME--|-----ABSIS_ALE----|
|-PIN NAME--|---PIN #---|---JOYBTN---|-ID ON SILKSCREEN-|
|-------------------------------------------------------|
|----RX-----|-----0-----|------------|------------------| *USED BY RS485 BUS CONTROLLER
|----TX-----|-----1-----|------------|------------------| *USED BY RS485 BUS CONTROLLER
|----GND----|-----------|------------|--------GND-------| CONNECTED TO GROUND PLANE
|----GND----|-----------|------------|--------GND-------| CONNECTED TO GROUND PLANE
|----SDA----|-----2-----|--JOYBTN 0--|--------D2--------| DIGITAL PIN 2
|----SCL----|-----3-----|--JOYBTN 1--|--------D3--------| DIGITAL PIN 3
|----A6-----|-----4-----|--JOYBTN 2--|--------D4/A6-----| DIGITAL PIN 4 or ANALOG PIN 6
|-----------|-----5-----|------------|------------------| *USED BY RS485 BUS CONTROLLER
|----A7-----|-----6-----|--JOYBTN 3--|--------D6/A7-----| DIGITAL PIN 6
|-----------|-----7-----|--JOYBTN 4--|--------D7--------| DIGITAL PIN 7
|----A8-----|-----8-----|--JOYBTN 5--|--------D8/A8-----| DIGITAL PIN 8 or ANALOG PIN 8
|----A9-----|-----9-----|--JOYBTN 6--|--------D9/A9-----| DIGITAL PIN 9 or ANALOG PIN 9
|----A10----|-----10----|--JOYBTN 7--|--------D10/A10---| DIGITAL PIN 10 or ANALOG PIN 10
|----MOSI---|-----16----|--JOYBTN 8--|--------D16-------| DIGITAL PIN 16
|----MISO---|-----14----|--JOYBTN 9--|--------D14-------| DIGITAL PIN 14
|----SCLK---|-----15----|--JOYBTN 10-|--------D15-------| DIGITAL PIN 15
|----A0-----|-----18----|--JOYBTN 11-|--------A0--------| DIGITAL PIN 18 or ANALOG PIN 0
|----A1-----|-----19----|--JOYBTN 12-|--------A1--------| DIGITAL PIN 19 or ANALOG PIN 1
|----A2-----|-----20----|--JOYBTN 13-|--------A2--------| DIGITAL PIN 20 or ANALOG PIN 2
|----A3-----|-----21----|--JOYBTN 14-|--------A3--------| DIGITAL PIN 21 or ANALOG PIN 3
|----VCC----|-----------|------------|--------+5v-------| +5V POWER
|----RST----|-----------|------------|--------RST-------| RESET
|----GND----|-----------|------------|--------GND-------| CONNECTED TO GROUND PLANE
|----RAW----|-----------|------------|--------+12v------| +12V POWER

*/

const int buttonPins[] = {2, 3, 4, 6, 7, 8, 9, 10, 16, 14, 15};  // Button pins
const int numButtons = sizeof(buttonPins) / sizeof(buttonPins[0]);  // Number of buttons

const int analogPins[] = {A0, A1, A2, A3};
const int numAnalogPins = sizeof(analogPins) / sizeof(analogPins[0]);

void setup() {
  Joystick.begin();
  Serial.begin(115200);
  for (int i = 0; i < numButtons; i++) {
    pinMode(buttonPins[i], INPUT_PULLUP);
  }
  for (int i = 0; i < numAnalogPins; i++) {
    pinMode(analogPins[i], INPUT);
  }

}


void loop() {
  for (int i = 0; i < numButtons; i++) {
    int buttonState = !digitalRead(buttonPins[i]);
    Joystick.setButton(i, buttonState);
    Serial.print("Button ");
    Serial.print(i);
    Serial.print(": ");
    Serial.println(buttonState);
  }

  int x = analogRead(analogPins[0]);
  x = map(x, 0, 1023, -127, 127);
  Joystick.setXAxis(x);

  int y = analogRead(analogPins[1]);
  y = map(y, 0, 1023, -127, 127);
  Joystick.setYAxis(y);

  int rx = analogRead(analogPins[2]);
  rx = map(rx, 0, 1023, -127, 127);
  Joystick.setRxAxis(rx);

  int ry = analogRead(analogPins[3]);
  ry = map(ry, 0, 1023, -127, 127);
  Joystick.setRyAxis(ry);

  Joystick.sendState();
  delay(20);
}

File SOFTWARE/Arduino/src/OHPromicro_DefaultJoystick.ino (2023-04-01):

/*----PIN OUT GUIDE----15 DIGITAL PINS AVAILABLE--------|
|--------ARDUINO--------|---IN GAME--|-----ABSIS_ALE----|
|-PIN NAME--|---PIN #---|---JOYBTN---|-ID ON SILKSCREEN-|
|-------------------------------------------------------|
|----RX-----|-----0-----|------------|------------------| *USED BY RS485 BUS CONTROLLER
|----TX-----|-----1-----|------------|------------------| *USED BY RS485 BUS CONTROLLER
|----GND----|-----------|------------|--------GND-------| CONNECTED TO GROUND PLANE
|----GND----|-----------|------------|--------GND-------| CONNECTED TO GROUND PLANE
|----SDA----|-----2-----|--JOYBTN 0--|--------D2--------| DIGITAL PIN 2
|----SCL----|-----3-----|--JOYBTN 1--|--------D3--------| DIGITAL PIN 3
|----A6-----|-----4-----|--JOYBTN 2--|--------D4/A6-----| DIGITAL PIN 4 or ANALOG PIN 6
|-----------|-----5-----|------------|------------------| *USED BY RS485 BUS CONTROLLER
|----A7-----|-----6-----|--JOYBTN 3--|--------D6/A7-----| DIGITAL PIN 6
|-----------|-----7-----|--JOYBTN 4--|--------D7--------| DIGITAL PIN 7
|----A8-----|-----8-----|--JOYBTN 5--|--------D8/A8-----| DIGITAL PIN 8 or ANALOG PIN 8
|----A9-----|-----9-----|--JOYBTN 6--|--------D9/A9-----| DIGITAL PIN 9 or ANALOG PIN 9
|----A10----|-----10----|--JOYBTN 7--|--------D10/A10---| DIGITAL PIN 10 or ANALOG PIN 10
|----MOSI---|-----16----|--JOYBTN 8--|--------D16-------| DIGITAL PIN 16
|----MISO---|-----14----|--JOYBTN 9--|--------D14-------| DIGITAL PIN 14
|----SCLK---|-----15----|--JOYBTN 10-|--------D15-------| DIGITAL PIN 15
|----A0-----|-----18----|--JOYBTN 11-|--------A0--------| DIGITAL PIN 18 or ANALOG PIN 0
|----A1-----|-----19----|--JOYBTN 12-|--------A1--------| DIGITAL PIN 19 or ANALOG PIN 1
|----A2-----|-----20----|--JOYBTN 13-|--------A2--------| DIGITAL PIN 20 or ANALOG PIN 2
|----A3-----|-----21----|--JOYBTN 14-|--------A3--------| DIGITAL PIN 21 or ANALOG PIN 3
|----VCC----|-----------|------------|--------+5v-------| +5V POWER
|----RST----|-----------|------------|--------RST-------| RESET
|----GND----|-----------|------------|--------GND-------| CONNECTED TO GROUND PLANE
|----RAW----|-----------|------------|--------12v-------| 12V POWER


READ ME FIRST!  The guide above is just a reference to show you what Pro Micro pins are digital, analog, etc and how 
they're attached to the ABSIS_ALE.  

1:  Change the constant integers below as required:
  a.  Set "const int numButtons = ##" to the number of digital pins you want (max 15)
  b.  Comment "const int RxAxisPin = A0;" if you would rather use that pin as Digital Pin 18 instead of Analog Pin A0.
  c.  Comment "const int RyAxisPin = A1;" if you would rather use that pin as Digital Pin 19 instead of Analog Pin A1.  
  d.  Comment "const int RzAxisPin = A2;" if you would rather use that pin as Digital Pin 20 instead of Analog Pin A2.
  e.  Comment "const int ThrottlePin = A3;" if you would rather use that pin as Digital Pin 21 instead of Analog Pin A3.  
  f.  Add the pins you wish to have to --> "const int buttonPins[] = {2, 3, 4, 6, 7, 8, 9, 10, 16, 14, 15};"  Remember to delete 18/19/20/21 from the list if you're using them as Analog Pins

2:  Change Joystick Constructor
  a.  Set the HIDreportID (the first value after Joystick_ Joystick, e.g ""0x13"") to a different number for each Pro Micro you wish to flash.  This helps the computer differentiate which arduino is talking.
  b.  Leave "Joystick_Type_Joystick" alone.
  c.  If using Rx, Ry, Rz, or Throttle Axis, make sure you change "false" to "true" for each axis as required.  See comments below for details
*/


#include <Joystick.h>

const int numButtons = 15;    
//const int RxAxisPin = A0;
//const int RyAxisPin = A1;
//const int RzAxisPin = A2;
//const int ThrottlePin = A3;
const int buttonPins[] = {2, 3, 4, 6, 7, 8, 9, 10, 16, 14, 15, 18, 19, 20, 21};  // Digital pins

// Initialize the Joystick library
Joystick_ Joystick(0x12, JOYSTICK_TYPE_JOYSTICK, 
          numButtons, 0,                  //Number of Digital Buttons, Number of HatSwitch Buttons
          false, false, false,            //No X, Y, Z Axis
          false, false, false,            //Rx, Ry, activated, but no Rz Axis
          false, false,                   //No Rudder or Throttle
          false, false, false);           //No Accelerator, Break, or Steering


//------------------------DONT EDIT BELOW THIS LINE----------------------//

void setup() {
  Joystick.begin();
  // Initialize the digital button pins as inputs
  for (int i = 0; i < numButtons; i++) {
    pinMode(buttonPins[i], INPUT_PULLUP);
  }
}

void loop() {
/*-----------REMOVE THIS COMMENT IF USING THE ANALOG PINS AS AXIS----------------------

    // Read the Rx, Ry, Rz, and Throttle axis values and send them to the joystick
  int RxAxisValue = analogRead(RxAxisPin);
  Joystick.setRxAxis(RxAxisValue);

  int RyAxisValue = analogRead(RyAxisPin);
  Joystick.setRyAxis(RyAxisValue);

  int RzAxisValue = analogRead(RzAxisPin);
  Joystick.setRzAxis(RzAxisValue);

  int ThrottleValue = analogRead(ThrottlePin);
  Joystick.setThrottle(RyAxisValue);

-----------REMOVE THIS COMMENT IF USING THE ANALOG PINS AS AXIS----------------------*/  

  // Read the state of each button and set the corresponding
  // joystick button state
  for (int i = 0; i < numButtons; i++) {
    Joystick.setButton(i, !digitalRead(buttonPins[i]));
  }

  // Send the joystick state to the computer
  Joystick.sendState();

  // Wait a short delay to avoid sending too many joystick states per second
  delay(20);
}

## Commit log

2023-01-02 Initial Commit - Left Console
    First commit of the Left Console Assembly: It is not complete in terms of everything needed for OpenHornet. It contains the files that I've modified and/or exported to be cut, printed, lased, etc.
    1: The majority of the left console is there, however, there may be parts missing from the OH repository.
    2: Some of the parts may be outdated or from previous versions of assemblies with OpenHornet that I've already printed out and am currently using.
    [615250 - GEAR, PINION, .250 BORE, 32 PITCH, .75 PD, 24 TOOTH, .813 OD, BRASS, SERVOCITY v1.stl, 615250_Gear Blank.STL, 90176A122 - SPACER, #4 X .1875 OD X .812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]
2023-01-02 Initial Upload - Remaining OH Simplit files
    Remaining files not including the Left Console Assembly.
    +ECAD
    +Additional Resources
    [.55 SQ Indicator Actuator.STL, .55 SQ Indicator Bezel.STL, 01x1_Pin_Header_2.54mm.STEP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]
2023-01-02 LC Knobs Update
    Added 3 Knobs:
    1: Transducer Gain Knob
    2: SIM PWR PANEL, BKLT Mode Knob
    3: EXT LIGHT PANEL, Formation & Position Lights Knob.
    Fixed naming convention of knobs to keep it organized.
    [EXT LIGHTS, Pos_Form Arrow.stl, EXT LIGHTS, Pos_Form Knob.stl, FCS PANEL, Rudder Trim Knob v2.STL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]
2023-01-02 Final LC Knobs Added
    Added 2x Pushbutton Caps for switches on the Landing Gear Panel. This should complete the required knobs for the Left Console for the moment.
    [LDG GEAR PANEL, Down Lock Oride Pushbutton Cap.stl, LDG GEAR PANEL, Warn Tone Silence Switch Cap.stl]
2023-01-02 ECS PANEL Knobs Added
    [ECS PANEL, (Version 1) - TEMP & BLEED AIR_Base Arrow.stl, ECS PANEL, (Version 1) - TEMP & BLEED AIR_Base BLackground.stl, ECS PANEL, (Version 1) - TEMP & BLEED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]
2023-01-03 WinWing Throttle Modifcation
    Added "WINWING Throttle Mod" folder under "Left Console Structure". Any modifications to the structure, regardless of material type, will be placed here as it pertains to the Winwing throttle.
    [OH4A1A1-48 - LEFT AUX SUPPORT BRACKET, LOWER, OUTBOARD.stl]
2023-01-03 RC Knobs and Panels update
    1:) Added - Dual concentric Pot assembly (used in 2 panels on the right side. Parts for assembly are split between the COTS folder and Assembly folder titled ASSY, DUAL CONCENTRIC SHAF POTENTIOMETER.
    2:) Added - Defog lever and a few more knobs needed on the right console.
    3:) Added - Inboard Wall support for Left Console. Used in the front right corner of the Left Console on the floor to help attach left inboard wall.
    [615242_A - GEAR, SERVOCITY, .250 SHAFT, 8x32_Tapped.stl, 615258_A - GEAR, PINION, 32P, 6MM BORE, 8-32_Tapped, SERVOCITY.stl, 6338K411 - SLEEVE BEARING FOR .250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]
2023-01-04 Added: L/R Console Legend Panels for engraving
    Added .stl and .svg's for various panels
    [OH5A2A4-13 - RALT DIAL FACE.stl, OH5A2A5-10 - HYD PRESS FACE.stl, OH5A4A1-104 - BATT VOLT BEZEL FACE.stl]
2023-01-06 PCB Renaming
    Since the name of the projects included "PCB, [NAME PANEL]", anytime manufacturing files or anything were created, it named all of the file within the project the same. This includes the BOM and CPL 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
    Also, having "PCB" included in the name of the PCB, under a folder called "PCBs" with in the Electrical CAD folder, seemed kind of ..... redundant.
    Looks cleaner and easier to navigate by removing PCB from the front. Each project is being saved as a new project with a new name, which automatically changes the name of each file within its subdire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
    [ANT SEL Backplate.DXF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]
2023-01-06 ECM-DISP CPL File Update.
    [CPL-ECM DISP PANEL.csv, ECM DISP PANEL-CuBottom.gbr, ECM DISP PANEL-CuTop.gbr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]
2023-01-06 Manufacturing File Update
    APU
    ANT SEL
    [ANT SEL PANEL-CuBottom.gbr, ANT SEL PANEL-CuTop.gbr, ANT SEL PANEL-EdgeCuts.gbr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]
2023-01-06 Manufacturing File Update
    CAUTION LIGHTS PANEL
    AV COOL PANEL
    [AV COOL PANEL-CuBottom.gbr, AV COOL PANEL-CuTop.gbr, AV COOL PANEL-EdgeCuts.gbr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]
2023-01-07 Manufacturing File Update #3
    COMM
    DEFOG
    ECM DISP
    ECS
    ELEC
    EXT LT
    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
    [BOM_BOTTOM-ELEC PANEL.csv, BOM_BOTTOM-EXT LT PANEL.csv, BOM_BOTTOM-FCS PANEL.csv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]
2023-01-07 Manufacturing File Update #3
    HUD VID RCD
    HYD ISO
    INTR LT
    JETT STATION SELECT PLACARD
    KY-58
    LANDING GEAR PANEL
    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
    [BOM_BOTTOM-HUD VID RCD PANEL.csv, BOM_BOTTOM-HYD ISO PANEL.csv, BOM_BOTTOM-INTR LT PANEL.csv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]
2023-01-07 Manufacturing File Update #4
    OBOGS
    SELECT JETT
    SIM CONTROL
    SIM POWER
    SNSR
    SPIN RCV
    [BOM_BOTTOM-OBOGS PANEL.csv, BOM_BOTTOM-SELECT JETT PANEL.csv, BOM_BOTTOM-SIM CONTROL PANEL.csv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]
2023-01-09 Knob/Panel Update
    Added: A few more Right Console Knobs
    Removed: Duplicate Panel Lightburn files from left console
    [CONDUCTOR PM PLUG ASSEMBLY.stl, CONDUCTOR PM PLUG Housing.stl, INT LT PANEL, Flood & WarnCaution Arrow.stl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]
2023-01-10 ECAD Directory update.
    [ABSIS_ALE Relay Module-CuBottom.gbr, ABSIS_ALE Relay Module-CuTop.gbr, ABSIS_ALE Relay Module-EdgeCuts.gbr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]
2023-01-13 Right Console Panel/Knob Update
    Added INS/RDR Knobs
    Added modified Panels
    [SNSR PANEL, INS Arrow.stl, SNSR PANEL, INS Blackground.stl, SNSR PANEL, INS Knob.stl]
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2023-01-14 PDU Removal
    ABSIS_PDU was replaced by ABSIS_ATX_PSU
    [ABSIS_Power Distribution Unit-B_Cu.gbr, ABSIS_Power Distribution Unit-B_Mask.gbr, ABSIS_Power Distribution Unit-B_Paste.gbr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]
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2023-02-10 Huge ECAD push
    [ABSIS_ALE Relay Module.step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]
2023-03-08 Software Test
    [OHParts.xlsx, OpenHornet PCB Master BOM.xlsx]
2023-03-20 Test (broken code)
    Used for reference to fix new script
    [OH PCB Database.xlsx, OH PCB Master BOM.xlsx, OHParts.xlsx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]
2023-04-01 software update
    Use of Arduino IDE and Platform IO. Adjusted file structure to match.
    [OH4A3A1-11 - SELECT JETT BACKPLATE.dxf, SPIN RCV PANEL.kicad_pcb, SPIN RCV PANEL.step]
2023-04-02 Added BATT VOLT INDICATOR
    [OH5A4A1-101 - BATT VOLT CASE.stl, OH5A4A1-103 - BATT VOLT SPACER.stl, OH5A4A1-105 - BATT VOLT NEEDLE #1.stl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]
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2023-04-25 Added Bleed Air Assembly to MCAD
    [61520 - GEAR, PINION, .250 BORE, 32 PITCH, .75 PD, 24T.stl, 6389K231 - BEARING, SLEEVED, FLANGED, .375 OD X .25 ID X .31 v2.stl, 92503A180 - WASHER, #6 X 0.56 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]

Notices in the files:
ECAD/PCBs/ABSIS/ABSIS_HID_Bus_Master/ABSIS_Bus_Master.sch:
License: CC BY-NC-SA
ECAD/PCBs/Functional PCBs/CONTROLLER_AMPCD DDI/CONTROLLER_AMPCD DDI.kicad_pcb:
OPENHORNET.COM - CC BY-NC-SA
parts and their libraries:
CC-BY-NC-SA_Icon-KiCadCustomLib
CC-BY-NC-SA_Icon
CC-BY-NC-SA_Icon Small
